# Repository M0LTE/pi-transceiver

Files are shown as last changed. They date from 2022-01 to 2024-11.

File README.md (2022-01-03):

# pi-transceiver
An attempt to build a complete ham radio transceiver around a Raspberry Pi



See [the wiki](https://github.com/M0LTE/pi-transceiver/wiki) for a more detailed project description / scratchlist of ideas / plans.

Also see [the open issues](https://github.com/M0LTE/pi-transceiver/issues) for stuff which needs working on. I've marked a few as Good First Issues.

[Discussions](https://github.com/M0LTE/pi-transceiver/discussions) is also a good place to ask questions / make comments / suggestions without raising an issue.

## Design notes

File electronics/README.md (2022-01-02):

# pi-transceiver / electronics
Here is a folder for electronics parts of the Pi transceiver, e.g. PCBs

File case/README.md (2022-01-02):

# pi-transceiver / case
Here is a folder for the case, which is intended to be 3D-printable.

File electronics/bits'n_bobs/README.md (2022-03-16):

# Bits'n_bobs
This is a collection of small prototype modules and breakout boards to test various devices and features for the Pi Transceiver and similar projects.

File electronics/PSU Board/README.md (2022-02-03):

# pi-transceiver / electronics / PCB Board
Here is a the PSU board. 13.8V input with over voltage an reverse polarity protection and multiple outputs.
Momentary switch connection for power on.
Multiple shutdown connections to enable Raspberry Pi to switch off the power and also allow any other monitoring systems to cut the power.
5V buck converter to supply power to the Raspberry Pi.
Low current permanent 5V supply (not over voltage protected) to power 3rd party modules which have the ability to directly power the system on and off.

Mouser Parts List
https://www.mouser.com/ProjectManager/ProjectDetail.aspx?AccessID=8b7ab50ecd

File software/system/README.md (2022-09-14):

# pi-transceiver / software / system
Here is a folder for scripts etc to build the system 
Notes added by G4CDF based on experience following these instructions

## Install notes 2022-02-09

Complete from-the-ground-up build of a working system.

It is highly recommended to copy-paste these commands into a remote connection rather than typing them in by hand on the Pi.
G4CDF> To paste into PuTTY just right click on the line rather than the usual CTRL V.

This will result in a system without a graphical desktop interface, which is the same as how the system will run once the radio software is installed.

### Prepare the micro SD card
1. Download latest Raspberry Pi Imager https://www.raspberrypi.com/software/
1. Choose OS -> Raspberry Pi OS (other) -> Raspberry Pi OS Lite (32-bit) - Bullseye 2022-01-28

G4CDF> I installed the full 32 bit version to a 32 GB SD card

1. Choose storage -> pick micro SD card, which you have inserted
1. Click the Cog icon
   1. Set hostname: e.g. pi-transceiver
   1. Enable SSH, use password auth
   1. Set username and password - pick whatever you want
   1. Configure wi-fi if desired
   1. Click save
1. Click Write, then click Yes, and wait

G4CDF>  These settings can be made on the Raspberry PI GUI  

### First boot

1. Plug in a network cable if you didn't configure Wi-Fi
1. Plug in a screen - either the official touchscreen or an HDMI monitor
1. Insert the micro SD card
1. Power up the Pi
1. Wait until you see a login prompt
1. Connect to the Pi using your favourite SSH client. PuTTY is fine on Windows. Log in using the username and password you set earlier. The default username is "pi"
1. Issue the command `sudo apt update; sudo apt full-upgrade -y` and wait until completion

G4CDF>  SSH will not work with host name only IP address

### Install GNU Radio and LimeSDR components

There is no GNU Radio PPA for Raspberry Pi OS either for Buster or Bullseye as it stands.

1. Install GNU Radio by issuing the command:

```
sudo apt install gnuradio -y
```

2. Install LimeSuite by issuing the commands:
```
sudo apt install -y git g++ cmake libsqlite3-dev libsoapysdr-dev libi2c-dev libusb-1.0-0-dev
cd ~
git clone https://github.com/myriadrf/LimeSuite.git
cd LimeSuite
git checkout stable
mkdir builddir && cd builddir
cmake ../
make -j4
sudo make install
sudo ldconfig
cd ~/LimeSuite/udev-rules
sudo ./install.sh
```

3. Install the LimeSDR plugin for GNU Radio by issuing the commands:

```
cd ~
git clone https://github.com/myriadrf/gr-limesdr.git
cd gr-limesdr
git checkout gr-3.8
mkdir build
cd build
cmake ..
make
sudo make install
sudo ldconfig
```

### Install .NET 6

1. Issue the command

```
wget -O - https://raw.githubusercontent.com/pjgpetecodes/dotnet6pi/master/install.sh | sudo bash
```
2. Reboot by issuing the command `sudo reboot`
3. Connect back up to the Pi using SSH once it has rebooted

### Enable I2C

I2C is not enabled by default. Enable it by running `sudo raspi-config` on the Pi, then selecting Interface Options, I2C, Enable. No need to reboot.

### Run the rig controller software

To fetch a working copy of the software:

```
cd ~
git clone https://github.com/M0LTE/pi-transceiver.git
```

To update the software:

```
cd ~/pi-transceiver
git pull
```

To run the software in the foreground (NB there will be no touchscreen UI since the screen will be used for console output - useful for debugging):

```
cd ~/pi-transceiver/software/rig-controller/rig-controller/
dotnet run
```

Then on a second computer on the same network, open http://pi-transceiver:5155 in a web browser. You'll get the radio UI.

G4CDF>  Windows 10 machine cannt see the Raspberry PI for some reason.

NOTE: as above - in the final product, this radio UI will be on the touchscreen.

Instructions on setting up the software to run in the background and display the UI on the touchscreen (or HDMI monitor) will follow.

## Hardware

- When connecting the official touchscreen, the only connections should be VCC, ground, and the ribbon cable. Nothing more. Else you are bridging two I2C buses which will have unpredictable effects.

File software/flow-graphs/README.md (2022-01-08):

# pi-transceiver / software / flow-graphs

SSB_TX.grc is the most basic audio capture -> SSB transmitter I can conceive of in GNU Radio. It can be loaded into GNU Radio Companion 3.8 with gr-limesdr installed. Just set the lime_serial variable (block) value to the serial number of your own LimeSDR, found by running `LimeUtil --find` at the terminal. Click Run, and you'll find a signal at 144.400MHz USB +/- calibration. 

Default gain is 60 (who knows what units), frequency is set in the LimeSDR block.

Tested on Ubuntu 20.04 + GNU Radio installed by following [these (Installing via PPA) instructions](https://github.com/myriadrf/gr-limesdr#linux)

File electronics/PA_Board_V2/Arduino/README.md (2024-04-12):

# Arduino Support for Pi Transciever PA Board
# Arduino Support for Pi Transciever PA Board

The Pi Transceiver PA board is programmed under the Arduino IDE environment with Arduino Libraries

## Test programs

    - Blink - Basic test to verify CPU operation with RGB LED and watchdog LED

    - I2C Scanner - Find I2c devices on Internal and External I2C buses

    - OLED Test - Test of optional I2C OLED display

    - Temperature - Show temperature of LM75B sensor

    - Power_Tests - Test Vdd, Idd, Vgg Monitor
    
    - fan_PWM - test speed control of fan

    - USB_Commander - a command interpreter interface to set and read all parameters of the PA and receiver boards

## Libraries Used

    - "FlashStorage_SAMD"  used to support non voltaile storage from application into Flash memory as there is no EEPROM on ATSAMD21E18

    - "Adafruit_INA219" used to support the INA219 voltage and current sensor for Vdd and Idd to the RF Block

    - "Adafruit_MCP4725" used to support the DAC used to set the Vgg voltage

    - "Commander" used to provide command interpreter function on USB or TTL Serial port

    - "Adafruit_Neopixel"  used to support the onboard DotStar RGB LED

    - "Temperature_LM75_Derived" used to support the onboard LM75B temperature sensor

    - "Adafruit_SSD1306" and "Adafruit GFX" are Used to support the optional 128 * 64 pixel monochrome I2C LCD display

    - "PCF8574" is used to support the receiver board I2C interface IC

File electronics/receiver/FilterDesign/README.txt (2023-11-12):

This folder contains the design of the filter within the Receiver PCB, including documents used to design and simulate the band pass flter.

The filter is a 4 pole band pass filter covering 144 to 147 MHz and is used on both transmit and receive

It is designed using the book by Zverev entitled Handbook of Filter Synthesis.  An Excel spreadsheet is used to calculate the values and it provides output to QUCS and Kicad.

Note for QUCS the output worksheet is save in .prn format and this is then renamed to .sch.  It is necessary for filter.dpl to be put in gitignore if using git.
When siluation is completed export the schematic and simualtion results.

Currently the values are input to Kicad manually.

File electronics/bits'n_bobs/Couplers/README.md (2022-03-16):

# Coupler

Directional coupler modules to test different options for the Pi Transceiver

The coupler is a short PCB directional coupler using Guerilla GRF1201 detctors

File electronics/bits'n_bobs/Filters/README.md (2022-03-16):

# Filters

A selection of Filter modules to test different options for the Pi Transceiver

The Filters are:

* RBP-140+ - A breakout for the Minicircuits RBP-140+ bandpass filter module
* Broadcast_filter - A copy of the broadcast notch filter used in the Line RFE board
* LowPass_7mm - Low pass transmit filter using hand would coils
* LowPass_10mm - Low pass filter using Toko coil formers

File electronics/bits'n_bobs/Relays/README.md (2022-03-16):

# Relays

A selection of Relay modules to test different options for the Tx/Rx relay for the Pi Transceiver

Relay Options are:

* G2RL Large through hole relay recommended by W6PQL
* HF3 Surface mount relay recommended by W6PQL
* EE2 Surface mount relay used in Lime RFE and IC-9700
* G6E Through hole relay used in Elecraft XV144

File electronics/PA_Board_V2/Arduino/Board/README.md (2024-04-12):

# Board Files for Pi Transciever PA Board

The Arduino environment uses board files and variants to configure for different processors and board pinouts.
We use the board files for the Adafruit SAMD boards and modify to add Pi transceiver board. (This is a bit messy and could be improved with proper custom board files when stable)

## Installation

- Install the latest arduino IDE: [Install IDE 2](https://docs.arduino.cc/software/ide-v2/tutorials/getting-started/ide-v2-downloading-and-installing)

- Install the Adafruit SAMD board support into Arduino board manager [Adafruit SAMD](https://learn.adafruit.com/adafruit-trinket-m0-circuitpython-arduino/arduino-ide-setup)

- Install the Adafruit SAMD boards inside Arduino Board Manager [Board Manager](https://learn.adafruit.com/adafruit-trinket-m0-circuitpython-arduino/using-with-arduino-ide) Follow this tutorial until the point where you have reboted the PC then stop.

- Find where the board files have been installed. There will be a directory like this "C:\Users\'your_user_name'\AppData\Local\Arduino15\packages\adafruit\hardware\samd\1.7.10" which contains a file "boards.txt" and "variants" directory.

- Replace the "boards.txt" file in the directory found above with the one in this Github directory.

- Add the "Pi_Tx_PA" and the "Pi_Tx_PA_V2" directories from the "Board/variants" of this Github repository. into the variants directory found above.

- Restart PC and open Arduino IDE

- Plug in Pi Transceiver PA board to PC using USB connection. PC should enumerate the board.

- Select Board type as RADARC Pi_Tx_PA under "tools/board/Adafruit SAMD"

- Select the Comport which shows the RADARC Pi_Tx_PA connected

- Add the additional Arduino Libraries listed in the READ_ME if not already installed.

-  Compile and Upload code or tests from this Github repository

## Issues

1.  If you subsequently update the Adafruit Boards in board manager then the "boards.txt" will most likely be changed by the update and the steps above to replace the boards.txt with our version will have to done again. Best to not update the Adafruit SAMD boards when offered.

2. The Pi_Tx_PA has the same USB VID and PID as the Adafruit Trinket M0 and the Adafruit PiRkey (SAMD) which means the serial port often needs to be reset to the correct COM Port. This may be fixed by Arduino/Adafruit or may been a custom bootlodare with unique VID PID

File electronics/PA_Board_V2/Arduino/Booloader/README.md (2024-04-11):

# Bootloader for Pi Transciever PA Board

The Bootloader for the Atmel ATSAMD21E18 processor is the same bootloader used on the Adafruit Trinket M0 which uses the same processor

The .bin file bootloader file is programmed into the ATSAMD21E18 using Atmel Studio and an Atmel ICE or similar SWD programmer. The connection to the debug pins on the PA Board is made using a 3d printed programming clip with pogo pins.

The Bootloader area should be locked after programming.
    After flashing, you'll need to set the BOOTPROT fuse back to a 8kB bootloader size.
    From Fuses, set BOOTPROT to 0x2 or 8KB and click Program

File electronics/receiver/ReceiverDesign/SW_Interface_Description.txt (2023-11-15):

Software Interface Description for Pi-transcever Reeciver Module

Control of the receiver module (Rx Module) is via the I2C bus.

The Rx Module is an I2C bus slave.  The device used is a PCF8574AT, Datasheet is in /datasheets as PCF8574_PCF8574A-3139141.

Address=  01110000 

Data=  Data_gain OR Data_Tx_state

Data_gain=  00000001 (Rx_gain = 13dB)
Data_gain=  00000010  (Rx_gain = -10 dB)

For LimeSDR Mini:

Data_Tx_state=  00011000 (Transmit state)
Data_Tx_state=  00100100 (Receive state)

For Caribou Lite:

Data_Tx_state=  00011000 (Transmit state)
Data_Tx_state=  00010100  (Receive state)

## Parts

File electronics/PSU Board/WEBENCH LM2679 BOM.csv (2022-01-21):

Part | Manufacturer | Part Number | Quantity | Price ($) | Footprint (mm²) | Description
Rilim | Vishay-Dale | CRCW04024K99FKED | 1 | 0.01 | 3 | Resistance: 4.99 kΩ Tolerance: 1.0% Power: 63 mW
Rfb1 | Vishay-Dale | CRCW04021K00FKED | 1 | 0.01 | 3 | Resistance: 1 kΩ Tolerance: 1.0% Power: 63 mW
Rfb2 | Vishay-Dale | CRCW04023K24FKED | 1 | 0.01 | 3 | Resistance: 3.24 kΩ Tolerance: 1.0% Power: 63 mW
Cout | Panasonic | 16SVP330M | 1 | 0.4 | 159.9 | Cap: 330 µF Total Derated Cap: 330 µF VDC: 16 V ESR: 16 mΩ Package: 10x12.6
D1 | SMC Diode Solutions | SBRD10200TR | 1 | 0.12 | 101.71 | Type: Schottky VRRM: 200 V Io: 10 A
Cb | TDK | CGA4C2C0G1H103J060AA | 1 | 0.06 | 6.75 | Cap: 10 nF Total Derated Cap: 10 nF VDC: 50 V ESR: 0 Ω Package: 0805
L1 | Bourns | SRP1270-100M | 1 | 0.72 | 246.49 | L: 10 µH DCR: 16.8 mΩ IDC: 10 A
Cinx | Kemet | C0805C104M5RACTU | 1 | 0.01 | 6.75 | Cap: 100 nF Total Derated Cap: 100 nF VDC: 50 V ESR: 64 mΩ Package: 0805
U1 | Texas Instruments | LM2679SX-ADJ/NOPB | 1 | 2.481 | 198.82
Cin | Panasonic | 25SVPF180M | 1 | 0.63 | 106.09 | Cap: 180 µF Total Derated Cap: 180 µF VDC: 25 V ESR: 16 mΩ Package: 8x11.9
Css | TDK | CGA4C2C0G1H103J060AA | 1 | 0.06 | 6.75 | Cap: 10 nF Total Derated Cap: 10 nF VDC: 50 V ESR: 0 Ω Package: 0805

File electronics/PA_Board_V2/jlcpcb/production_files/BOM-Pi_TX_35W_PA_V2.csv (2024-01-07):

Comment | Designator | Footprint | LCSC
LRB751S | D11,D12,D2,D3 | D_SOD-523 | C113407
USB_B_Micro | J9 | USB_Micro-B_Molex-105017-0001 | C136000
INA219AxD | U10 | SOIC-8_3.9x4.9mm_P1.27mm | C138706
1.5u | L10,L8 | L_0805_2012Metric | C139220
MCP4725 | U7 | SOT-23-6 | C144198
G6E | K1 | Relay_SPDT_Omron_G6E | C1525391
1u 50V | C26 | C_0603_1608Metric | C15849
22u | C13 | CP_EIA-7343-43_Kemet-X | C1956447
TPS22810DBV | U8 | SOT-23-6 | C205990
1k | R14,R42,R44 | R_0603_1608Metric | C21190
10n | C55,C56,C60 | C_0603_1608Metric | C2215227
1k2 | R12 | R_0603_1608Metric | C22765
150R | R22,R23,R38,R40 | R_0603_1608Metric | C22808
10R | R7,R8 | R_0603_1608Metric | C22859
1M | R43 | R_0603_1608Metric | C22935
330R | R30,R37 | R_0603_1608Metric | C23138
4k7 | R1,R16,R18,R24,R25,R28,R35,R45,R5,R6 | R_0603_1608Metric | C23162
470R | R13 | R_0603_1608Metric | C23179
49.9k | R41 | R_0603_1608Metric | C23184
49.9R | R39 | R_0603_1608Metric | C23185
18R | R2,R49 | R_0603_1608Metric | C245924
100k | R29,R31,R32,R34 | R_0603_1608Metric | C25803
10k | R10,R11,R15,R19,R26,R27,R33,R36,R46,R47 | R_0603_1608Metric | C25804
47k | R21 | R_0603_1608Metric | C25819
22.1k | R17 | R_0603_1608Metric | C25961
AP2204K-ADJ | U9 | SOT-23-5 | C264072
SP0503BAHT | D1,D5,D8 | SOT-143 | C2682275
TLV70233 | U11 | SOT-23-5 | C26833
1n | C35,C36,C43,C47,C50,C51 | C_0603_1608Metric | C2839443
150mA | F2,F3,F4 | Fuse_0805_2012Metric | C2840556
200nH | L4 | L_1812_4532Metric | C2858475
SK6812 | D14,D15 | SK6812SIDE-A-RVS | C2890037
300R | R3,R4,R48,R50 | R_0603_1608Metric | C2930092
LM2904 | U12 | SOIC-8_3.9x4.9mm_P1.27mm | C2941725
100p | C1,C11,C16,C59,C7 | C_0603_1608Metric | C296046
162k | R20 | R_0603_1608Metric | C3016073
MBR0540 | D4,D7,D9 | D_SOD-123 | C3018524
2.2u 50V | C23 | C_0805_2012Metric | C377773
330p | C3,C5,C64,C9 | C_0603_1608Metric | C458903
Conn_Coaxial | J1,J5,J7,J8 | SMA_Samtec_SMA-J-P-X-ST-EM1_EdgeMount | C496550
74LV1T34 | U15,U5 | SOT-353_SC-70-5 | C5199768
PSA4-5043+ | U1,U3 | MM1362 PSA4-5043+ | C5240848
AOD4185 | Q1 | TO-252-2 | C5261064
SW_Push | SW1 | Panasonic_EVQPUK_EVQPUB | C526225
LMR51420 | U6 | SOT-23-6 | C5383002
BC848W | Q2 | SOT-323_SC-70 | C549496
4n7 | C53 | C_0603_1608Metric | C576815
2.2u | C22 | C_0603_1608Metric | C57895
22u | C31,C6 | C_0805_2012Metric | C602037
ATSAMD21E18A-A | U13 | TQFP-32_7x7mm_P0.8mm | C618770
1SS400 | D10,D17,D6 | D_SOD-523 | C68951
MHS171CRCT | D16 | MHS171 | C693903
MHS171UBCT | D13 | MHS171 | C693906
1u | L1,L11,L12,L13,L2 | L_0805_2012Metric | C703134
LM75B | U2 | SOIC-8_3.9x4.9mm_P1.27mm | C725792
Conn_01x05 | J3 | JST_PH_S5B-PH-SM4-TB_1x05-1MP_P2.00mm_Horizontal | C7429692
Conn_01x06 | J6 | JST_PH_S6B-PH-SM4-TB_1x06-1MP_P2.00mm_Horizontal | C7429693
4.7uH | L5 | L_7.3x7.3_H3.5 | C76857
10m | R9 | R_2816_7142Metric | C843884
100n | C10,C14,C17,C18,C2,C21,C24,C25,C27,C28,C29,C30,C38,C39,C4,C42,C45,C46,C48,C54,C58,C8 | C_0603_1608Metric | C88136
1u | C37,C40,C44,C52,C57 | C_0603_1608Metric | C89376
1A | F1 | Fuse_1206_3216Metric | C910830
10u | C41,C49 | C_0603_1608Metric | C96446
L_Ferrite | L9 | L_0603_1608Metric | C98298

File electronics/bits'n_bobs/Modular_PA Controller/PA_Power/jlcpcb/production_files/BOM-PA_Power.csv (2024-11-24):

Comment | Designator | Footprint | LCSC
MountingHole_Pad | H5 | MountingHole_3.2mm_M3_DIN965_Pad
NF | R25 | R_0603_1608Metric
82R | R8 | R_0603_1608Metric
1uH | L9 | L_0805_2012Metric
1A | F4 | Fuse_1812_4532Metric
JST-XH-4 | J5 | JST_XH_S4B-XH-A_1x04_P2.50mm_Horizontal
FDN340P | Q5 | SOT-23
JST-XH-4 | J6 | JST_XH_S4B-XH-A_1x04_P2.50mm_Horizontal
100n | C25 | C_0603_1608Metric
0R | R32 | R_0603_1608Metric
100n | C22 | C_0603_1608Metric
10k | TH1 | R_0603_1608Metric
1k8 | R34 | R_0603_1608Metric
AP2204K-ADJ | U7 | SOT-23-5
1A | F1 | Fuse_Schurter_UMZ250
15uH | L1 | L_Wuerth_MAPI-4030
NF | R24 | R_0603_1608Metric
LMR38020 | U3 | lmr38012
PCF8574A | U8 | SOIC-16W_7.5x10.3mm_P1.27mm
4k7 | R27 | R_0603_1608Metric
10k | R37 | R_0603_1608Metric
1uH | L8 | L_0805_2012Metric
Green | D4 | LED_0603_1608Metric
64k9 | R3 | R_0603_1608Metric
1uH | L6 | L_0805_2012Metric
2.2u | C7 | C_1210_3225Metric
SQM120P10-19L | Q3 | TO263_Heatsink_301
82R | R9 | R_0603_1608Metric
10k | R7 | R_0603_1608Metric
100n | C16 | C_0603_1608Metric
100n | C20 | C_0603_1608Metric
JST-XH-2 | J7 | JST_XH_S2B-XH-A_1x02_P2.50mm_Horizontal
NF | R31 | R_0603_1608Metric
10k | R30 | R_0603_1608Metric
ADS1015IDGS | U5 | TSSOP-10_3x3mm_P0.5mm
110k | R15 | R_0603_1608Metric
1k | R5 | R_0603_1608Metric
60A 4 Pin | J4 | Fat_Power 4
10k | R36 | R_0603_1608Metric
1uH | L4 | L_0805_2012Metric
100nf | C8 | C_0603_1608Metric
2.2u | C6 | C_1210_3225Metric
10K | R4 | R_0603_1608Metric
1k | R28 | R_0603_1608Metric
100nf | C9 | C_0603_1608Metric
100n | C3 | C_0805_2012Metric
2.2u | C4 | C_0603_1608Metric
100n | C24 | C_0603_1608Metric
100n | C29 | C_0603_1608Metric
22.1k | R14 | R_0603_1608Metric
22u | C11 | C_1210_3225Metric
MountingHole_Pad | H2 | MountingHole_3.2mm_M3_DIN965_Pad
22.1k | R11 | R_0603_1608Metric
100k | R13 | R_0603_1608Metric
4k7 | R6 | R_0603_1608Metric
SMF4L5.0A | D13 | D_SOD-123F
60A 4 pin | J1 | Fat_Power 4
0R | R20 | R_0603_1608Metric
270k | R1 | R_0603_1608Metric
33uH | L3 | L_Coilcraft_MSS1210-XXX
100n | C21 | C_0603_1608Metric
NF | R19 | R_0603_1608Metric
10k | R16 | R_0603_1608Metric
1k | R17 | R_0603_1608Metric
1uH | L7 | L_0805_2012Metric
2.2u | C5 | C_0603_1608Metric
LMR50410 | U2 | SOT-23-6
1k | R21 | R_0603_1608Metric
ACS770xCB-050B-PFF | U4 | Allegro_CB_PFF
4k7 | R23 | R_0603_1608Metric
SMF4L5.0A | D8 | D_SOD-123F
MCP4725A0T | U6 | SOT-23-6
SMF4L12A | D9 | D_SOD-123F
LMR50410 | U1 | SOT-23-6
10k | R35 | R_0603_1608Metric
SMF4L5.0A | D7 | D_SOD-123F
SM6T75A | D1 | D_SMB
162k | R10 | R_0603_1608Metric
100n | C14 | C_0603_1608Metric
10k | R18 | R_0603_1608Metric
10k | R2 | R_0603_1608Metric
1A | F2 | Fuse_1812_4532Metric
MountingHole_Pad | H3 | MountingHole_3.2mm_M3_DIN965_Pad
100n | C26 | C_0603_1608Metric
100n | C30 | C_0603_1608Metric
JST-PH-4 | J3 | JST_PH_B4B-PH-SM4-TB_1x04-1MP_P2.00mm_Vertical
15uH | L2 | L_Wuerth_MAPI-4030
1k8 | R29 | R_0603_1608Metric
100n | C23 | C_0603_1608Metric
4k7 | R22 | R_0603_1608Metric
BSS123 | Q1 | SOT-23
1A | F5 | Fuse_1812_4532Metric
JST-PH-4 | J8 | JST_PH_B4B-PH-SM4-TB_1x04-1MP_P2.00mm_Vertical
100nf | C10 | C_0603_1608Metric
1k | R33 | R_0603_1608Metric
100n | C15 | C_0603_1608Metric
MountingHole_Pad | H4 | MountingHole_3.2mm_M3_DIN965_Pad
0R | R26 | R_0603_1608Metric
100k | R12 | R_0603_1608Metric
30A 2 Pin | J2 | Fat_Power 2
100n | C1 | C_0603_1608Metric
1A | F3 | Fuse_1812_4532Metric
1uH | L5 | L_0805_2012Metric
22u | C17 | C_1210_3225Metric
100n | C2 | C_0603_1608Metric
MountingHole_Pad | H1 | MountingHole_3.2mm_M3_DIN965_Pad
JST-PH-3 | J9 | JST_PH_S3B-PH-SM4-TB_1x03-1MP_P2.00mm_Horizontal
SQM120P10-19L | Q2 | TO263_Heatsink_301
BSS123 | Q4 | SOT-23
15v | D2 | Nexperia_CFP3_SOD-123W
SMF4L12A | D14 | D_SOD-123F
Yellow | D12 | LED_0603_1608Metric
SP0503BAHT | D11 | SOT-143
Blue | D10 | LED_0603_1608Metric
SMF4L12A | D6 | D_SOD-123F
SM6T75A | D5 | D_SMB
Red | D3 | LED_0603_1608Metric
100n | C28 | C_0603_1608Metric
22u | C27 | C_0805_2012Metric
22u | C18 | C_1210_3225Metric
100n | C19 | C_0603_1608Metric
22u | C12 | C_1210_3225Metric
100n | C13 | C_0603_1608Metric

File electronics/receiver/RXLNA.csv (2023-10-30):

Source: | C:\Users\micha\SynologyDrive\Documents\KICAD\Projects\RXLNA\RXLNA.kicad_sch
Date: | 21/10/2023 12:44
Tool: | Eeschema (6.0.9)
Generator: | C:\Program Files\KiCad\6.0\bin\scripting\plugins/bom_csv_grouped_by_value.py
Component Count: | 86
Individual Components:
Item | Qty | Reference(s) | Value | LibPart | Footprint | Datasheet
 |  | C401 | C | Device:C | Capacitor_SMD:C_0805_2012Metric | ~
 |  | C402 | C | Device:C | Capacitor_SMD:C_0805_2012Metric | ~
 |  | C403 | C | Device:C | Capacitor_SMD:C_0805_2012Metric | ~
 |  | C404 | C | Device:C | Capacitor_SMD:C_0805_2012Metric | ~
 |  | C405 | C | Device:C | Capacitor_SMD:C_0805_2012Metric_Pad1.18x1.45mm_HandSolder | ~
 |  | C406 | C | Device:C | Capacitor_SMD:C_0805_2012Metric_Pad1.18x1.45mm_HandSolder | ~
 |  | C407 | C | Device:C | Capacitor_SMD:C_0805_2012Metric_Pad1.18x1.45mm_HandSolder | ~
 |  | C408 | C | Device:C | Capacitor_SMD:C_0805_2012Metric_Pad1.18x1.45mm_HandSolder | ~
 |  | C409 | C | Device:C | Capacitor_SMD:C_0805_2012Metric_Pad1.18x1.45mm_HandSolder | ~
 |  | C410 | C | Device:C | Capacitor_SMD:C_0805_2012Metric | ~
 |  | C411 | C | Device:C | Capacitor_SMD:C_0805_2012Metric_Pad1.18x1.45mm_HandSolder | ~
 |  | C412 | C | Device:C | Capacitor_SMD:C_0805_2012Metric | ~
 |  | C413 | C | Device:C | Capacitor_SMD:C_0805_2012Metric_Pad1.18x1.45mm_HandSolder | ~
 |  | C414 | C | Device:C | Capacitor_SMD:C_0805_2012Metric_Pad1.18x1.45mm_HandSolder | ~
 |  | C415 | C | Device:C | Capacitor_SMD:C_0805_2012Metric | ~
 |  | C416 | C | Device:C | Capacitor_SMD:C_0805_2012Metric | ~
 |  | C417 | C | Device:C | Capacitor_SMD:C_0805_2012Metric | ~
 |  | C418 | C | Device:C | Capacitor_SMD:C_0805_2012Metric | ~
 |  | C419 | C | Device:C | Capacitor_SMD:C_0805_2012Metric | ~
 |  | C420 | C | Device:C | Capacitor_SMD:C_0805_2012Metric | ~
 |  | C421 | C | Device:C | Capacitor_SMD:C_0805_2012Metric | ~
 |  | C422 | C | Device:C | Capacitor_SMD:C_0805_2012Metric_Pad1.18x1.45mm_HandSolder | ~
 |  | C423 | C | Device:C | Capacitor_SMD:C_0805_2012Metric_Pad1.18x1.45mm_HandSolder | ~
 |  | C424 | C | Device:C | Capacitor_SMD:C_0805_2012Metric_Pad1.18x1.45mm_HandSolder | ~
 |  | C425 | C | Device:C | Capacitor_SMD:C_0603_1608Metric_Pad1.08x0.95mm_HandSolder | ~
 |  | C426 | C | Device:C | Capacitor_SMD:C_0603_1608Metric_Pad1.08x0.95mm_HandSolder | ~
 |  | C427 | C | Device:C | Capacitor_SMD:C_0603_1608Metric_Pad1.08x0.95mm_HandSolder | ~
 |  | C428 | C | Device:C | Capacitor_SMD:C_0603_1608Metric_Pad1.08x0.95mm_HandSolder | ~
 |  | C429 | C_Trim | Device:C_Trim | G4CDF:TrimCap | ~
 |  | C430 | C | Device:C | Capacitor_SMD:C_0603_1608Metric_Pad1.08x0.95mm_HandSolder | ~
 |  | C431 | C | Device:C | Capacitor_SMD:C_0603_1608Metric_Pad1.08x0.95mm_HandSolder | ~
 |  | C432 | C | Device:C | Capacitor_SMD:C_0603_1608Metric_Pad1.08x0.95mm_HandSolder | ~
 |  | C433 | C | Device:C | Capacitor_SMD:C_0603_1608Metric_Pad1.08x0.95mm_HandSolder | ~
 |  | C434 | C_Trim | Device:C_Trim | G4CDF:TrimCap | ~
 |  | C435 | C | Device:C | Capacitor_SMD:C_0603_1608Metric_Pad1.08x0.95mm_HandSolder | ~
 |  | C436 | C | Device:C | Capacitor_SMD:C_0603_1608Metric_Pad1.08x0.95mm_HandSolder | ~
 |  | C437 | C | Device:C | Capacitor_SMD:C_0603_1608Metric_Pad1.08x0.95mm_HandSolder | ~
 |  | C438 | C | Device:C | Capacitor_SMD:C_0603_1608Metric_Pad1.08x0.95mm_HandSolder | ~
 |  | C439 | C_Trim | Device:C_Trim | G4CDF:TrimCap | ~
 |  | C440 | C | Device:C | Capacitor_SMD:C_0603_1608Metric_Pad1.08x0.95mm_HandSolder | ~
 |  | C441 | C | Device:C | Capacitor_SMD:C_0603_1608Metric_Pad1.08x0.95mm_HandSolder | ~
 |  | C442 | C | Device:C | Capacitor_SMD:C_0603_1608Metric_Pad1.08x0.95mm_HandSolder | ~
 |  | C443 | C | Device:C | Capacitor_SMD:C_0603_1608Metric_Pad1.08x0.95mm_HandSolder | ~
 |  | C444 | C_Trim | Device:C_Trim | G4CDF:TrimCap | ~
 |  | C445 | C | Device:C | Capacitor_SMD:C_0603_1608Metric_Pad1.08x0.95mm_HandSolder | ~
 |  | C446 | C | Device:C | Capacitor_SMD:C_0603_1608Metric_Pad1.08x0.95mm_HandSolder | ~
 |  | D401 | SMP1330-005LF | Device:D_Dual_Series_AKC_Parallel | Package_TO_SOT_SMD:SOT-23 | ~
 |  | J401 | Conn_Coaxial | Connector:Conn_Coaxial | Connector_Coaxial:SMA_Samtec_SMA-J-P-X-ST-EM1_EdgeMount | ~
 |  | J402 | Conn_Coaxial | Connector:Conn_Coaxial | Connector_Coaxial:SMA_Samtec_SMA-J-P-X-ST-EM1_EdgeMount | ~
 |  | J403 | Conn_Coaxial | Connector:Conn_Coaxial | Connector_Coaxial:SMA_Samtec_SMA-J-P-X-ST-EM1_EdgeMount | ~
 |  | J404 | Conn_01x06_Male | Connector:Conn_01x06_Male | Connector_PinHeader_2.54mm:PinHeader_1x06_P2.54mm_Vertical | ~
 |  | J405 | Conn_01x01_Male | Connector:Conn_01x01_Male | G4CDF:Board outline 100_100 | ~
 |  | J406 | Conn_Coaxial | Connector:Conn_Coaxial | Connector_Coaxial:SMA_Samtec_SMA-J-P-X-ST-EM1_EdgeMount | ~
 |  | J407 | Conn_Coaxial | Connector:Conn_Coaxial | Connector_Coaxial:SMA_Samtec_SMA-J-P-X-ST-EM1_EdgeMount | ~
 |  | L401 | L_Trim | Device:L_Trim | Inductor_THT:L_Radial_L10.2mm_W10.2mm_Px7.62mm_Py7.62mm_Pulse_LP-30 | ~
 |  | L402 | L | Device:L | Inductor_SMD:L_0805_2012Metric_Pad1.05x1.20mm_HandSolder | ~
 |  | L403 | L | Device:L | G4CDF:Pipe22 | ~
 |  | L404 | L | Device:L | G4CDF:Pipe22 | ~
 |  | L405 | L | Device:L | G4CDF:Pipe22 | ~
 |  | L406 | L | Device:L | G4CDF:Pipe22 | ~
 |  | R401 | R | Device:R | Resistor_SMD:R_0805_2012Metric_Pad1.20x1.40mm_HandSolder | ~
 |  | R402 | R | Device:R | Resistor_SMD:R_0805_2012Metric_Pad1.20x1.40mm_HandSolder | ~
 |  | R403 | R | Device:R | Resistor_SMD:R_0805_2012Metric_Pad1.20x1.40mm_HandSolder | ~
 |  | R404 | R | Device:R | Resistor_SMD:R_0805_2012Metric_Pad1.20x1.40mm_HandSolder | ~
 |  | R405 | R | Device:R | Resistor_SMD:R_0805_2012Metric_Pad1.20x1.40mm_HandSolder | ~
 |  | R406 | R | Device:R | Resistor_SMD:R_0805_2012Metric_Pad1.20x1.40mm_HandSolder | ~
 |  | R407 | R | Device:R | Resistor_SMD:R_0805_2012Metric_Pad1.20x1.40mm_HandSolder | ~
 |  | R408 | R | Device:R | Resistor_SMD:R_0805_2012Metric_Pad1.20x1.40mm_HandSolder | ~
 |  | R409 | R | Device:R | Resistor_SMD:R_0805_2012Metric_Pad1.20x1.40mm_HandSolder | ~
 |  | R410 | R | Device:R | Resistor_SMD:R_0805_2012Metric_Pad1.20x1.40mm_HandSolder | ~
 |  | R411 | R | Device:R | Resistor_SMD:R_0805_2012Metric_Pad1.20x1.40mm_HandSolder | ~
 |  | R412 | R | Device:R | Resistor_SMD:R_0805_2012Metric_Pad1.20x1.40mm_HandSolder | ~
 |  | R413 | R | Device:R | Resistor_SMD:R_0805_2012Metric_Pad1.20x1.40mm_HandSolder | ~
 |  | R414 | R | Device:R | Resistor_SMD:R_0805_2012Metric_Pad1.20x1.40mm_HandSolder | ~
 |  | R415 | R | Device:R | Resistor_SMD:R_0805_2012Metric_Pad1.20x1.40mm_HandSolder | ~
 |  | R416 | R | Device:R | Resistor_SMD:R_0805_2012Metric_Pad1.20x1.40mm_HandSolder | ~
 |  | R417 | R | Device:R | Resistor_SMD:R_0805_2012Metric_Pad1.20x1.40mm_HandSolder | ~
 |  | U401 | AS179-92LF | RF_Switch:AS179-92LF | Package_TO_SOT_SMD:SOT-363_SC-70-6 | http://www.skyworksinc.com/uploads/documents/AS179_92LF_200176H.pdf
 |  | U402 | AS179-92LF | RF_Switch:AS179-92LF | Package_TO_SOT_SMD:SOT-363_SC-70-6 | http://www.skyworksinc.com/uploads/documents/AS179_92LF_200176H.pdf
 |  | U403 | AMS1117-5.0 | Regulator_Linear:AMS1117-5.0 | Package_TO_SOT_SMD:SOT-223-3_TabPin2 | http://www.advanced-monolithic.com/pdf/ds1117.pdf
 |  | U404 | AS179-92LF | RF_Switch:AS179-92LF | Package_TO_SOT_SMD:SOT-363_SC-70-6 | http://www.skyworksinc.com/uploads/documents/AS179_92LF_200176H.pdf
 |  | U405 | AMS1117-3.3 | Regulator_Linear:AMS1117-3.3 | Package_TO_SOT_SMD:SOT-223-3_TabPin2 | http://www.advanced-monolithic.com/pdf/ds1117.pdf
 |  | U406 | PCF8574A | Interface_Expansion:PCF8574A | Package_SO:SOIC-16W_7.5x10.3mm_P1.27mm | http://www.nxp.com/documents/data_sheet/PCF8574_PCF8574A.pdf
 |  | U407 | AS179-92LF | RF_Switch:AS179-92LF | Package_TO_SOT_SMD:SOT-363_SC-70-6 | http://www.skyworksinc.com/uploads/documents/AS179_92LF_200176H.pdf
 |  | U408 | PSA4-5043 | RF_Amplifier:SPF5189Z | Package_TO_SOT_SMD:SOT-89-3 | www.qorvo.com/products/d/da001910
 |  | U409 | AS179-92LF | RF_Switch:AS179-92LF | Package_TO_SOT_SMD:SOT-363_SC-70-6 | http://www.skyworksinc.com/uploads/documents/AS179_92LF_200176H.pdf
Collated Components:
Item | Qty | Reference(s) | Value | LibPart | Footprint | Datasheet
1 | 13 | C401, C402, C403, C404, C410, C412, C415, C416, C417, C418, C419, C420, C421 | C | Device:C | Capacitor_SMD:C_0805_2012Metric | ~
2 | 11 | C405, C406, C407, C408, C409, C411, C413, C414, C422, C423, C424 | C | Device:C | Capacitor_SMD:C_0805_2012Metric_Pad1.18x1.45mm_HandSolder | ~
3 | 18 | C425, C426, C427, C428, C430, C431, C432, C433, C435, C436, C437, C438, C440, C441, C442, C443, C445, C446 | C | Device:C | Capacitor_SMD:C_0603_1608Metric_Pad1.08x0.95mm_HandSolder | ~
4 | 4 | C429, C434, C439, C444 | C_Trim | Device:C_Trim | G4CDF:TrimCap | ~
5 | 1 | D401 | SMP1330-005LF | Device:D_Dual_Series_AKC_Parallel | Package_TO_SOT_SMD:SOT-23 | ~
6 | 5 | J401, J402, J403, J406, J407 | Conn_Coaxial | Connector:Conn_Coaxial | Connector_Coaxial:SMA_Samtec_SMA-J-P-X-ST-EM1_EdgeMount | ~
7 | 1 | J404 | Conn_01x06_Male | Connector:Conn_01x06_Male | Connector_PinHeader_2.54mm:PinHeader_1x06_P2.54mm_Vertical | ~
8 | 1 | J405 | Conn_01x01_Male | Connector:Conn_01x01_Male | G4CDF:Board outline 100_100 | ~
9 | 1 | L401 | L_Trim | Device:L_Trim | Inductor_THT:L_Radial_L10.2mm_W10.2mm_Px7.62mm_Py7.62mm_Pulse_LP-30 | ~
10 | 1 | L402 | L | Device:L | Inductor_SMD:L_0805_2012Metric_Pad1.05x1.20mm_HandSolder | ~
11 | 4 | L403, L404, L405, L406 | L | Device:L | G4CDF:Pipe22 | ~
12 | 17 | R401, R402, R403, R404, R405, R406, R407, R408, R409, R410, R411, R412, R413, R414, R415, R416, R417 | R | Device:R | Resistor_SMD:R_0805_2012Metric_Pad1.20x1.40mm_HandSolder | ~
13 | 5 | U401, U402, U404, U407, U409 | AS179-92LF | RF_Switch:AS179-92LF | Package_TO_SOT_SMD:SOT-363_SC-70-6 | http://www.skyworksinc.com/uploads/documents/AS179_92LF_200176H.pdf
14 | 1 | U403 | AMS1117-5.0 | Regulator_Linear:AMS1117-5.0 | Package_TO_SOT_SMD:SOT-223-3_TabPin2 | http://www.advanced-monolithic.com/pdf/ds1117.pdf
15 | 1 | U405 | AMS1117-3.3 | Regulator_Linear:AMS1117-3.3 | Package_TO_SOT_SMD:SOT-223-3_TabPin2 | http://www.advanced-monolithic.com/pdf/ds1117.pdf
16 | 1 | U406 | PCF8574A | Interface_Expansion:PCF8574A | Package_SO:SOIC-16W_7.5x10.3mm_P1.27mm | http://www.nxp.com/documents/data_sheet/PCF8574_PCF8574A.pdf
17 | 1 | U408 | PSA4-5043 | RF_Amplifier:SPF5189Z | Package_TO_SOT_SMD:SOT-89-3 | www.qorvo.com/products/d/da001910

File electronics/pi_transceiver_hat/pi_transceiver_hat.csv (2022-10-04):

Source: | E:\Projects\Gash2\pi-transceiver\electronics\pi_transceiver_hat\pi_transceiver_hat.kicad_sch
Date: | 16/09/2022 10:26:36
Tool: | Eeschema (6.0.1)
Generator: | C:\Program Files\KiCad\6.0\bin\scripting\plugins/bom_csv_grouped_by_value_with_fp.py
Component Count: | 40
Ref | Qnty | Value | Cmp name | Footprint | Description | Vendor
C1, | 1 | 10uF | C_Polarized | Capacitor_SMD:CP_Elec_4x5.4 | Polarized capacitor
C2, C3, C4, C5, | 4 | 100nF | C | Capacitor_SMD:C_0805_2012Metric_Pad1.18x1.45mm_HandSolder | Unpolarized capacitor
H1, H2, H3, H4, | 4 | MountingHole_Pad | MountingHole_Pad | MountingHole:MountingHole_2.7mm_M2.5 | Mounting Hole with connection
J1, | 1 | Raspberry_Pi_2_3 | Raspberry_Pi_2_3 | Connector_PinSocket_2.54mm:PinSocket_2x20_P2.54mm_Vertical | expansion header for Raspberry Pi 2 & 3
J2, | 1 | GND | Screw_Terminal_01x04 | TerminalBlock_TE-Connectivity:TerminalBlock_TE_282834-4_1x04_P2.54mm_Horizontal | Generic screw terminal, single row, 01x04, script generated (kicad-library-utils/schlib/autogen/connector/)
J3, | 1 | RX Board | Screw_Terminal_01x05 | TerminalBlock_TE-Connectivity:TerminalBlock_TE_282834-5_1x05_P2.54mm_Horizontal | Generic screw terminal, single row, 01x05, script generated (kicad-library-utils/schlib/autogen/connector/)
J4, | 1 | 1 wire | Conn_01x03_Male | TerminalBlock_TE-Connectivity:TerminalBlock_TE_282834-3_1x03_P2.54mm_Horizontal | Generic connector, single row, 01x03, script generated (kicad-library-utils/schlib/autogen/connector/)
J5, | 1 | PSU Board | Screw_Terminal_01x04 | TerminalBlock_TE-Connectivity:TerminalBlock_TE_282834-4_1x04_P2.54mm_Horizontal | Generic screw terminal, single row, 01x04, script generated (kicad-library-utils/schlib/autogen/connector/)
J6, | 1 | +5V | Screw_Terminal_01x04 | TerminalBlock_TE-Connectivity:TerminalBlock_TE_282834-4_1x04_P2.54mm_Horizontal | Generic screw terminal, single row, 01x04, script generated (kicad-library-utils/schlib/autogen/connector/)
J7, | 1 | UART | Conn_01x03_Male | Connector_JST:JST_XH_B3B-XH-A_1x03_P2.50mm_Vertical | Generic connector, single row, 01x03, script generated (kicad-library-utils/schlib/autogen/connector/)
J8, | 1 | +3.3V | Screw_Terminal_01x04 | TerminalBlock_TE-Connectivity:TerminalBlock_TE_282834-4_1x04_P2.54mm_Horizontal | Generic screw terminal, single row, 01x04, script generated (kicad-library-utils/schlib/autogen/connector/)
J9, | 1 | PA Board | Screw_Terminal_01x04 | TerminalBlock_TE-Connectivity:TerminalBlock_TE_282834-4_1x04_P2.54mm_Horizontal | Generic screw terminal, single row, 01x04, script generated (kicad-library-utils/schlib/autogen/connector/)
J10, | 1 | +5v Power | Conn_01x02 | TerminalBlock_TE-Connectivity:TerminalBlock_TE_282834-2_1x02_P2.54mm_Horizontal | Generic connector, single row, 01x02, script generated (kicad-library-utils/schlib/autogen/connector/)
J11, J12, J13, J14, | 4 | i2c | Conn_01x04_Male | Connector_JST:JST_XH_B4B-XH-A_1x04_P2.50mm_Vertical | Generic connector, single row, 01x04, script generated (kicad-library-utils/schlib/autogen/connector/)
J15, | 1 | Meter | Screw_Terminal_01x02 | TerminalBlock_TE-Connectivity:TerminalBlock_TE_282834-2_1x02_P2.54mm_Horizontal | Generic screw terminal, single row, 01x02, script generated (kicad-library-utils/schlib/autogen/connector/)
M1, | 1 | Fan 1 | Fan_4pin | Connector_Molex:Molex_KK-254_AE-6410-04A_1x04_P2.54mm_Vertical | Fan, tacho output, PWM input, 4-pin connector
M2, | 1 | Fan 2 | Fan_4pin | Connector_Molex:Molex_KK-254_AE-6410-04A_1x04_P2.54mm_Vertical | Fan, tacho output, PWM input, 4-pin connector
Q1, Q2, | 2 | 2N7000 | 2N7000 | Package_TO_SOT_SMD:SOT-23 | 0.2A Id, 200V Vds, N-Channel MOSFET, 2.6V Logic Level, TO-92
R1, R2, R4, R10, | 4 | 4.7K | R | Resistor_SMD:R_0805_2012Metric_Pad1.20x1.40mm_HandSolder | Resistor
R3, R5, R6, R7, | 4 | 10K | R | Resistor_SMD:R_0805_2012Metric_Pad1.20x1.40mm_HandSolder | Resistor
R8, R9, | 2 | 2K | R | Resistor_SMD:R_0805_2012Metric_Pad1.20x1.40mm_HandSolder | Resistor
R11, | 1 | 0R | R | Resistor_SMD:R_0805_2012Metric_Pad1.20x1.40mm_HandSolder | Resistor
U1, | 1 | MCP4725xxx-xCH | MCP4725xxx-xCH | Package_TO_SOT_SMD:SOT-23-6 | 12-bit Digital-to-Analog Converter, integrated EEPROM, I2C interface, SOT-23-6

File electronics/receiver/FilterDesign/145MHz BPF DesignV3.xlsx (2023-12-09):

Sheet: Cover
Design of VHF bandpass filters |  |  |  |  | Page
Design according to the Handbook of filter synthesis by Zverev
Input and Output impedance |  | 50 | ohm
Passband Ripple |  | 0 | dB
Filter Type |  | Butterworth
Freq at 1dB attenuation (Ω) |  | 0.85 |  |  | 82
Freq at 60 dB attenuation (Ω) |  | 5.6
BW | 1 dB | 3.4 | MHz
BW | 3 dB | 4
BW | 60dB | 22.4 | MHz
Centre freq |  | 145.5 | MHz | Example shown on p309
Norm | Ratio | 36.375 |  | https://archive.org/details/HandbookOfFilterSynthesis/page/n319/mode/2up
Number of resonators required |  | 4 |  | From Fig 5.1
Stopband rejection | 60dB |  | dB | Ch 3
L value (all L) | uH | 0.05458
Q Coil |  | 521.4863794
q0 achievable |  | 14.33639531
Series resistance | ohm | 0.09568079538
Cn | pF | 21.92246532
Qmin from Table |  | 0 |  | https://archive.org/details/HandbookOfFilterSynthesis/page/n319/mode/2up
Values from Tables
Insertion loss |  | 0.5357041967 | dB
Wire length |  | 83.35630279
Dia | mm | 8.7
Turns |  | 3
Ends |  | 0
Length | mm | 15
Calculation of Inductance and Qu | Note that this does not account for Helical resonator cover
https://hamwaves.com/inductance/en/index.html#input
QOIL™ — https://hamwaves.com/qoil/ — v20181217 |  |  |  |  |  | QOIL™ — https://hamwaves.com/qoil/ — v20181217 | QOIL™ — https://hamwaves.com/qoil/ — v20181217 | QOIL™ — https://hamwaves.com/qoil/ — v20181217
Coil design 2022-01-10 16:37 |  |  |  |  |  | Coil design 2022-01-17 13:25 | Coil design 2022-03-02 10:16 | Coil design 2022-03-10 13:45
 |  |  |  |  |  |  | INPUT | INPUT
INPUT |  |  |  |  |  | INPUT | mean diameter of the coil D = 8.7 mm | mean diameter of the coil D = 7.7 mm
mean diameter of the coil D = 7.25 mm |  |  |  |  |  | mean diameter of the coil D = 8.5 mm | number of turns N = 3 | number of turns N = 2
number of turns N = 3 |  |  |  |  |  | number of turns N = 3 | length of the coil ℓ = 15 mm | length of the coil ℓ = 15 mm
length of the coil ℓ = 7.25 mm |  |  |  |  |  | length of the coil ℓ = 14 mm | wire or tubing diameter d = 1.4 mm | wire or tubing diameter d = 1.4 mm
wire or tubing diameter d = 1 mm |  |  |  |  |  | wire or tubing diameter d = 1.5 mm | design frequency f = 145.5 MHz | design frequency f = 145.5 MHz
design frequency f = 145 MHz |  |  |  |  |  | design frequency f = 145.5 MHz | The (plating) material is annealed copper. | The (plating) material is annealed copper.
The (plating) material is annealed copper. |  |  |  |  |  | The (plating) material is annealed copper.
 |  |  |  |  |  |  | INTERMEDIATE RESULTS | INTERMEDIATE RESULTS
INTERMEDIATE RESULTS |  |  |  |  |  | INTERMEDIATE RESULTS | winding pitch p = 5.00 mm | winding pitch p = 7.50 mm
winding pitch p = 2.42 mm |  |  |  |  |  | winding pitch p = 4.67 mm | physical conductor length ℓ_w_phys = 83.4 mm | physical conductor length ℓ_w_phys = 50.7 mm
physical conductor length ℓ_w_phys = 68.7 mm |  |  |  |  |  | physical conductor length ℓ_w_phys = 81.3 mm | effective pitch angle ψ = 10.54° | effective pitch angle ψ = 17.39°
effective pitch angle ψ = 6.21° |  |  |  |  |  | effective pitch angle ψ = 10.14°
 |  |  |  |  |  |  | RESULTS | RESULTS
RESULTS |  |  |  |  |  | RESULTS | Effective equivalent circuit | Effective equivalent circuit
Effective equivalent circuit |  |  |  |  |  | Effective equivalent circuit | effective series inductance @ design frequency L_eff_s = 0.053 μH | effective series inductance @ design frequency L_eff_s = 0.033 μH
effective series inductance @ design frequency L_eff_s = 0.048 μH |  |  |  |  |  | effective series inductance @ design frequency L_eff_s = 0.050 μH | effective series reactance @ design frequency X_eff_s = 48.1 Ω | effective series reactance @ design frequency X_eff_s = 30.4 Ω
effective series reactance @ design frequency X_eff_s = 43.8 Ω |  |  |  |  |  | effective series reactance @ design frequency X_eff_s = 45.3 Ω | effective series AC resistance @ design frequency R_eff_s = 0.049 Ω | effective series AC resistance @ design frequency R_eff_s = 0.020 Ω
effective series AC resistance @ design frequency R_eff_s = 0.067 Ω |  |  |  |  |  | effective series AC resistance @ design frequency R_eff_s = 0.047 Ω | effective unloaded quality factor @ design frequency Q_eff = 981 | effective unloaded quality factor @ design frequency Q_eff = 1501
effective unloaded quality factor @ design frequency Q_eff = 655 |  |  |  |  |  | effective unloaded quality factor @ design frequency Q_eff = 962 | Lumped circuit equivalent | Lumped circuit equivalent
Lumped circuit equivalent |  |  |  |  |  | Lumped circuit equivalent | f-independent series inductance; geometrical formula L_s = 0.043 μH | f-independent series inductance; geometrical formula L_s = 0.022 μH
f-independent series inductance; geometrical formula L_s = 0.045 μH |  |  |  |  |  | f-independent series inductance; geometrical formula L_s = 0.041 μH | series AC resistance @ design frequency R_s = 0.033 Ω | series AC resistance @ design frequency R_s = 0.009 Ω
series AC resistance @ design frequency R_s = 0.058 Ω |  |  |  |  |  | series AC resistance @ design frequency R_s = 0.032 Ω | parallel stray capacitance @ design frequency C_p = 4.8 pF | parallel stray capacitance @ design frequency C_p = 18.1 pF
parallel stray capacitance @ design frequency C_p = 1.9 pF |  |  |  |  |  | parallel stray capacitance @ design frequency C_p = 5.0 pF | Self-resonant frequency f_res = 1224.217 MHz | Self-resonant frequency f_res = 2312.629 MHz
Self-resonant frequency f_res = 1502.098 MHz |  |  |  |  |  | Self-resonant frequency f_res = 1325.698 MHz
 |  |  |  |  |  |  | DONATE | DONATE
DONATE |  |  |  |  |  | DONATE | If this calculator proved any useful to you, | If this calculator proved any useful to you,
If this calculator proved any useful to you, |  |  |  |  |  | If this calculator proved any useful to you, | please, consider making a one-off donation | please, consider making a one-off donation
please, consider making a one-off donation |  |  |  |  |  | please, consider making a one-off donation | towards keeping me and the server up and running. | towards keeping me and the server up and running.
towards keeping me and the server up and running. |  |  |  |  |  | towards keeping me and the server up and running. | Thank you! | Thank you!
Thank you! |  |  |  |  |  | Thank you!

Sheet: Helical Resonator
Helical Resonator Design (from Zverev)
 |  |  | in
DF | mm | 10
D | mm | 22 | 0.8661417323 | L = 0.025n2 d 2 [\ - d\D2 \ ^H per axial inch
d | mm | 11.3 | 0.4448818898
n | turns/mm | 0.2621781763 | 6.659325678
n | turns | 2.25
b | mm | 8.58195
d0 | mm | 1.3
Spacing factor |  | 2.934
L | uH | 0.1615372263 | per axial inch
L | uH | 0.05457891336 | Total
Cs | pF | 0.8757873935
SRF | MHz | 727.9613882
F | MHz | 145
Cp | pF | 21.19812802
Q | approx | 521.4863794

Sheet: Coil Inductance
Calculation of coil inductance
Effect of Shield |  |  | https://coil32.net/shield-inductance.html
 |  |  |  | where:
 |  |  |  | Ls - inductance of the shielded coil;
 |  |  |  | L0 - inductance of the coil without shield;
 |  |  |  | Ds - diameter of shield;
 |  |  |  | H - height of shield;
 |  |  |  | D - diameter of winding;
 |  |  |  | L - length of winding;
D=9 | 9 | L0 | 66.3
D=(22 +15)/2= 18 | 18
l=6 | 6 | Ls | 56.93375517
Hs= 22 | 22
Q ratio |  |  | 0.8587293388
Optimising Q of coil |  |  | https://www.g3ynh.info/zdocs/magnetics/appendix/optQ_hb9dfz.html
 |  |  | https://coil32.net/theory/faq.html
Straight wires
Coil 64 |  |  | https://coil32.net/download.html
Wheeler formula for linductance |  |  |  | L = (d2n2) / (l + 0.45d) [μH]
 |  |  | https://www.qsl.net/in3otd/cg_readme.html
 |  |  | https://hamwaves.com/inductance/en/index.html#input
 |  |  | https://g3ynh.info/zdocs/magnetics/SolenoidZ.pdf
Q Factor estimation papers |  |  | https://g3ynh.info/zdocs/magnetics/appendix/hb9dfz/Mathcad_Coil_calc_w_Medhurst_et_G3YNH_131014.pdf
 |  |  | https://g3ynh.info/zdocs/magnetics/appendix/hb9dfz/Mathcad_Algo_for_opt_coil_131023.pdf
 |  |  | https://g3ynh.info/zdocs/magnetics/appendix/hb9dfz/Mathcad_hunt_for_Optimum_131011.pdf

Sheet: Zverev
Interpolated Values From Zverev Tables |  |  | Page
3dB k and q values |  |  |  |  |  |  |  |  | q0 actual
 |  |  |  |  |  |  |  |  | 14.33639531
 | q0 | IL dB | q1 | q4 | k12 | k23 | k34
 |  |  |  |  |  |  |  | Table Lookup |  | q0 table | IL dB | q1 | q4 | k12 | k23 | k34
INF. | 99.45421468 | 0 | 0.7654 | 0.7654 | 0.8409 | 0.5412 | 0.8409 |  |  | 26.131 | 1.002 | 0.5376 | 1.4782 | 1.0927 | 0.5668 | 0.667
26.131 | 26.131 | 1.002 | 0.5376 | 1.4782 | 1.0927 | 0.5668 | 0.667 |  |  | 13.066 | 2.162 | 0.5355 | 1.6875 | 1.0745 | 0.5546 | 0.6805
13.066 | 13.066 | 2.162 | 0.5355 | 1.6875 | 1.0745 | 0.5546 | 0.6805
8.71 | 8.71 | 3.489 | 0.5417 | 1.8605 | 1.0411 | 0.5373 | 0.6992
6.533 | 6.533 | 5.02 | 0.5521 | 2.017 | 1.0004 | 0.5161 | 0.7207
5.226 | 5.226 | 6.822 | 0.5656 | 2.1621 | 0.9547 | 0.4906 | 0.7444 | Interpolated values | 0.9027634665 |  | 2.049205621 | 0.5357041967 | 1.667148394 | 1.076269705 | 0.5557862857 | 0.6791873068
4.355 | 4.355 | 9.003 | 0.5819 | 2.2961 | 0.9051 | 0.4592 | 0.7706
3.733 | 3.733 | 11.772 | 0.6012 | 2.4159 | 0.8518 | 0.4192 | 0.7998
0
1.002
2.162
3.489
5.02
6.822
9.003
11.772
0.7654
0.5376
0.5355
0.5417
0.5521
0.5656
0.5819
0.6012
0.7654
1.4782
1.6875
1.8605
2.017
2.1621
2.2961
2.4159
0.8409
1.0927
1.0745
1.0411
1.0004
0.9547
0.9051
0.8518
0.5412
0.5668
0.5546
0.5373
0.5161
0.4906
0.4592
0.4192
0.8409
0.667
0.6805
0.6992
0.7207
0.7444
0.7706

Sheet: YDelta
To be used for stray C from 50 ohm tracks
Y-Delta Transformation |  |  |  | Circuit Diagram
Delta-Y Transformation
Delta | C1 | 0.6666666667 | 0.08 |  | 4.9
 | C2 | 0.4166666667 | 0.335 |  | 0.333
 | C3 | 0.6666666667 | 0.34 |  | 4.9
Wye | Ca | 2.4 | 0.5011940299 |  | 81.9021021
 | Cb | 1.5 | 0.4938235294 |  | 5.566
 | Cc | 1.5 | 2.09875 |  | 5.566

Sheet: Cap_Lookup
CapLookup | Data Table to do cap lookup
 |  |  |  |  |  |  | External cell series value |  | 4.992630079 | 0.6486456435 | 0.334960978 | 0.4093322387 | 2.663173035 | 1
 |  |  |  |  |  |  | C1 result | 20.0 | 11.0 | 4.7 | 1.0 | 2.2 | 10.0 | 3.0
 |  |  |  |  |  |  | C2 result | 5.0 | 9.1 | 0.75 | 0.5 | 0.5 | 3.6 | 1.5
 |  |  |  |  |  |  |  |  | 4.980099502 | 0.6467889908 | 0.3333333333 | 0.4074074074 | 2.647058824
 |  |  |  |  |  |  | Tolerance |  | -0.002509814757 | -0.002862352863 | -0.004859206858 | -0.004702369033 | -0.006050756477 | -1
 |  |  |  |  |  | Data input cell: | 4
List of Preferred Caps
 |  |  |  | List of possible Combinations
 | capslist | Index for C1 | Index for C2 | C1 | C2 | Series (c1,C2) |  | Nearest below | Nearest above |  | Nearest |  | C1 | C2 | Series (c1,C2)
0p5 | 0.5 | 0 | 0 | 0.5 | 0.5 | 0.25 |  | 738 | 738 |  |  |  | 20.0 | 5.0 | 4
0p75 | 0.75 | 1 | 0 | 0.75 | 0.5 | 0.3 |  |  |  |  |  |  | 20.0 | 5.0 | 4
1p0 | 1.0 | 2 | 0 | 1.0 | 0.5 | 0.3333333333
1p2 | 1.2 | 3 | 0 | 1.2 | 0.5 | 0.3529411765
1p5 | 1.5 | 4 | 0 | 1.5 | 0.5 | 0.375
1p8 | 1.8 | 5 | 0 | 1.8 | 0.5 | 0.3913043478
2p0 | 2.0 | 6 | 0 | 2.0 | 0.5 | 0.4
2p2 | 2.2 | 7 | 0 | 2.2 | 0.5 | 0.4074074074
2p4 | 2.4 | 8 | 0 | 2.4 | 0.5 | 0.4137931034
2p5 | 2.5 | 9 | 0 | 2.5 | 0.5 | 0.4166666667
2p7 | 2.7 | 10 | 0 | 2.7 | 0.5 | 0.421875
3p0 | 3.0 | 11 | 0 | 3.0 | 0.5 | 0.4285714286
3p3 | 3.3 | 12 | 0 | 3.3 | 0.5 | 0.4342105263
3p6 | 3.6 | 13 | 0 | 3.6 | 0.5 | 0.4390243902
3p9 | 3.9 | 14 | 0 | 3.9 | 0.5 | 0.4431818182
4p0 | 4.0 | 15 | 0 | 4.0 | 0.5 | 0.4444444444
4p3 | 4.3 | 16 | 0 | 4.3 | 0.5 | 0.4479166667
4p7 | 4.7 | 17 | 0 | 4.7 | 0.5 | 0.4519230769
5p0 | 5.0 | 18 | 0 | 5.0 | 0.5 | 0.4545454545
5p1 | 5.1 | 19 | 0 | 5.1 | 0.5 | 0.4553571429
5p6 | 5.6 | 20 | 0 | 5.6 | 0.5 | 0.4590163934
6p0 | 6.0 | 21 | 0 | 6.0 | 0.5 | 0.4615384615
6p2 | 6.2 | 22 | 0 | 6.2 | 0.5 | 0.4626865672
6p8 | 6.8 | 23 | 0 | 6.8 | 0.5 | 0.4657534247
7p0 | 7.0 | 24 | 0 | 7.0 | 0.5 | 0.4666666667
7p5 | 7.5 | 25 | 0 | 7.5 | 0.5 | 0.46875
8p2 | 8.2 | 26 | 0 | 8.2 | 0.5 | 0.4712643678
9p1 | 9.1 | 27 | 0 | 9.1 | 0.5 | 0.4739583333
10p0 | 10.0 | 28 | 0 | 10.0 | 0.5 | 0.4761904762
11p0 | 11.0 | 29 | 0 | 11.0 | 0.5 | 0.4782608696
12p0 | 12.0 | 30 | 0 | 12.0 | 0.5 | 0.48
13p0 | 13.0 | 31 | 0 | 13.0 | 0.5 | 0.4814814815
15p0 | 15.0 | 32 | 0 | 15.0 | 0.5 | 0.4838709677
16p0 | 16.0 | 33 | 0 | 16.0 | 0.5 | 0.4848484848
18p0 | 18.0 | 34 | 0 | 18.0 | 0.5 | 0.4864864865
20p0 | 20.0 | 35 | 0 | 20.0 | 0.5 | 0.487804878
22p0 | 22.0 | 36 | 0 | 22.0 | 0.5 | 0.4888888889
24p0 | 24.0 | 37 | 0 | 24.0 | 0.5 | 0.4897959184
27p0 | 27.0 | 38 | 0 | 27.0 | 0.5 | 0.4909090909
 |  | 39 | 1 | 0.5 | 0.75 | 0.3
Total Count | 39 | 40 | 1 | 0.75 | 0.75 | 0.375
Total Combinations | 1521 | 41 | 1 | 1.0 | 0.75 | 0.4285714286
 |  | 42 | 1 | 1.2 | 0.75 | 0.4615384615
 |  | 43 | 1 | 1.5 | 0.75 | 0.5
 |  | 44 | 1 | 1.8 | 0.75 | 0.5294117647
 |  | 45 | 1 | 2.0 | 0.75 | 0.5454545455
 |  | 46 | 1 | 2.2 | 0.75 | 0.5593220339
 |  | 47 | 1 | 2.4 | 0.75 | 0.5714285714
 |  | 48 | 1 | 2.5 | 0.75 | 0.5769230769
 |  | 49 | 1 | 2.7 | 0.75 | 0.5869565217
 |  | 50 | 1 | 3.0 | 0.75 | 0.6
 |  | 51 | 1 | 3.3 | 0.75 | 0.6111111111
 |  | 52 | 1 | 3.6 | 0.75 | 0.6206896552
 |  | 53 | 1 | 3.9 | 0.75 | 0.6290322581
 |  | 54 | 1 | 4.0 | 0.75 | 0.6315789474
 |  | 55 | 1 | 4.3 | 0.75 | 0.6386138614
 |  | 56 | 1 | 4.7 | 0.75 | 0.6467889908
 |  | 57 | 1 | 5.0 | 0.75 | 0.652173913
 |  | 58 | 1 | 5.1 | 0.75 | 0.6538461538
 |  | 59 | 1 | 5.6 | 0.75 | 0.6614173228
 |  | 60 | 1 | 6.0 | 0.75 | 0.6666666667
 |  | 61 | 1 | 6.2 | 0.75 | 0.6690647482
 |  | 62 | 1 | 6.8 | 0.75 | 0.6754966887
 |  | 63 | 1 | 7.0 | 0.75 | 0.6774193548
 |  | 64 | 1 | 7.5 | 0.75 | 0.6818181818
 |  | 65 | 1 | 8.2 | 0.75 | 0.687150838
 |  | 66 | 1 | 9.1 | 0.75 | 0.692893401
 |  | 67 | 1 | 10.0 | 0.75 | 0.6976744186
 |  | 68 | 1 | 11.0 | 0.75 | 0.7021276596
 |  | 69 | 1 | 12.0 | 0.75 | 0.7058823529
 |  | 70 | 1 | 13.0 | 0.75 | 0.7090909091
 |  | 71 | 1 | 15.0 | 0.75 | 0.7142857143
 |  | 72 | 1 | 16.0 | 0.75 | 0.7164179104
 |  | 73 | 1 | 18.0 | 0.75 | 0.72
 |  | 74 | 1 | 20.0 | 0.75 | 0.7228915663
 |  | 75 | 1 | 22.0 | 0.75 | 0.7252747253
 |  | 76 | 1 | 24.0 | 0.75 | 0.7272727273
 |  | 77 | 1 | 27.0 | 0.75 | 0.7297297297
 |  | 78 | 2 | 0.5 | 1.0 | 0.3333333333
 |  | 79 | 2 | 0.75 | 1.0 | 0.4285714286
 |  | 80 | 2 | 1.0 | 1.0 | 0.5
 |  | 81 | 2 | 1.2 | 1.0 | 0.5454545455
 |  | 82 | 2 | 1.5 | 1.0 | 0.6
 |  | 83 | 2 | 1.8 | 1.0 | 0.6428571429
 |  | 84 | 2 | 2.0 | 1.0 | 0.6666666667
 |  | 85 | 2 | 2.2 | 1.0 | 0.6875
 |  | 86 | 2 | 2.4 | 1.0 | 0.7058823529
 |  | 87 | 2 | 2.5 | 1.0 | 0.7142857143
 |  | 88 | 2 | 2.7 | 1.0 | 0.7297297297
 |  | 89 | 2 | 3.0 | 1.0 | 0.75
 |  | 90 | 2 | 3.3 | 1.0 | 0.7674418605
 |  | 91 | 2 | 3.6 | 1.0 | 0.7826086957
 |  | 92 | 2 | 3.9 | 1.0 | 0.7959183673
 |  | 93 | 2 | 4.0 | 1.0 | 0.8
 |  | 94 | 2 | 4.3 | 1.0 | 0.8113207547
 |  | 95 | 2 | 4.7 | 1.0 | 0.8245614035
 |  | 96 | 2 | 5.0 | 1.0 | 0.8333333333
 |  | 97 | 2 | 5.1 | 1.0 | 0.8360655738
 |  | 98 | 2 | 5.6 | 1.0 | 0.8484848485
 |  | 99 | 2 | 6.0 | 1.0 | 0.8571428571
 |  | 100 | 2 | 6.2 | 1.0 | 0.8611111111
 |  | 101 | 2 | 6.8 | 1.0 | 0.8717948718
 |  | 102 | 2 | 7.0 | 1.0 | 0.875
 |  | 103 | 2 | 7.5 | 1.0 | 0.8823529412
 |  | 104 | 2 | 8.2 | 1.0 | 0.8913043478
 |  | 105 | 2 | 9.1 | 1.0 | 0.900990099
 |  | 106 | 2 | 10.0 | 1.0 | 0.9090909091
 |  | 107 | 2 | 11.0 | 1.0 | 0.9166666667
 |  | 108 | 2 | 12.0 | 1.0 | 0.9230769231
 |  | 109 | 2 | 13.0 | 1.0 | 0.9285714286
 |  | 110 | 2 | 15.0 | 1.0 | 0.9375
 |  | 111 | 2 | 16.0 | 1.0 | 0.9411764706
 |  | 112 | 2 | 18.0 | 1.0 | 0.9473684211
 |  | 113 | 2 | 20.0 | 1.0 | 0.9523809524
 |  | 114 | 2 | 22.0 | 1.0 | 0.9565217391
 |  | 115 | 2 | 24.0 | 1.0 | 0.96
 |  | 116 | 2 | 27.0 | 1.0 | 0.9642857143
 |  | 117 | 3 | 0.5 | 1.2 | 0.3529411765
 |  | 118 | 3 | 0.75 | 1.2 | 0.4615384615
 |  | 119 | 3 | 1.0 | 1.2 | 0.5454545455
 |  | 120 | 3 | 1.2 | 1.2 | 0.6
 |  | 121 | 3 | 1.5 | 1.2 | 0.6666666667
 |  | 122 | 3 | 1.8 | 1.2 | 0.72
 |  | 123 | 3 | 2.0 | 1.2 | 0.75
 |  | 124 | 3 | 2.2 | 1.2 | 0.7764705882
 |  | 125 | 3 | 2.4 | 1.2 | 0.8
 |  | 126 | 3 | 2.5 | 1.2 | 0.8108108108
 |  | 127 | 3 | 2.7 | 1.2 | 0.8307692308
 |  | 128 | 3 | 3.0 | 1.2 | 0.8571428571
 |  | 129 | 3 | 3.3 | 1.2 | 0.88
 |  | 130 | 3 | 3.6 | 1.2 | 0.9
 |  | 131 | 3 | 3.9 | 1.2 | 0.9176470588
 |  | 132 | 3 | 4.0 | 1.2 | 0.9230769231
 |  | 133 | 3 | 4.3 | 1.2 | 0.9381818182
 |  | 134 | 3 | 4.7 | 1.2 | 0.9559322034
 |  | 135 | 3 | 5.0 | 1.2 | 0.9677419355
 |  | 136 | 3 | 5.1 | 1.2 | 0.9714285714
 |  | 137 | 3 | 5.6 | 1.2 | 0.9882352941
 |  | 138 | 3 | 6.0 | 1.2 | 1
 |  | 139 | 3 | 6.2 | 1.2 | 1.005405405
 |  | 140 | 3 | 6.8 | 1.2 | 1.02
 |  | 141 | 3 | 7.0 | 1.2 | 1.024390244
 |  | 142 | 3 | 7.5 | 1.2 | 1.034482759
 |  | 143 | 3 | 8.2 | 1.2 | 1.046808511
 |  | 144 | 3 | 9.1 | 1.2 | 1.060194175
 |  | 145 | 3 | 10.0 | 1.2 | 1.071428571
 |  | 146 | 3 | 11.0 | 1.2 | 1.081967213
 |  | 147 | 3 | 12.0 | 1.2 | 1.090909091
 |  | 148 | 3 | 13.0 | 1.2 | 1.098591549
 |  | 149 | 3 | 15.0 | 1.2 | 1.111111111
 |  | 150 | 3 | 16.0 | 1.2 | 1.11627907
 |  | 151 | 3 | 18.0 | 1.2 | 1.125
 |  | 152 | 3 | 20.0 | 1.2 | 1.132075472
 |  | 153 | 3 | 22.0 | 1.2 | 1.137931034
 |  | 154 | 3 | 24.0 | 1.2 | 1.142857143
 |  | 155 | 3 | 27.0 | 1.2 | 1.14893617
 |  | 156 | 4 | 0.5 | 1.5 | 0.375
 |  | 157 | 4 | 0.75 | 1.5 | 0.5
 |  | 158 | 4 | 1.0 | 1.5 | 0.6
 |  | 159 | 4 | 1.2 | 1.5 | 0.6666666667
 |  | 160 | 4 | 1.5 | 1.5 | 0.75
 |  | 161 | 4 | 1.8 | 1.5 | 0.8181818182
 |  | 162 | 4 | 2.0 | 1.5 | 0.8571428571
 |  | 163 | 4 | 2.2 | 1.5 | 0.8918918919
 |  | 164 | 4 | 2.4 | 1.5 | 0.9230769231
 |  | 165 | 4 | 2.5 | 1.5 | 0.9375
 |  | 166 | 4 | 2.7 | 1.5 | 0.9642857143
 |  | 167 | 4 | 3.0 | 1.5 | 1
 |  | 168 | 4 | 3.3 | 1.5 | 1.03125
 |  | 169 | 4 | 3.6 | 1.5 | 1.058823529
 |  | 170 | 4 | 3.9 | 1.5 | 1.083333333
 |  | 171 | 4 | 4.0 | 1.5 | 1.090909091
 |  | 172 | 4 | 4.3 | 1.5 | 1.112068966
 |  | 173 | 4 | 4.7 | 1.5 | 1.137096774
 |  | 174 | 4 | 5.0 | 1.5 | 1.153846154
 |  | 175 | 4 | 5.1 | 1.5 | 1.159090909
 |  | 176 | 4 | 5.6 | 1.5 | 1.183098592
 |  | 177 | 4 | 6.0 | 1.5 | 1.2
 |  | 178 | 4 | 6.2 | 1.5 | 1.207792208
 |  | 179 | 4 | 6.8 | 1.5 | 1.228915663
 |  | 180 | 4 | 7.0 | 1.5 | 1.235294118
 |  | 181 | 4 | 7.5 | 1.5 | 1.25
 |  | 182 | 4 | 8.2 | 1.5 | 1.268041237
 |  | 183 | 4 | 9.1 | 1.5 | 1.287735849
 |  | 184 | 4 | 10.0 | 1.5 | 1.304347826
 |  | 185 | 4 | 11.0 | 1.5 | 1.32
 |  | 186 | 4 | 12.0 | 1.5 | 1.333333333
 |  | 187 | 4 | 13.0 | 1.5 | 1.344827586
 |  | 188 | 4 | 15.0 | 1.5 | 1.363636364
 |  | 189 | 4 | 16.0 | 1.5 | 1.371428571
 |  | 190 | 4 | 18.0 | 1.5 | 1.384615385
 |  | 191 | 4 | 20.0 | 1.5 | 1.395348837
 |  | 192 | 4 | 22.0 | 1.5 | 1.404255319
 |  | 193 | 4 | 24.0 | 1.5 | 1.411764706
 |  | 194 | 4 | 27.0 | 1.5 | 1.421052632
 |  | 195 | 5 | 0.5 | 1.8 | 0.3913043478
 |  | 196 | 5 | 0.75 | 1.8 | 0.5294117647
 |  | 197 | 5 | 1.0 | 1.8 | 0.6428571429
 |  | 198 | 5 | 1.2 | 1.8 | 0.72
 |  | 199 | 5 | 1.5 | 1.8 | 0.8181818182
 |  | 200 | 5 | 1.8 | 1.8 | 0.9
 |  | 201 | 5 | 2.0 | 1.8 | 0.9473684211
 |  | 202 | 5 | 2.2 | 1.8 | 0.99
 |  | 203 | 5 | 2.4 | 1.8 | 1.028571429
 |  | 204 | 5 | 2.5 | 1.8 | 1.046511628
 |  | 205 | 5 | 2.7 | 1.8 | 1.08
 |  | 206 | 5 | 3.0 | 1.8 | 1.125
 |  | 207 | 5 | 3.3 | 1.8 | 1.164705882
 |  | 208 | 5 | 3.6 | 1.8 | 1.2
 |  | 209 | 5 | 3.9 | 1.8 | 1.231578947
 |  | 210 | 5 | 4.0 | 1.8 | 1.24137931
 |  | 211 | 5 | 4.3 | 1.8 | 1.268852459
 |  | 212 | 5 | 4.7 | 1.8 | 1.301538462
 |  | 213 | 5 | 5.0 | 1.8 | 1.323529412
 |  | 214 | 5 | 5.1 | 1.8 | 1.330434783
 |  | 215 | 5 | 5.6 | 1.8 | 1.362162162
 |  | 216 | 5 | 6.0 | 1.8 | 1.384615385
 |  | 217 | 5 | 6.2 | 1.8 | 1.395
 |  | 218 | 5 | 6.8 | 1.8 | 1.423255814
 |  | 219 | 5 | 7.0 | 1.8 | 1.431818182
 |  | 220 | 5 | 7.5 | 1.8 | 1.451612903
 |  | 221 | 5 | 8.2 | 1.8 | 1.476
 |  | 222 | 5 | 9.1 | 1.8 | 1.502752294
 |  | 223 | 5 | 10.0 | 1.8 | 1.525423729
 |  | 224 | 5 | 11.0 | 1.8 | 1.546875
 |  | 225 | 5 | 12.0 | 1.8 | 1.565217391
 |  | 226 | 5 | 13.0 | 1.8 | 1.581081081
 |  | 227 | 5 | 15.0 | 1.8 | 1.607142857
 |  | 228 | 5 | 16.0 | 1.8 | 1.617977528
 |  | 229 | 5 | 18.0 | 1.8 | 1.636363636
 |  | 230 | 5 | 20.0 | 1.8 | 1.651376147
 |  | 231 | 5 | 22.0 | 1.8 | 1.663865546
 |  | 232 | 5 | 24.0 | 1.8 | 1.674418605
 |  | 233 | 5 | 27.0 | 1.8 | 1.6875
 |  | 234 | 6 | 0.5 | 2.0 | 0.4
 |  | 235 | 6 | 0.75 | 2.0 | 0.5454545455
 |  | 236 | 6 | 1.0 | 2.0 | 0.6666666667
 |  | 237 | 6 | 1.2 | 2.0 | 0.75
 |  | 238 | 6 | 1.5 | 2.0 | 0.8571428571
 |  | 239 | 6 | 1.8 | 2.0 | 0.9473684211
 |  | 240 | 6 | 2.0 | 2.0 | 1
 |  | 241 | 6 | 2.2 | 2.0 | 1.047619048
 |  | 242 | 6 | 2.4 | 2.0 | 1.090909091
 |  | 243 | 6 | 2.5 | 2.0 | 1.111111111
 |  | 244 | 6 | 2.7 | 2.0 | 1.14893617
 |  | 245 | 6 | 3.0 | 2.0 | 1.2
 |  | 246 | 6 | 3.3 | 2.0 | 1.245283019
 |  | 247 | 6 | 3.6 | 2.0 | 1.285714286
 |  | 248 | 6 | 3.9 | 2.0 | 1.322033898
 |  | 249 | 6 | 4.0 | 2.0 | 1.333333333
 |  | 250 | 6 | 4.3 | 2.0 | 1.365079365
 |  | 251 | 6 | 4.7 | 2.0 | 1.402985075
 |  | 252 | 6 | 5.0 | 2.0 | 1.428571429
 |  | 253 | 6 | 5.1 | 2.0 | 1.436619718
 |  | 254 | 6 | 5.6 | 2.0 | 1.473684211
 |  | 255 | 6 | 6.0 | 2.0 | 1.5
 |  | 256 | 6 | 6.2 | 2.0 | 1.512195122
 |  | 257 | 6 | 6.8 | 2.0 | 1.545454545
 |  | 258 | 6 | 7.0 | 2.0 | 1.555555556
 |  | 259 | 6 | 7.5 | 2.0 | 1.578947368
 |  | 260 | 6 | 8.2 | 2.0 | 1.607843137
 |  | 261 | 6 | 9.1 | 2.0 | 1.63963964
 |  | 262 | 6 | 10.0 | 2.0 | 1.666666667
 |  | 263 | 6 | 11.0 | 2.0 | 1.692307692
 |  | 264 | 6 | 12.0 | 2.0 | 1.714285714
 |  | 265 | 6 | 13.0 | 2.0 | 1.733333333
 |  | 266 | 6 | 15.0 | 2.0 | 1.764705882
 |  | 267 | 6 | 16.0 | 2.0 | 1.777777778
 |  | 268 | 6 | 18.0 | 2.0 | 1.8
 |  | 269 | 6 | 20.0 | 2.0 | 1.818181818
 |  | 270 | 6 | 22.0 | 2.0 | 1.833333333
 |  | 271 | 6 | 24.0 | 2.0 | 1.846153846
 |  | 272 | 6 | 27.0 | 2.0 | 1.862068966
 |  | 273 | 7 | 0.5 | 2.2 | 0.4074074074
 |  | 274 | 7 | 0.75 | 2.2 | 0.5593220339
 |  | 275 | 7 | 1.0 | 2.2 | 0.6875
 |  | 276 | 7 | 1.2 | 2.2 | 0.7764705882
 |  | 277 | 7 | 1.5 | 2.2 | 0.8918918919
 |  | 278 | 7 | 1.8 | 2.2 | 0.99
 |  | 279 | 7 | 2.0 | 2.2 | 1.047619048
 |  | 280 | 7 | 2.2 | 2.2 | 1.1
 |  | 281 | 7 | 2.4 | 2.2 | 1.147826087
 |  | 282 | 7 | 2.5 | 2.2 | 1.170212766
 |  | 283 | 7 | 2.7 | 2.2 | 1.212244898
 |  | 284 | 7 | 3.0 | 2.2 | 1.269230769
 |  | 285 | 7 | 3.3 | 2.2 | 1.32
 |  | 286 | 7 | 3.6 | 2.2 | 1.365517241
 |  | 287 | 7 | 3.9 | 2.2 | 1.406557377
 |  | 288 | 7 | 4.0 | 2.2 | 1.419354839
 |  | 289 | 7 | 4.3 | 2.2 | 1.455384615
 |  | 290 | 7 | 4.7 | 2.2 | 1.498550725
 |  | 291 | 7 | 5.0 | 2.2 | 1.527777778
 |  | 292 | 7 | 5.1 | 2.2 | 1.536986301
 |  | 293 | 7 | 5.6 | 2.2 | 1.579487179
 |  | 294 | 7 | 6.0 | 2.2 | 1.609756098
 |  | 295 | 7 | 6.2 | 2.2 | 1.623809524
 |  | 296 | 7 | 6.8 | 2.2 | 1.662222222
 |  | 297 | 7 | 7.0 | 2.2 | 1.673913043
 |  | 298 | 7 | 7.5 | 2.2 | 1.701030928
 |  | 299 | 7 | 8.2 | 2.2 | 1.734615385
 |  | 300 | 7 | 9.1 | 2.2 | 1.771681416
 |  | 301 | 7 | 10.0 | 2.2 | 1.803278689
 |  | 302 | 7 | 11.0 | 2.2 | 1.833333333
 |  | 303 | 7 | 12.0 | 2.2 | 1.85915493
 |  | 304 | 7 | 13.0 | 2.2 | 1.881578947
 |  | 305 | 7 | 15.0 | 2.2 | 1.918604651
 |  | 306 | 7 | 16.0 | 2.2 | 1.934065934
 |  | 307 | 7 | 18.0 | 2.2 | 1.96039604
 |  | 308 | 7 | 20.0 | 2.2 | 1.981981982
 |  | 309 | 7 | 22.0 | 2.2 | 2
 |  | 310 | 7 | 24.0 | 2.2 | 2.015267176
 |  | 311 | 7 | 27.0 | 2.2 | 2.034246575
 |  | 312 | 8 | 0.5 | 2.4 | 0.4137931034
 |  | 313 | 8 | 0.75 | 2.4 | 0.5714285714
 |  | 314 | 8 | 1.0 | 2.4 | 0.7058823529
 |  | 315 | 8 | 1.2 | 2.4 | 0.8
 |  | 316 | 8 | 1.5 | 2.4 | 0.9230769231
 |  | 317 | 8 | 1.8 | 2.4 | 1.028571429
 |  | 318 | 8 | 2.0 | 2.4 | 1.090909091
 |  | 319 | 8 | 2.2 | 2.4 | 1.147826087
 |  | 320 | 8 | 2.4 | 2.4 | 1.2
 |  | 321 | 8 | 2.5 | 2.4 | 1.224489796
 |  | 322 | 8 | 2.7 | 2.4 | 1.270588235
 |  | 323 | 8 | 3.0 | 2.4 | 1.333333333
 |  | 324 | 8 | 3.3 | 2.4 | 1.389473684
 |  | 325 | 8 | 3.6 | 2.4 | 1.44
 |  | 326 | 8 | 3.9 | 2.4 | 1.485714286
 |  | 327 | 8 | 4.0 | 2.4 | 1.5
 |  | 328 | 8 | 4.3 | 2.4 | 1.540298507
 |  | 329 | 8 | 4.7 | 2.4 | 1.588732394
 |  | 330 | 8 | 5.0 | 2.4 | 1.621621622
 |  | 331 | 8 | 5.1 | 2.4 | 1.632
 |  | 332 | 8 | 5.6 | 2.4 | 1.68
 |  | 333 | 8 | 6.0 | 2.4 | 1.714285714
 |  | 334 | 8 | 6.2 | 2.4 | 1.730232558
 |  | 335 | 8 | 6.8 | 2.4 | 1.773913043
 |  | 336 | 8 | 7.0 | 2.4 | 1.787234043
 |  | 337 | 8 | 7.5 | 2.4 | 1.818181818
 |  | 338 | 8 | 8.2 | 2.4 | 1.856603774
 |  | 339 | 8 | 9.1 | 2.4 | 1.899130435
 |  | 340 | 8 | 10.0 | 2.4 | 1.935483871
 |  | 341 | 8 | 11.0 | 2.4 | 1.970149254
 |  | 342 | 8 | 12.0 | 2.4 | 2
 |  | 343 | 8 | 13.0 | 2.4 | 2.025974026
 |  | 344 | 8 | 15.0 | 2.4 | 2.068965517
 |  | 345 | 8 | 16.0 | 2.4 | 2.086956522
 |  | 346 | 8 | 18.0 | 2.4 | 2.117647059
 |  | 347 | 8 | 20.0 | 2.4 | 2.142857143
 |  | 348 | 8 | 22.0 | 2.4 | 2.163934426
 |  | 349 | 8 | 24.0 | 2.4 | 2.181818182
 |  | 350 | 8 | 27.0 | 2.4 | 2.204081633
 |  | 351 | 9 | 0.5 | 2.5 | 0.4166666667
 |  | 352 | 9 | 0.75 | 2.5 | 0.5769230769
 |  | 353 | 9 | 1.0 | 2.5 | 0.7142857143
 |  | 354 | 9 | 1.2 | 2.5 | 0.8108108108
 |  | 355 | 9 | 1.5 | 2.5 | 0.9375
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

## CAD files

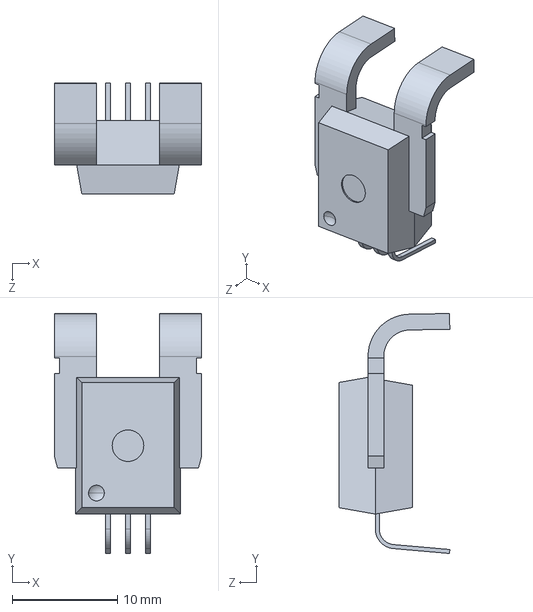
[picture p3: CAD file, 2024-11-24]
electronics/bits'n_bobs/Modular_PA Controller/PA_Power/ACS758LCB-100B-PFF-T.stp
14.0 x 22.8 x 10.5 mm

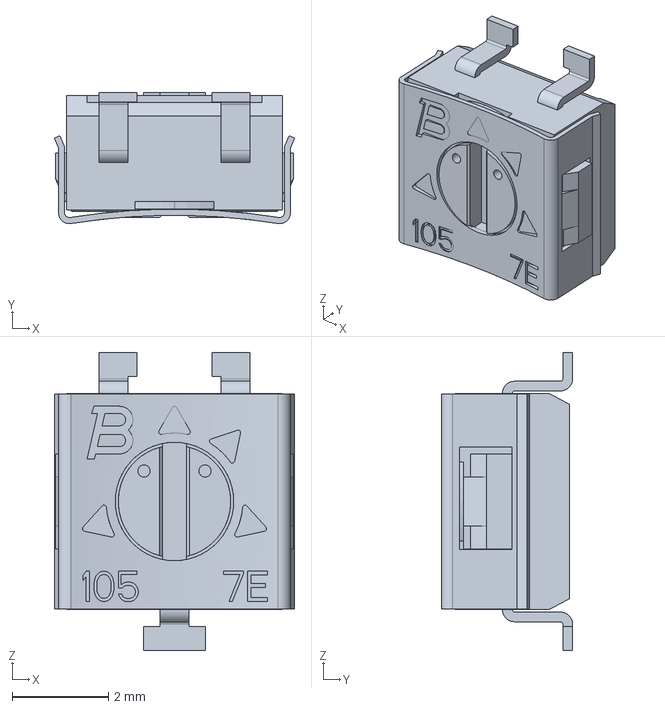
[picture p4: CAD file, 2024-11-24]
electronics/bits'n_bobs/Modular_PA Controller/PA_Power_V1/RLab Keyboard/3D_Models/3314G1.stp
5.00 x 2.73 x 6.20 mm

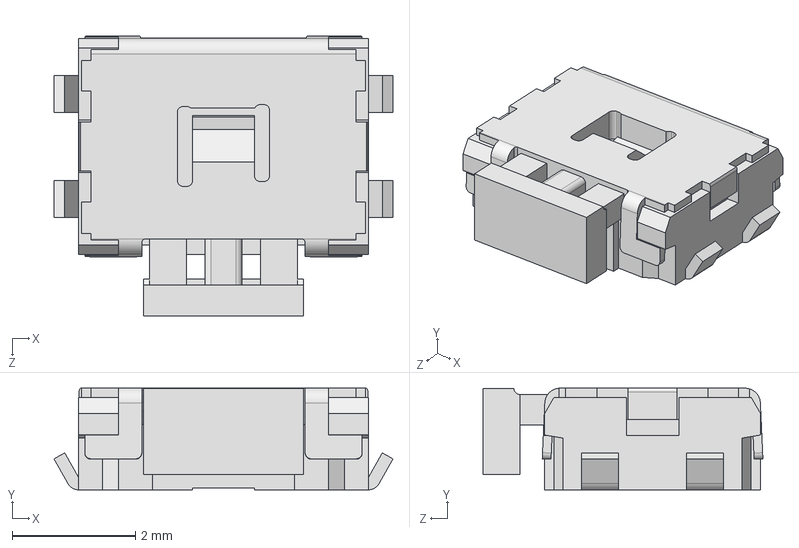
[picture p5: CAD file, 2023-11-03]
electronics/PA_Board_V2/3D/EVQPU-KB-02K.STEP
5.50 x 1.65 x 4.54 mm

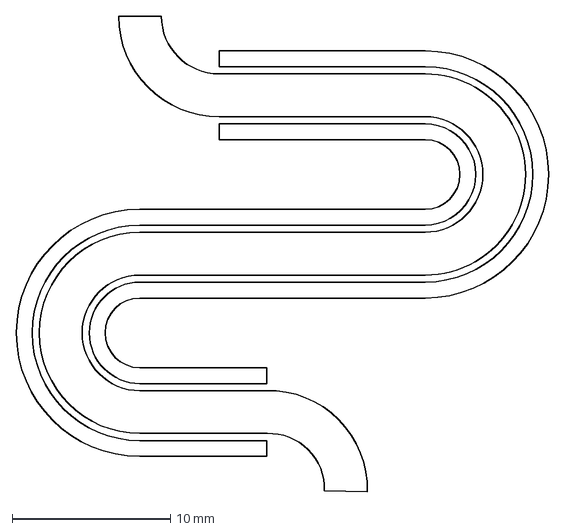
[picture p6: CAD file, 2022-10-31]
electronics/PA_Board_V2/Directional Coupler.dxf
33.6 x 30.0 mm

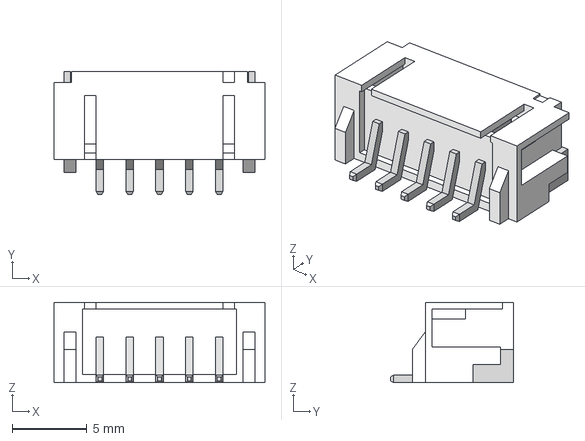
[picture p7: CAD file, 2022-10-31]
electronics/PA_Board_V2/JST/JST_PH/JST - PH - SMD - Right - 1.25mm/JST - PH - SMD (R) - 5Pin - 2.00mm.stp
14.1 x 8.26 x 5.38 mm

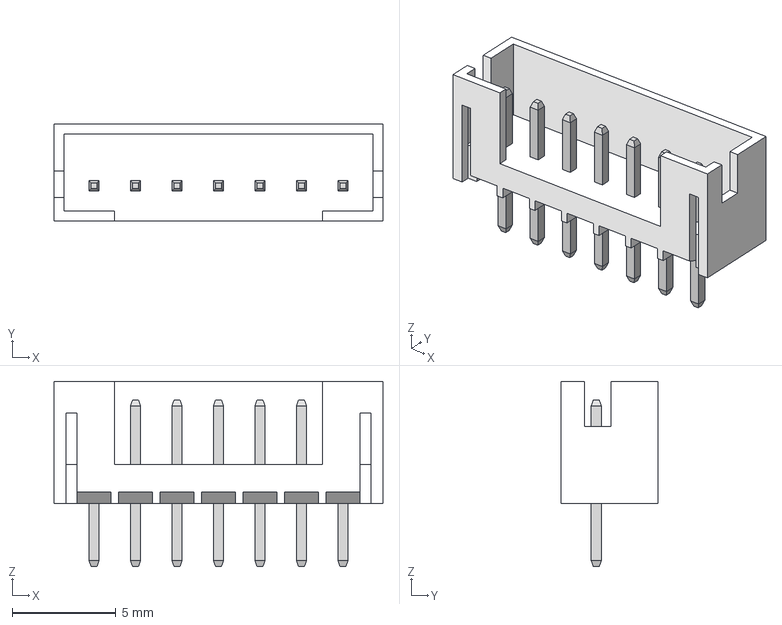
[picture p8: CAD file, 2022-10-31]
electronics/PA_Board_V2/JST/JST_PH/JST - PH - Thru - Vertical - 2.00mm/JST - PH - Thru (V) - 7Pin - 2.00mm.stp
15.9 x 4.67 x 8.94 mm

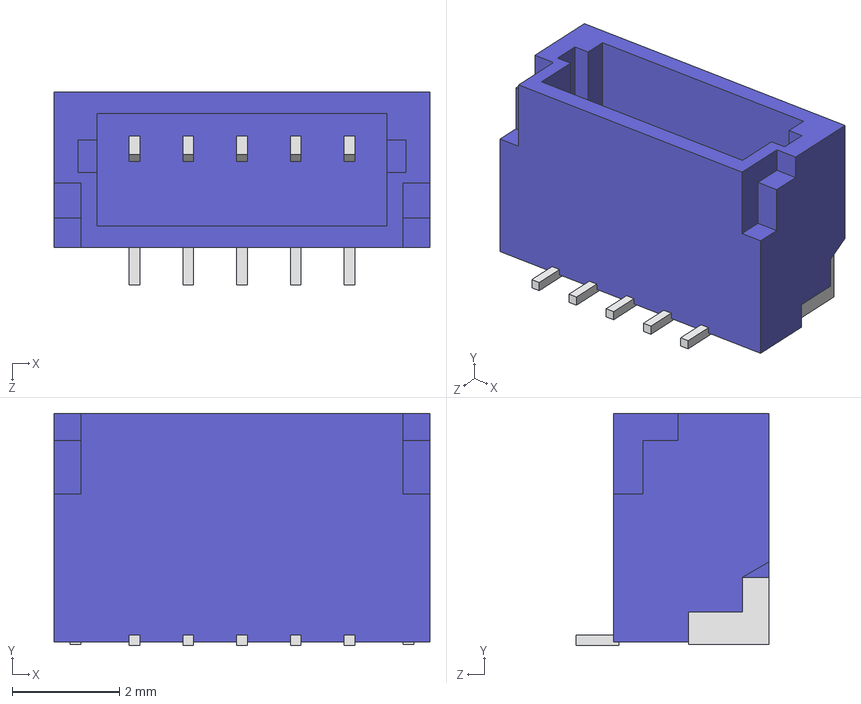
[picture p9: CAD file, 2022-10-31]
electronics/PA_Board_V2/JST/JST_SH/BMxxB-SRSR-TB/BM05B-SRSS-TB.STEP
7.00 x 4.32 x 3.60 mm

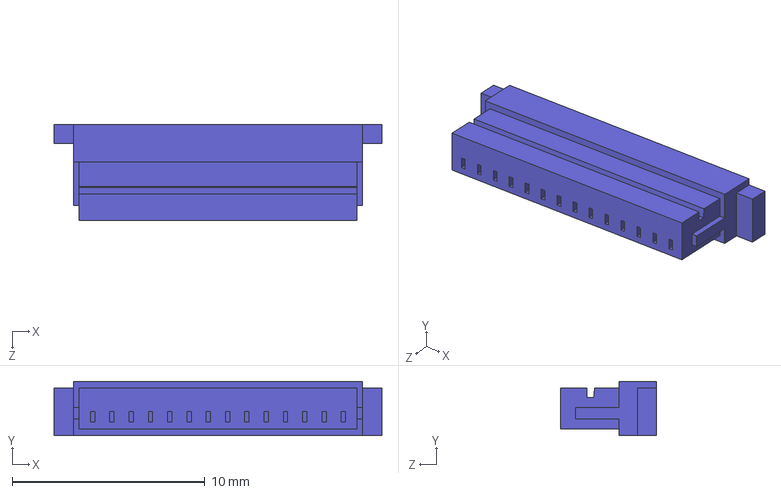
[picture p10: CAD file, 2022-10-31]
electronics/PA_Board_V2/JST/JST_SH/SHR-xxV-S-B/SHR-14V-S-B.STEP
17.0 x 2.80 x 5.00 mm

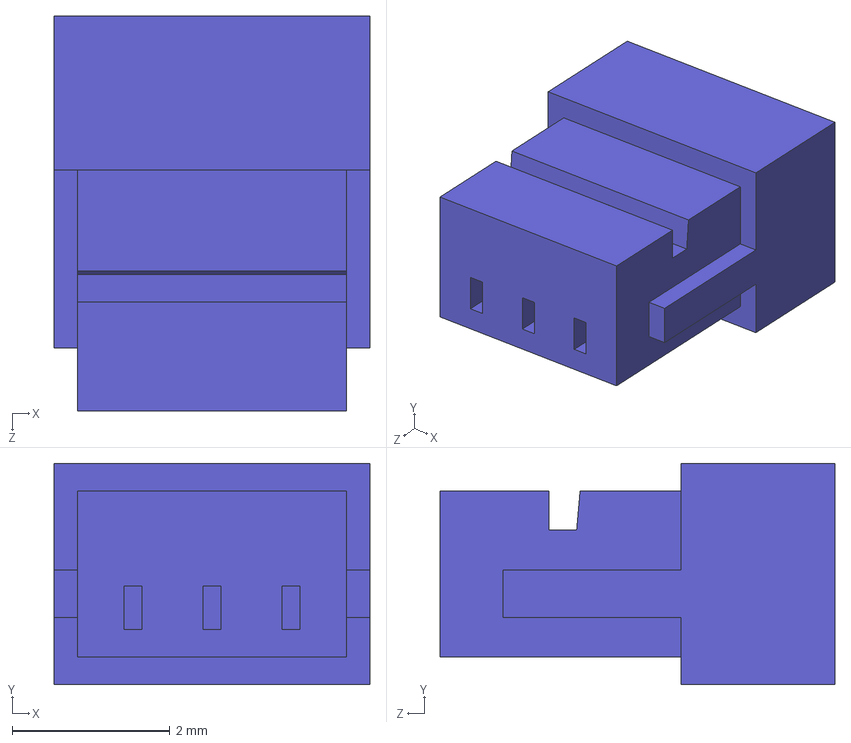
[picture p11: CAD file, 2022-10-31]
electronics/PA_Board_V2/JST/JST_SH/SHR-xxV-S/SHR-03V-S.STEP
4.00 x 2.80 x 5.00 mm

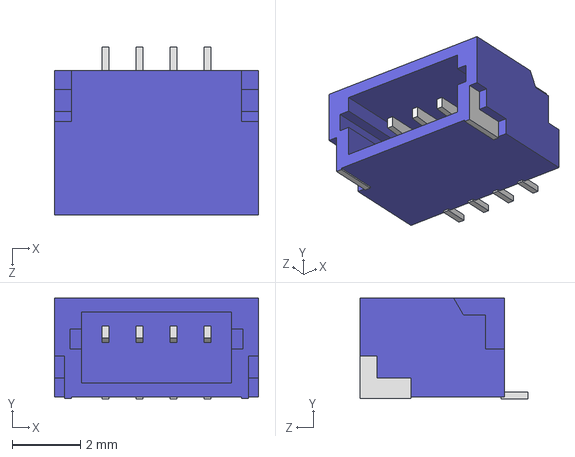
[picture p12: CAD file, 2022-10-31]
electronics/PA_Board_V2/JST/JST_SH/SMxxB-SRSS-TB/SM04B-SRSS-TB.STEP
6.00 x 2.96 x 4.95 mm

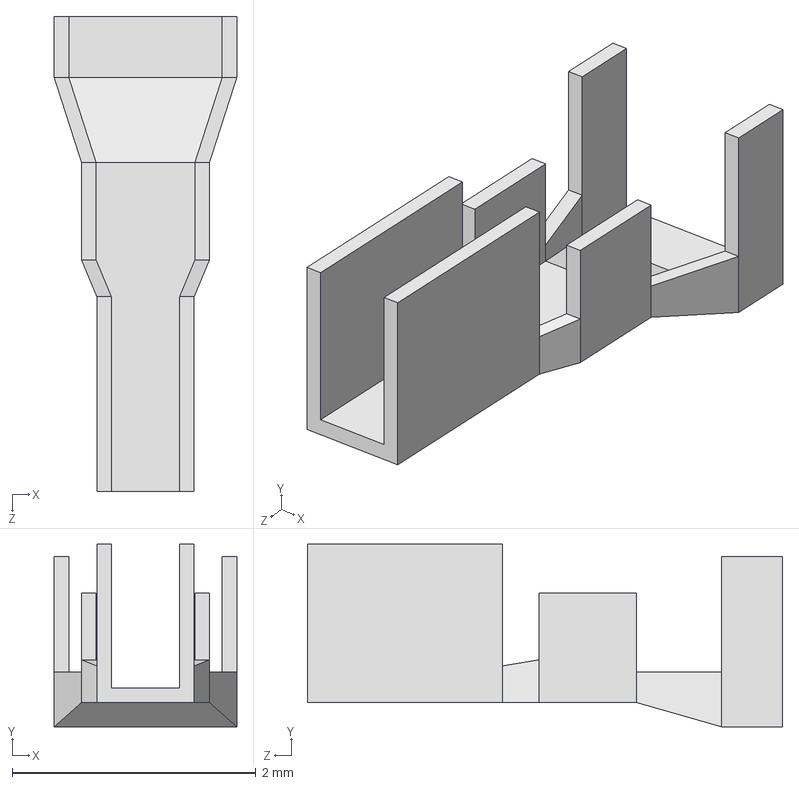
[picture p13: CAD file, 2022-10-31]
electronics/PA_Board_V2/JST/JST_SH/SSH-003T-P0.2-H/SSH-003T-P0.2-H.STEP
1.50 x 1.50 x 3.90 mm

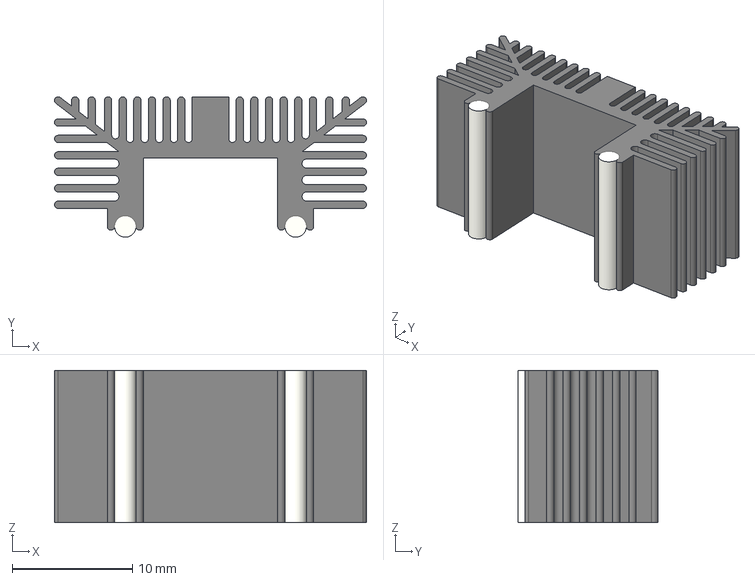
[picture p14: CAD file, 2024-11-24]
electronics/bits'n_bobs/Modular_PA Controller/PA_Power/ohmite_DA-T263-401E-TR.stp
26.0 x 11.7 x 12.7 mm

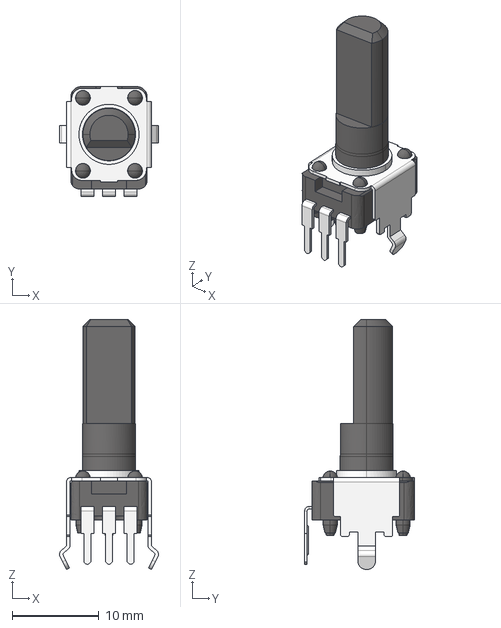
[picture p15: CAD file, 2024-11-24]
electronics/bits'n_bobs/Modular_PA Controller/PA_Power_V1/RLab Keyboard/3D_Models/RK09K1130AH1.STEP
11.4 x 12.7 x 28.8 mm

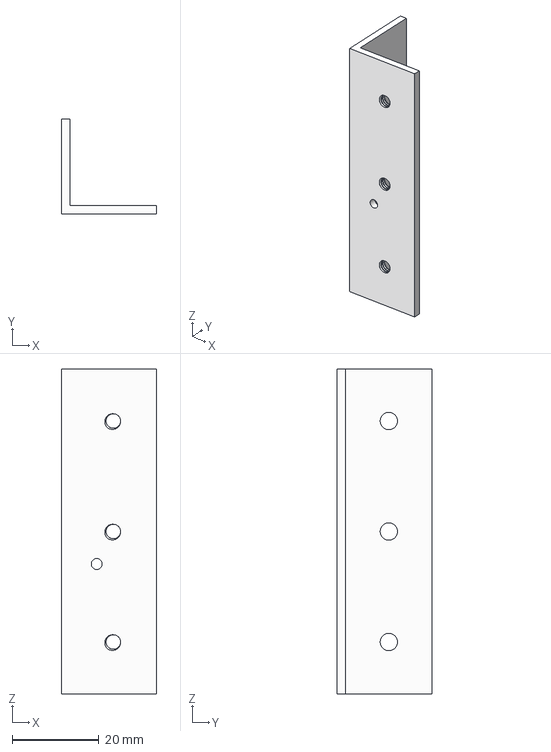
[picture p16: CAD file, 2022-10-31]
electronics/PA_Board_V2/3D/Heatsink v1.step
22.0 x 22.0 x 75.0 mm

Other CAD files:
electronics/PA_Board_V2/JST/JST_PH/JST - PH - SMD - Right - 1.25mm/JST - PH - SMD (R) - 13Pin - 2.00mm.stp
electronics/PA_Board_V2/JST/JST_PH/JST - PH - Thru - Vertical - 2.00mm/JST - PH - Thru (V) - 10Pin - 2.00mm.stp
electronics/PA_Board_V2/3D/1050170001.stp
electronics/PA_Board_V2/3D/PA_module_copper .step
electronics/PA_Board_V2/3D/Power Pole v1.step
electronics/PA_Board_V2/3D/RF_PA_module.step
electronics/PA_Board_V2/3D/SAMTEC_RF174-01SPX-06BJX-XXX-S-1.STEP
electronics/PA_Board_V2/3D/SAMTEC_SMA-J-P-H-ST-EM1.STEP
electronics/PA_Board_V2/JST/JST_PH/JST - PH - SMD - Right - 1.25mm/JST - PH - SMD (R) - 10Pin - 2.00mm.stp
electronics/PA_Board_V2/JST/JST_PH/JST - PH - SMD - Right - 1.25mm/JST - PH - SMD (R) - 11Pin - 2.00mm.stp
electronics/PA_Board_V2/JST/JST_PH/JST - PH - SMD - Right - 1.25mm/JST - PH - SMD (R) - 12Pin - 2.00mm.stp
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

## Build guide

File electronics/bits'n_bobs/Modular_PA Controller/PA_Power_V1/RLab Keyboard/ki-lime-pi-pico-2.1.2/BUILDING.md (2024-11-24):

**Instructions for building from source**
===========================================

> *Note that this project was largely leveraged for becoming more familiar with various aspects of KiCad, FreeCAD, and the Raspberry Pi Pico, and certain files may use exploratory workflows as a result.*

&nbsp;

# Development Environment

  Parametric models exported using [FreeCAD 0.21.2](https://github.com/FreeCAD/FreeCAD/releases/tag/0.21.2) with the [KiCad StepUp 12.2.6](https://github.com/easyw/kicadStepUpMod/tree/a7da10da12e405d106e1e9eb551444a289859ee8) workbench addon

  If you plan on committing changes to the .FCStd document and want (somewhat) trackable commits, then from the repository root call:

  ```bash
  mkdir -p .git/hooks
  cp .githooks/pre-commit.sh .git/hooks/pre-commit
  git config --local core.hooksPath .git/hooks
  ```

  *(If you are already using a `pre-commit` git hook, then manually add the content of `pre-commit.sh` to the existing hook instead)*

  > *Copying the file at a known state curbs the security concerns of remote changes to a hook.  Always audit scripts before using them.*

  Exported VRML models modified in [VSCodium 1.74.3](https://github.com/VSCodium/vscodium/releases/tag/1.74.3.23010)

  KiCad symbols and footprints exported using [KiCad 8.0.3](https://github.com/KiCad/kicad-source-mirror/releases/tag/8.0.3)

&nbsp;

# Symbols and Footprints

  KiCad symbols and footprints are already in the appropriate directories, so nothing needs to be done to prepare them for export.

&nbsp;

# Models

<details><summary>Regarding parametric colours</summary>
  
  > *Model faces are parametrically coloured via boolean operations between parts of varying diffuse colours.  To alter source colours for the board, see `Parametric_Source > Boards_Source > Parametric Board Colour Sources` in the `Tree view` panel and modify each Body's `Appearance`.  To alter source colours for components, be sure to modify the `Appearance` of the source Bodies **directly**, which are contained within the compounds/part containers in `Parametric_Source > Pico_Components_Source`.  Modifying the `Appearance` of the compounds/part containers or setting parts' face colours with `Set Colors...` will **not** parametrically populate.*
  >
  > *Note that as of FreeCAD 0.20.2 changing the sources of the colours does not automatically populate down all the dependent objects.  To get around this if you make any colour changes, when you are ready to export be sure to recompute the entire document as detailed below.  This should successfully populate the parametric colours across all dependent objects.*
  
</details>

  ### General

  - Open the models source file at `.../ki-lime-pi-pico/models/RaspberryPi_Pico_Variations.FCStd` in FreeCAD

    > Note: ~~If reproducible builds are important, be sure to stash any local changes to the file and reopen it before building so that you are recomputing from a known commit.~~  
    > ~~This is particularly important if you are using the `pre-commit` git hook described above.~~  
    > There is inconsistent noise generated with each recompute/export.  As a result, reproducible builds are not possible as built models will slightly differ each time.
  
  - If not already marked to recompute, in FreeCAD's `Tree view` panel `right-click` on the root document name `RaspberryPi_Pico_Variations` and select `Mark to recompute`

  - Click `Edit > Refresh` (or press `F5`) to recompute the entire document

  ### VRML

  - Enter the KiCad StepUp addon workbench from the drop-down menu at the top of the window

  - In FreeCAD's `Tree view` panel, locate the contents of the folder `Export > KiCad Model Outputs > VRML - Manually Coloured Clones`

  - If you are building from an official release commit, select the `Clone` you wish to export to a VRML file for KiCad (for example: `RaspberryPi_Pico`)  
    If you are building from a custom modification, you will likely need to recreate the `Draft Clones` from the parametrically coloured `Compounds` in `Export > KiCad Model Outputs > STEP - Parametrically Coloured Compounds`

    <details><summary>Additional information regarding clones and colours</summary>
      
      > *KiCad StepUp provides a selection of fully-featured materials that can be exported to VRML files.  Although the selection is limited, it provides convenient labelling of materials that can be edited later.  I have created `Clones` of each variation (which as of FreeCAD 0.20.2 do **not** parametrically preserve colour) and pre-set each face colour to align with colours defined within KiCad StepUp.*
      >
      > *Note that if you change geometry in any way which alters the number or topological location of faces anywhere within the model, these pre-set `Clones` will no longer be coloured appropriately*
      >
      > *You can always export from the parametrically coloured `Compounds` in `Export > KiCad Model Outputs > STEP - Parametrically Coloured Compounds`, just needing to set the export colours in KiCad StepUp each time as they will be reset upon recomputes.*
      
    </details>

  - Click on KiCad StepUp's `Export 3D Model` button (a graphic of a black 6-pin IC with a green arrow pointing down and to the right)

  - When prompted, I have used the values of `0.03 Mesh Deviation` and `0.5 creaseAngle` (old default values) and I find the results to be acceptable

  - If you are building from an official release commit, simply accept all the KiCad StepUp colour association prompts  
    If you are building from newly created `Clones`, you will need to manually set KiCad StepUp's colour associations.
    
    <details> <summary> Additional information regarding KiCad StepUp colour association </summary>
    
      > This part can be frustrating, as many parts appear off-white but are different materials.
      > When I built it, there are some colours which are automatically associated to a named material in KiCad StepUp; you shouldn't have to alter those.  
      > The remaining non-automatic colours broadly presented themselves in the following order:
      >
      > - `metal silver` (soldered pads)
      > - `pcb green`
      > - `light brown label` (FR4 core)
      > - `yellow body` (gold pins)
      > - `brown body` (caps)
      > - `resistor black body` (res/diode)
      > - `led white` (led lens)
      > - `light brown body` (led board)
      > - `green body` (led phosphor)
      > - `metal grey` (oscillator/wifi package)
      >
      > If this list doesn't appear to be accurate for you, then you can always set each colour to a high-contrasting material, and then select the appropriate material association in a second round of exporting.

    </details>

  - Repeat this for all `Clones`

  - Prepare a powerful text editor for bulk file editing

    <details> <summary> Specific instructions for preparing VSCodium/VSCode</summary>

      - Open a new VSCode-based instance

      - Select `File > Open Folder...`

      - Navigate to the directory `.../ki-lime-pi-pico/`

      - Select the folder `models/` and click `Select Folder`

      - Open each `.wrl` file by `double-clicking` each file in the `Explorer` pane

      - Select the magnifying glass on the left to open the `Search` pane

      - Expand the search box with the arrow to its left to reveal its find-and-replace functionality

      - Click the `...` in the bottom-right of the find-and-replace fields to expand additional options

      - Select the graphic of an open book in the `files to include` field to only process files which are currently open

    </details>

  - Find and replace the following material names in the newly created `.wrl` files:

    > *Be sure **not** to replace these material names in `MaterialsList.txt`!*

    | Original material   | Replace with
    |:-------------------:|:------------:
    | `PLASTIC-YELLOW-01` | `FINISH-GOLD`
    | `MET-SILVER`        | `FINISH-SILVER`
    | `RES-SMD-01`        | `IC-BODY-EPOXY-02`
    | `CAP-CERAMIC-06`    | `CAP-CERAMIC-01`
    | `MET-01`            | `FINISH-TIN`
    | `IC-LABEL-01`       | `BOARD-FR4-NATURAL`
    | `BOARD-GREEN-02`    | `MASK-PINE-GREEN`
    | `RES-THT-01`        | `MASK-LIGHT-TAN`
    | `LED-WHITE`         | `LED-LENS-CLEAR`
    | `PLASTIC-GREEN-01`  | `EMISSIVE-GREEN-PHOSPHOR`
  ##  
  - Finally, replace the default KiCad StepUp material definitions at the start of each `.wrl` file with the expanded list of materials found in `MaterialsList.txt`

    > *In VSCode-based editors, selecting `Match Case` in the search allows for the large blocks of material definition text to successfully be found and replaced*

    ---

  &nbsp;

  > *KiCad StepUp will automatically generate STEP files with limited hierarchy, part naming, and colour information as a result of the process above, so next we will export STEP models with more detailed information.*

  > *As of the time of writing, KiCad does not appropriately handle exporting part face colours when the component's STEP file uses assemblies.  To get around this, we will export our STEP models as `Compounds` for KiCad.  This will still result in limited hierarchy and part naming information, but will at least preserve face colours (excluding transparency) and discrete sub-components.*

  ### STEP (for KiCad)

  - In FreeCAD's `Tree view` panel, shift focus to the contents of the folder `Export > KiCad Model Outputs > STEP - Parametrically Coloured Compounds`

  - Manually select the root body you wish to export (for example: `RaspberryPi_Pico_Compound`)

  - Press `Ctrl + E`, or select `File > Export`

  - For ease, ensure the directory matches where KiCad StepUp exported its files to:
    `.../ki-lime-pi-pico/models/`

  - Ensure file type `"STEP with colors (*.step *.stp)"` is selected

  - Select the name of the already-generated model you intend to replace (for example: `RaspberryPi_Pico.step`)

  - Select `Save`, and select `Yes` when asked to replace the existing file

  - Repeat this for all models

  - Once all 3D models have been exported as `.wrl` and `.step` files, navigate to:

  ```
  .../ki-lime-pi-pico/models/
  ```

  - And **copy** (don't remove!) all `.wrl` and `.step` files to:

  ```
  .../ki-lime-pi-pico/kicad/project-libraries/RaspberryPi_Pico/Module_RaspberryPi_Pico.3dshapes/
  ```

  ---
  > *In addition to these KiCad models, we can also export a second set of STEP files to a supplemental directory, in the event any users have a need for the fully-featured assemblies.  Feel free to skip this section if all you need is a standalone KiCad library.*

  ### STEP (fully featured supplement)

  - In FreeCAD's `Tree view` panel, navigate into the folder `Export > STEP Assembly`

  - Manually select the root body you wish to export (for example: `RaspberryPi_Pico_STEP`)

  - Press `Ctrl + E`, or select `File > Export`

  - For ease, ensure again the directory matches where KiCad StepUp exported its files to:
    `.../ki-lime-pi-pico/models/`

  - Ensure file type `"STEP with colors (*.step *.stp)"` is selected

  - Select the name of the already-generated model you intend to replace again (for example: `RaspberryPi_Pico.step`)

  - Select `Save`, and select `Yes` when asked to replace the existing file

    > *As a result of using empty `Group` folders as a source of parametric part/feature naming, exporting these parts will result in an expected warning in the `Report view`.*

  - Repeat this for all models

  - Once these 3D models have been exported as `.step` files, navigate to:
  ```
  .../ki-lime-pi-pico/models/
  ```

  - And copy all `.step` files to:

  ```
  .../ki-lime-pi-pico/models/RaspberryPi_Pico_STEP/
  ```

  ### File cleanup

  - Navigate to `.../ki-lime-pi-pico/models/`

  - Delete the previously copied `.wrl` and `.step` files, as they are no longer needed in this directory

&nbsp;

# Final recommendations

As desired, navigate to our source's root directory:

```
.../ki-lime-pi-pico/
```

Append, replace, or otherwise modify files such as `LICENSE.txt`, `ATTRIBUTION.md`, and `README.md` to appropriately reflect your needs.

Copy the desired files *(for example, I include all three of `LICENSE.txt`, `ATTRIBUTION.md`, and `README.md` with the final build)* to:

```
.../ki-lime-pi-pico/kicad/project-libraries/RaspberryPi_Pico/
```

*I prefer to remove the references to images in the built library's `README.md` once it's copied here to keep it clean and compact.*

If you are also exporting the fully-featured supplemental STEP models, copy the desired files *(for example, I include `LICENSE.txt` and `ATTRIBUTION.md`)* to:

```
.../ki-lime-pi-pico/models/RaspberryPi_Pico_STEP/
```

&nbsp;

# **All done!** 🎉

Your completed library to reference, copy, and distribute as you wish can be found at:

```
.../ki-lime-pi-pico/kicad/project-libraries/RaspberryPi_Pico/
```

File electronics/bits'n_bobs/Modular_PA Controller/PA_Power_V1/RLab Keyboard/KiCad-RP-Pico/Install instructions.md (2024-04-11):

# Install instructions

## 1. Copy the files locally

Copy the `RP-Pico Libraries` folder wherever you like on your computer.

## 2. Install the Raspberry Pi Pico board schema symbol

Use the `KiCad | Preferences | Manage Symbol Libraries...` command to manage the symbol library:



then select the global tab and click on the folder button:



navigate to the `RP-Pico Libraries` folder, select the `MCU_RaspberryPi_and_Boards.kicad_sym` file and open it:



et voilà, the first step is completed:



You can now close the symbol libraries manager window.

## 3. Install the Raspberry Pi Pico board footprint

You can use a similar approach to add the footprint to the footprint libraries manager, but I've found some issues that I've solved using the footprint editor, so here are the steps I suggest you to follow:

Open the footprint editor



wait for the footprints to load... then use the `File | Add Library` command:



confirm the `Global` choice:



and select the `MCU_RaspberriPi_and_Boards.pretty` folder (yes, the folder represent a footprint library on KiCad):



Now the library is installed on KiCad with the Raspberry Pi Pico footprint (double click on it to see it on the editor pane):



Don't close the windows as the next step start from here.

## 4. Install the Raspberry Pi Pico board footprint 3D visual

If not already open, open the the footprint editor

symbol library manager

double click on the `RPi_Pico_SMD_TH` footprint from the `MCU_RaspberriPi_and_Boards` library and then click on the `Footprint properties` icon:



In the footprint properties window, first select the `3D Settings` tab. Please note that the preview shows only the PCB board with the footprint added on step 3, without any 3D representation of the Raspberry Pi Pico board. Now click on the folder icon to add the 3D model:



Navigate to the `RP-Pico Libraries` folder, select the `Pico.wrl` file and wait until the model is shown in the right panel, then confirm with OK:



The model is already scaled and translated to match the footprint:



now close the `Footprint Properties` window, and the `Footprint Editor`, obviously saving the changes.

## Conclusion

Now that you've installed the schema and footprint and added the 3D model to the footprint, you can use the Raspberry Pi Pico board on your KiCad projects.

I've also added a test KiCad Project on the `Test` folder, that you can use to see an example of it.

Have fun!

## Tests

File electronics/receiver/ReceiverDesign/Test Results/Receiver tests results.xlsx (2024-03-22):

Test Results for V1 PCB |  |  | Test freq MHz
 |  |  | 145
Port In | Port Out | Confifuration | Level dB
J402 | J406 | ATD | 0
 |  | PTD | 0
 |  | PRD | -70
 |  | PRS | -36
 |  | PTS | 0
J401 | J406 | ATD | -70
 |  | PTD | -38
 |  | PRD | -70
 |  | PRS | -70
 |  | PTS
J407 | J401 | ARD | -9
 |  | PRD | -9 | Varies with frequency no LNA
 |  | ATD | -70
 |  | ARS | -70
 |  | ATS | -70
J403 | J401 | ATS | -16
 |  | ARS | -16
 |  | ARD | -60
 |  | ATD | -16
J402 | J401 | ATD | -70
 |  | ATS | -70
 |  | ARD | -50
 |  | ARS | -70

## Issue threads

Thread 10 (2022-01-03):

Design 3D-printable case

M0LTE, 2022-01-03:
Ideas here: https://github.com/M0LTE/pi-transceiver/wiki#case

JP-rg, 2022-01-04:
What material is going to best for the 3d print? I would suggest PTEG any other suggestions?

M0LTE, 2022-01-04:
Probably prototype in PLA then choose a final material when design is
settled. Unclear as yet if there is a need for shielding etc, potentially
copper tape on the inside.

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

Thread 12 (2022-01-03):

Clone the FlexControl knob

M0LTE, 2022-01-03:
A side project.

It would be nice to have a little microcontroller connected to a rotary encoder which outputs the same simple ASCII protocol as the FlexControl knob via serial or USB serial.

This would connect internally to the Pi and could be exposed on the front panel as a rotary knob.

M5ET, 2022-01-03:
Parts have been ordered to do this for minimal cost. Experimentation will be done once they arrive in a week or so.

At the moment it's sub-£10 for the encoder/switch and an arduino with a short USB cable (not necessary for the final design). I'm not planning to replicate the extra 3 switches on the FlexControl unless people specifically think that would be useful (I'm not sure it would for this application)

M0LTE, 2022-01-07:
@borzwatson have a chat with @M5ET who is also interested in this

borzwatson, 2022-01-07:
Hi @M5ET I am also interested in the encoder, but want to use a larger free-running one. I have one on order and also an Ardunino pro. I am planning to use the code/wiring used by the Langstone project suggested by @G4CDF at https://wiki.microwavers.org.uk/Langstone_Project#External_rotary_encoder_for_tuning. Will update when I receive the bits.

M5ET, 2022-01-09:
@borzwatson theoretically the encoder size itself should be irrelevant - you should be able to put whatever sized knob on it you like. Whilst my initial testing will be done with a clicky encoder (as that's what turned up from eBay), my intention would also be for it to be free-spin friendly in future versions, so I'll be looking at options once I've got the code nailed down.

The code itself should be trivial - just a quick read of how fast the encoder is spinning and therefore which ascii command to send out of the arduino's serial port over USB. @M0LTE has already planned to add the code on the rig side for FlexControl compatibility (which is what I'll emulate with the "cheap" encoder), so it should all slot together fairly nicely and easily!

M0LTE, 2022-01-11:
>  @M0LTE has already planned to add the code on the rig side

This is done and working with a genuine Flex knob. The rig will do a scan of all serial ports at startup, looking for a serial port that, when opened at 9600 baud, responds with the magic ASCII string "F0304;" one or more times. It then grabs that port, drops the others, and it's wired up to the VFO display.

M0LTE, 2022-01-17:
Knobs to twiddle https://sdrgadgets.co.uk/2-home

gblades, 2022-01-17:
I would suggest implementing the extra four buttons even if it’s just header pins on a pcb and support in software. People can then use it to make their own flex knob.
We will need a calibration option as a cheap encoder is 20 steps per revolution but the type that Simon purchased can be up to 600 so it will need to be scaled down. Accepting commands over serial to set the division factor and save them to flash would be easiest and a universal solution.
I also have a cheap rotary encoder but also mouse scroll wheel encoders on order to try.

gblades, 2022-01-17:
For the code to read the encoder I would suggest https://playground.arduino.cc/Main/RotaryEncoders/#Example3 as it is interrupt driven so should work well with high resolution encoders.

borzwatson, 2022-01-18:
Hi,

Using the Langstone controller as a basis, I have a working code for this - seems to be very responsive on a 400 per rev control.

I have added it to the GitHub under control-knob folder. Note it is unfinished - plans I have

- Add compiler switches so it will compile on Arduino's without USB mouse emulation - in this mode only FlexKnob protocol would be available.

- Add support for Flex buttons

- Add physical switch to select between mouse emulation and FlexKnob on Arduinos which support mouse.

- Experiment with adding a I2C DAC to drive a physical S meter, driven by incoming serial commands  << Note that is a side-line plan, I can understand many may see this functionality as utterly pointless! Also not sure how feasible it is with the amount of serial data to get a responsive S meter, but would like to experiment.

73

Simon M0ZSU

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

borzwatson, 2022-01-31:
Basic functionality now working, including the switch and 3 buttons - the DAC idea has now moved to the main project being driven directly by the Pi.

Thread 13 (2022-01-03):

Build a static UI layout for the Pi touchscreen

M0LTE, 2022-01-03:
Absolute minimum features:
- finger-size frequency display digits with up/down controls, hidden or visible
- TX/RX indicator
- signal strength bargraph with S0 - S9 then +1 to +60dB
- TX test button

Look and feel: kind of like the IC7300

See:
https://github.com/M0LTE/pi-transceiver/blob/main/software/rig-controller/rig-controller/Pages/Index.cshtml
https://github.com/M0LTE/pi-transceiver/blob/main/software/rig-controller/rig-controller/wwwroot/js/rigui.js

M0LTE, 2022-01-11:
Pushing on with something functional but it won't be pretty. Anyone can come along and improve this - it's just HTML...

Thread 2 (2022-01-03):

Get LimeSDR source/sink blocks working on GNU Radio 3.8 on Windows

M0LTE, 2022-01-03:
Currently they work on GNU Radio 3.7 on Windows, GNU Radio 3.8 on Linux, but I can't find a LimeSDR plugin release for GNU Radio 3.8 on Windows

https://github.com/myriadrf/gr-limesdr/tree/gr-3.8

https://github.com/myriadrf/gr-limesdr/tree/master

https://github.com/myriadrf/gr-limesdr/issues/79

G4CDF, 2022-01-08:
Would this work?
 https://wiki.myriadrf.org/Gr-limesdr_Plugin_for_GNURadio
It mentions GRC 3.8.

M0LTE, 2022-01-08:
The Windows installation instructions section links to 3.7

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

M0LTE, 2022-01-11:
Currently I recommend working on the Pi directly, with the full desktop OS installed, gnuradio installed from repositories and gr-limesdr built from source

Alternatively work on an Ubuntu LTS laptop with gnuradio from repositories and gr-limesdr installed from the PPA repository.

Flowgraphs are interchangeable between those two environments.

Windows is currently a no-go. @borzwatson has established that the LimeSDR is happy being passed through to a Linux vmware VM on a Windows PC.

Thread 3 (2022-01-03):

Temporary on-screen TX button

M0LTE, 2022-01-03:
What should happen when enabled:

- Two GPIOs should go high, in sequence
- The RX indicator should change to TX
- A (hardcoded) GNU Radio flowgraph should start running

When disabled, the opposite should happen in reverse order.

The flowgraph could just be a CW tone or CW ID for now. Maybe two TX buttons, one for "from an audio device", another just CW.

This is probably a temporary button.

Closed 2022-01-10.

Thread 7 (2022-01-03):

Hardware PTT

M0LTE, 2022-01-03:
When a GPIO input is triggered, the PTT sequence should be initiated.

gblades, 2022-01-17:
I would suggest having an option to use one of the buttons on the flex knob for ptt.
Using a setup like https://www.eevblog.com/forum/rf-microwave/remoting-your-rig/ it would then leave it open for someone to create a pi to handle audio and flex knob and send everything over Ethernet or WiFi or even control remotely from a pc.

M0LTE, 2022-01-18:
Absolutely agree.

The whole rig will expose an API anyhow. Pressing PTT on screen will be
equivalent to pressing a hardware PTT and also equivalent to PTT via this
button.

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

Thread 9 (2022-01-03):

Receive SSB

M0LTE, 2022-01-03:
A GNU Radio flowgraph needs developing which demodulates SSB from the set frequency and outputs it to an audio device.

How this interacts with the transmit flowgraph is an unanswered question. Hopefully the two flowgraphs can just be fully independent, with the RX flowgraph being muted during TX, and the TX flowgraph being muted during RX.

G4CDF, 2022-01-07:
In order to avoid the transmitted signal interfering with receiver, the transmitter signal must be suppressed during receive.  It is not sufficient to rely on hardware

M0LTE, 2022-01-07:
@G4CDF Is it likely to be sufficient to mute the TX output in software during RX, or do we need to physically break the connection between the LimeSDR output port and the first gain stage?

(As a reminder, the LimeSDR will likely be permanently in TX, just with zero modulation)

G4CDF, 2022-01-07:
I think that as long as the Tx digital signal is zero or low amplitude then the rx chain will not be interfered with.  The issue is internal to the LimeSDR hardware not the external amplifiers.

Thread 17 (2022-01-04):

GNU Radio can't record audio from a USB sound card, but only on the Pi

M0LTE, 2022-01-04:
With a flow graph which just samples from the default sound card, on the Pi GRC just does this:

```
pi@pi-transceiver:~/pi-transceiver/software/flow-graphs $ ./audiotest.py
gr::log :INFO: audio source - Audio source arch: alsa
gr::log :ERROR: audio_alsa_source0 - [default]: No such file or directory
Traceback (most recent call last):
  File "/home/pi/pi-transceiver/software/flow-graphs/./audiotest.py", line 69, in <module>
    main()
  File "/home/pi/pi-transceiver/software/flow-graphs/./audiotest.py", line 54, in main
    tb = top_block_cls()
  File "/home/pi/pi-transceiver/software/flow-graphs/./audiotest.py", line 36, in __init__
    self.audio_source_0 = audio.source(samp_rate, '', True)
  File "/usr/lib/python3/dist-packages/gnuradio/audio/audio_swig.py", line 119, in make
    return _audio_swig.source_make(*args, **kwargs)
RuntimeError: audio_alsa_source
```

on an Ubuntu laptop, that works fine.

```
pi@pi-transceiver:~/pi-transceiver/software/flow-graphs $ arecord -L
null
    Discard all samples (playback) or generate zero samples (capture)
hw:CARD=Device,DEV=0
    USB Audio Device, USB Audio
    Direct hardware device without any conversions
plughw:CARD=Device,DEV=0
    USB Audio Device, USB Audio
    Hardware device with all software conversions
default:CARD=Device
    USB Audio Device, USB Audio
    Default Audio Device
sysdefault:CARD=Device
    USB Audio Device, USB Audio
    Default Audio Device
front:CARD=Device,DEV=0
    USB Audio Device, USB Audio
    Front output / input
dsnoop:CARD=Device,DEV=0
    USB Audio Device, USB Audio
    Direct sample snooping device
```

M0LTE, 2022-01-10:
This worked fine using Raspberry Pi OS (with desktop), GRC from repos, and self-built gr-limesdr plugin for GRC 3.8

i.e. the only difference is with/without desktop

I will try again from scratch on the without-desktop OS, to see if I missed something during setup. Otherwise it is likely to be some package or configuration that exists in the desktop version but not in the lite version, which would hardly be unexpected.

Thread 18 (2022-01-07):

RF Phase Noise and Spurious Testing

G4CDF, 2022-01-07:
To be able to meet and acceptable level of noise and spurious, prototypes will need to be tested in an efficient way.  One way used previously is to monitor the UUT transmitter with a downconverter feeding a good HF transceiver.  However this is tedious as the spectrum has to be tuned manually and there is not accurate measurement.
To provide a better apprach it is proposed to use a G4DDK Anglian transverter is receive mode followed by a homebrew ~28.3MHz bandstop filter (about 10kHz wide) into a Rigol spectrum analyser.

G4CDF, 2022-01-10:
Someone who could design and make a 28 MHz crystal bandstop filter with  say 20kHz bandwidth and rejection of 50dB at 30kHz away would be welcome...

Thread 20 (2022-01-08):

Lime SDR Mini Power Levels

G4CDF, 2022-01-08:
My LimeSDR mini is not giving the full power level (16dBm as measured by M0LTE).  The most I can currently get is about 3dBm.  I am running on USB2 output from a Dell laptop.  There is no provision for external power so I will try using a hub.

M0LTE, 2022-01-10:
I confirmed the power levels were as expected using my LimeSDR Mini on the Pi I've shipped to you @G4CDF

Of course there is always the possibility that my QRP power meter is a long way out... though the power output on the QRO wattmeter at the end of the gain chain is consistent with my QRP measurements being correct.

G4CDF, 2022-01-10:
Tom how did you calibrate your LimeSDR?

M0LTE, 2022-01-10:
I didn’t do anything special

This might be a plugin version / driver version issue

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

G4CDF, 2022-01-10:
Or it could be that the power from the laptop USB2 was not sufficient for the LimeSDR.
I will test it with the Pi4 and the Rigol analyser.

G4CDF, 2022-01-14:
Now gives 15dBm at full power (Gain =73) when fed from RPi4

G4CDF, 2022-01-14:
Need to determine maximum linear power output (PEP) and settings to achieve it.

M0LTE, 2022-01-14:
Interesting related find here- I installed an old gr-limesdr plugin the
other day and max gain the driver would accept was 60… upgraded and got a
range up to 70+ and more power out. May or May not be what you experienced.

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

G4CDF, 2022-01-25:
Results of linear power level tests:
These were measured at 144.250 MHz with 2 equal tones 2kHz apart
Power setting  Power per tone (dBm)  IP3 level (dBc)
72                    8.74                                -32
71                                                           -40
70                     6.74                               -40
69                      4.4                                -45

So for good IM performance (<-40dB) a power level of 4.4 dBm per tone can be expected, this equating to 10.4dBm PEP.
Allow losses of 4dB for the BPG and PIN switches, so expect 6dBm for full output power.  This assumes good matches and so no need for resistive attenuators.

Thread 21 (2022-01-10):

Forward and reflected power meters + SWR display

M0LTE, 2022-01-10:
For measurement of forward and reflected power we need at least two channels of ADC. The Pi has none, but it does have I2C.

Purchased an ADS1115 I2C 4 channel 16 bit ADC to trial. This should be easy to bring into the UI.

@G4CDF What voltage range do we need to measure? Potential divider with a pot sufficient to calibrate?

G4CDF, 2022-01-10:
The output from the detectors will be amplified. So say 0v to 3V at full power?  I would do all the cal in software.

M0LTE, 2022-01-10:
Maybe just a 10k pot in series to be able to fit the whole of the sample
into the range of the ADC board. The board will have a hard maximum, can’t
do that in software. 3V gives me a ballpark to aim for.

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

G4CDF, 2022-01-10:
I would expect to be able to design the power detector such that the saturated power of the PA would not exceed the 3V limit (assuming that the ADC runs on 3 V). With 16 bits in the ADC there should be no need to have a trimmer on the PCB.

M0LTE, 2022-01-10:
Great, there’s your requirement then :-)

I’ll let you know how I get on with that ADC board

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

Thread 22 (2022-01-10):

RF Bandpass Filter

G4CDF, 2022-01-10:
The issue here is what specification and design for the 144MHz bandpass filter.  The aim is to use the same filter for tx and rx with PIN diode switching.
Specification has been taken from https://www.sotabeams.co.uk/bandpass-filter-for-2m/
(and modified as required)
Filter bandwidth 144 - 146 MHz (-1dB) ie centre frequency 145 MHz
Attenuation:
In-band typically < 3dB
433 MHz > 70dB
155 MHz approx. 25dB
FM broadcast band (88 to 108 MHz) >70dB
Air band (108 to 137 MHz) > 50 dB

On the basis of above assuming a symmetric filter, the
-25 dB bandwidth is <20MHz,
-50dB bandwidth is < 15MHz
  and 70dB bandwidth < 94MHz
It may be that a bandstop section would be best to reject the air band

From Zverev p99, a 4 pole symmetric filter (Chebychev 0.5dB ripple) will provide >55dB attenuation at 15MHz bandwidth, so should be suitable.
It is intended to design one and simulate using QUCS (Quite Universal Circuit Simulator) before prototyping

G4CDF, 2022-01-15:
Decided to extend 1dB bandwidth to 144 to 147MHz to allow use in the NOV band.
Need to check that 1dB slope is ok for the reduced bandwidth TV signals etc.

G4CDF, 2022-01-15:
Various design files are being committed to G4CDF branch please ignore at present as they are not complete.

G4CDF, 2022-01-18:
Currently the BPF will occupy 35 mm x 35 mm of PCB area and will be about 20 mm high.  Whether a screening can will be required remains to be seen but in any case it wil be 5 sided and soldered to the PCB.  Alignment requires adjustment of 4 capacitors only I hope.  This can be done with spectrum analyser and tracking generator or VNA.
I intend to build the first few on a PCB about 50 mm x 35 mm.

G4CDF, 2022-04-08:
After much work I have decided to use a 4 pole butterworth filter.  The -3dB bandwith will be 4MHz.  The inductors will be mouted in 22mm pipe caps and have a predicted Qu of 520.  This has been checked by measurement.

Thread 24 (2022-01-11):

Transmitter Performance

G4CDF, 2022-01-11:
This issue addresses the Lime SDR performance and how it affects the complete transmitter performance.
Details of the LimeSDR Mini are provided at https://limemicro.com/app/uploads/2017/07/LMS7002M-Data-Sheet-v3.1r00.pdf
 and https://limemicro.com/app/uploads/2015/08/LMS7002M_Measurements-v1_05.pdf

The transmitter performance is affected by:
Intermodulation
Composite Noise (phase noise and amplitude noise)
Power Level vs frequency
Spurious signals

This issue will address each of these.

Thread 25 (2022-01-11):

Receiver Performance

G4CDF, 2022-01-11:
This issue addresses the Lime SDR performance and how it affects the complete receiver performance.
Details of the LimeSDR Mini are provided at https://limemicro.com/app/uploads/2017/07/LMS7002M-Data-Sheet-v3.1r00.pdf
and https://limemicro.com/app/uploads/2015/08/LMS7002M_Measurements-v1_05.pdf

The receiver performance is affected by:
Intermodulation
Phase Noise
Noise figure vs frequency
Spurious signals

This issue will address each of these.

G4CDF, 2022-01-11:
Intermodulation:
The most important intermodulation parameter is third order: IP3.  The requirement for IP3 is derived from the maximum levels of two (different) signals in the band of interest e.g. 144.1 to 144.3 MHz.  The noise figure of the receiver and minimum expected antenna noise are also required.
According to G8DOH in [https://www.youtube.com/watch?v=wHPpP2FJqrU]
the maximum expected signal would be -36dBm in 3kHz (measured).
The expected noise level would be -173 + 2= -171dBm/Hz ie -137 dBm  in 3kHz.

(IP3+36) *3= IP3 +137
IP3= (-108 +137 )/2 = 14.5 dBm.

This is a requirements that is very difficult to achieve.  As an example that G4DDK Anglian transverter has and IP3 of +1dBm and that is highly regarded.  G8DOH shows the next largest signal at about -20dB on the -36dBm signal.  This would result in a calculated IP3 of -5.5dBm.

Looking at the LimeSDR IP3 measurements on Page 45 shows an optimum IP3 of -7dB (optimised against noise figure).  This is quite close to meeting the requirement.  I small switchable attenuator may be useful (in addition to switching out any low noise preamplifer)

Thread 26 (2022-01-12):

Power button

M0LTE, 2022-01-12:
Power button will need to initiate a graceful shutdown of the OS when pressed.

Power-off button could be touchscreen or physical.

There are off-the-shelf solutions for this already nicely engineered.

Or we can do it ourselves. I can see us needing a separate always-on microcontroller which lives in deep-sleep mode, waiting for a button press, and applying power to the Pi to boot up. Another button press could flag via GPIO that a service on the Pi should shut it down.

I seem to remember something to do with ‘run’ on the pinout of the Pi 4.

Or, we go the read-only filesystem route and just yank the power.

G4CDF, 2022-01-12:
I suggest using a MOSET to interrupt the 12V input to avoid battery drain.  This could be done as part of power protection.

gblades, 2022-01-17:
I would suggest going with the read only file system anyway in a similar way to how pi-star does it as people will always sometimes just switch off the supply and this will help to avoid a corrupted file system.
My inline PowerPole circuit (BOB) together with a relay where the output of the protection board powers the relay coil would enable a soft power on button to be used. The pi could pull down the SHDN pin on the protection ic when it has finished to switch off the power.

G4CDF, 2022-01-18:
In my experience, the only way to deal with the 12V supply being swiched of eg mains failure or operator turning the power off is by having a power reservoir eg big capacitor on the RPi supply and the software taking suitable precautions when updating critcal variables.
Could we do the functions of a relay with a power FET?  One relay (antenna changeover)  is enough

M0LTE, 2022-01-18:
We could avoid engineering this one ourselves by using something like this

https://thepihut.com/products/raspberry-pi-ups-hat

gblades, 2022-01-18:
The UPS hat would be the way to go. You can get some USB power banks where the output is always enabled but ensuring people use one with a suitable current rating and output voltage (the Pi likes a little over 5V) would be problematic.
We could use a P channel MOSFET. The gate would just be tied to the input supply via a resistor and then a transistor connected to the output to pull the gate down to 0V to turn it on. You will only get isolation in one direction but if we use the protection circuit anyway this won't be an issue. The protection circuit uses back to back N channel MOSFETs but has a charge pump circuit to bring the gate voltage above the supply to turn them on which is overkill for what we need.

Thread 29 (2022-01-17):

RF Attenuator before Lime SDR RX Input

ribbotson, 2022-01-17:
Mike proposed a digital controlled attenuator befor the RX input of the Line SDR. This will allow the input level to be adjusted to keep the least significant bits at noise level an maximise the available dynamic range of the 12 bit ADC in the Lime SDR.
Chip attenuators like PE4302/PE4312 or F1956 are possible candidates. The interface is usually either parallel or simple bit serial with clock, data,and latch

M0LTE, 2022-01-17:
@G4CDF has suggested 2 bits parallel, might be simplest for now. Can always iterate. Though if anyone builds hardware we can easily drop in support for it!

G4CDF, 2022-01-17:
There is a possible advantage of the software monitoring the signal entering the LimeSDR and using an attenuator to keep it within the ADC max limit.  This would  have to be done in real time.  Not sure if this would work though in practice.  Could use PIN attenuators as per IC7300/9700 although these are manually controlled.

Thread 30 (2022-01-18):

Selection of approach for 144MHz power amplifier

G4CDF, 2022-01-18:
Initial thoughts were to use a Mitsubishi module (eg RA35H1516M).  These are obsolete but easily obtainable.  See

http://www.g4izh.co.uk/mitsubishi-ra35h1516m-pa-module-conversion-to-4m.html

for more information.

Data sheet is at

https://www.mitsubishielectric.com/semiconductors/content/product/highfrequency/siliconrf/module/ra35h1516m.pdf

G4CDF, 2022-01-18:
I then discovered some low cost dual LDMOS devices that are designed for 12.5V operation in Mobile radio service.
A suitable final would be AFT05MP075GNR1 from NXP.  Price from mouser is £16.47 +VAT.  Data sheet is https://www.mouser.co.uk/datasheet/2/302/AFT05MP075N-1126063.pdf
This can provide 75W for 144 and 432 MHz (different design of PCB).  In fact it is used to provide 100W on the IC9700!
The design looks straightforward if NXP will provide data for 144MHz and possible if they do not.  This assumes use in parallel rather than push pull.

G4CDF, 2022-01-18:
400W is a dream that will not happen for the following reasons:
W6PQL has an excellent 1kW linear design
I don't fancy 80A at 12V
There are no LDMOS fets that will give 400W at 12.5 V and combining would be a nightmare.
Unless someone knows otherwise 100W is a reasonable upper limit.  Clearly Icom thought the same.

M0LTE, 2022-01-18:
50W would be great. Even 25W would be a big success. 100W and especially
400W is what I’d consider exotic for 2m. An external linear might be a nice
follow-on project.

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

G4CDF, 2022-01-18:
Go for W6PQL 1kW design...  At 600W it is nicely underrun even allowing for coax losses.  At this power 28V or 50V will do for supply.

G4CDF, 2022-01-24:
Very sensibly we will go for the Mitsubishi module first: thanks Richard M0SKP

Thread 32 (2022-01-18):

Speaker

G4CDF, 2022-01-18:
Are we going to make this rig different by not including a speaker?
If not anyone want to find a good one?

M0LTE, 2022-01-18:
I'd like a speaker.

A nice independent sub-module of this radio might be a USB audio board which includes speaker, audio amplifier, volume control, switching 3.5mm stereo socket, and mic input.

I actually thought I'd already created an issue for that...

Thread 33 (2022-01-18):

Power supply

gblades, 2022-01-18:
With regard to the power supply and input protection I intend to use the LTC4368 that I have previously used on my inline protection board.
I intend to have a P channel MOSFET on the input instead of a latching relay. It will be wired to only switch on if there is already an output on the protection board so it will latch in the same way as a relay. There will be a header for connection to a momentary switch for soft power on.
The SHDN of the LTC4368 will be connected to a few inputs via diodes so that there are a few channels where between 2.5V and +VE can be connected to in order to switch off the supply. One would be the raspberry pi and others could be any other fault detection circuitry.

What are we planning to use for the 5V supply?

I'm also thinking of adding an AMS-1117-5V onto the PCB direct from the input to provide a permanent 5V supply which could be used if anyone wishes to add a little microcontroller of some sort in order to be able to remotely power on for example. The space required will be minimal and it doesn't have to be populated if not used.

What connectors do we want to use?
For the input I assume screw terminals as there will be a lead to a chassis mount powerpole or similar.
What power connector would people like for the 13.8V output to the PA and how many?
For logic IO such as the shutdown signals I intend to use JST 2.5mm type connectors.
What about the 5V output? If this direct from the 5V supply or is it going to connect back into the PSU board and fan out to where it is required?

G4CDF, 2022-01-18:
I use these types of connectors: https://www.12voltplanet.co.uk/insulated-ring-crimp-terminal-red.html.  These can be stacked for multiple band PAs.
Bigger ones are in use on my mast winch and are rated to 200A
Powerpole are too expensive for internal use

G4CDF, 2022-01-18:
I thought of chocolate blocks but these can be unreliable and will take more space up with multiple bands

M0LTE, 2022-01-18:
I’ve started using a lot of wago-style spring connectors. If they’re good
enough for UK mains electrics, they’re good enough for us. Far prefer them
to screw terminals. Does something like this exist in PCB-mount?

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

M0LTE, 2022-01-18:
Like this

https://uk.farnell.com/wago/2604-1102/terminal-block-wtb-2pos-24-12awg/dp/3577796

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

gblades, 2022-01-18:
They look good. https://www.rapidonline.com/phoenix-contact-1729018-mkdsn-1-5-2-2-way-screw-pcb-terminal-block-13-5a-5mm-52-3886 is the common type but a lower 13A rating. They are both a 5mm pitch so I can design for the Wago's with their two pins per contact and the others will still fit.

How many 5V and 13.8V outputs will we need and how much current would each need to handle and in total?

M0LTE, 2022-01-18:
For the 5V, I’d probably allow for three positive terminals. The Pi wants
3A, and runs fine with the touchscreen on the same official 3A supply. If
we can have 4A that probably makes sense. The Lime and all peripherals hang
off the Pi’s USB.

I’ll let Mike speak for 13.8V.

What is going to be the ground reference for the radio? Possibly makes
sense for it to be the PSU? In which case, doubling up on terminal count
makes sense…

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

gblades, 2022-01-18:
What 5V power supply module is being used?
Is it going to use one of the 13.8V outputs and then come back to the PCB and for the PCB just to act as a 5V distribution board?
Or can it be piggy backed directly onto the psu pcb?

M0LTE, 2022-01-18:
I am hoping that you’ll pick one and include it on this PSU board :)

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

gblades, 2022-01-18:
Ok no problem.

G4CDF, 2022-01-18:
For the PA we will need 1 connector per band, so it is anyone's guess.  Allow say 4 bands.  The borad can always be subpopulated.  I think that any sophisticated current limiting, VSWR protection etc should be done on the RF boards if required.
Grounding issues are always going to be a problem so we need a good strategy.  RF earth will have to be connected to DC earth so where does the current flow?  One way is to use isolated power supplies but very expensive.  The other way is to define a pseudo- common grounding point such as all the antenna connections.

gblades, 2022-01-19:
I have decided to go with the LM2759 as the buck converter to generate the 5V supply. It will actually output 5.1V as that is what the Pi likes and it can supply up to 5A.
Ti provide a very good web tool called WEBENCH where you can put in your power supply requirement and it generates possibly circuits which you can then filter by a particular controller chip.
Have a look at https://github.com/M0LTE/pi-transceiver/tree/M7GRB/electronics/PSU%20Board as I have saved the generated schematic, efficiency graphs and the bill of materials down to specific part numbers.

M0LTE, 2022-01-19:
Amazing work! Thanks! What’s next?

On Wed, 19 Jan 2022 at 21:31, Gareth Blades M7GRB ***@***.***>
wrote:

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

gblades, 2022-01-19:
There is still a lot of things to do. I need to put the new 5v supply into kicad, add the connectors for the wago blocks etc..., build a parts list and add the major bits onto the next order someone is making and then start on the pcb design.

gblades, 2022-01-24:
I have added some of the parts to a Mouser parts list and there is a link to this in the readme.md in my branch. I haven't finished yet but the major components are there and the total cost for parts is going to be in the region £25-30+VAT

M0LTE, 2022-01-24:
Great stuff, thanks Gareth 👍

On Mon, 24 Jan 2022 at 19:07, Gareth Blades M7GRB ***@***.***>
wrote:

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

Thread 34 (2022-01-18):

LimeSDR external clock

M0LTE, 2022-01-18:
The LimeSDR Mini can take an external clock from 10-52MHz through a tiny coax connector on the underside of the board.

See https://destevez.net/2019/11/using-an-external-reference-with-the-limesdr-mini/

Not necessary for v1 but do we want to take the opportunity to do so at some point?

The rig would be noticeably less drifty...

gblades, 2022-01-18:
I think its worth supporting it in software as it just requires an API call and a configuration option in the GUI.
Later when the radio is up and working we can try it with a 10Mhz reference and see how it performs as the processor will be running at a lower speed as the built in one is 40Mhz. If that works maybe see if John or Loz would care to add the details of the GPS disciplined references they have built.

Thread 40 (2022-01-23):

Transmitter/Receiver Switching Timing

G4CDF, 2022-01-23:
Previous specification form discord

Sequence:
Rx to Tx:  Ant relay to Tx, delay 20ms (Trelay=15 ms max), PA bias on, unmute flowgraph
Tx to Rx:  Mute flowgraph. PA bias off, delay 20ms + time it takes to mute flowgraph max. Ant relay to Rx
Need to decide what to do if Tx/RX occurs in mid sequence

G4CDF, 2022-01-23:
Replace by:
:
Rx to Tx:  Ant relay to Tx, delay 20ms (Trelay=15 ms max), PA bias on, unmute flowgraph
Tx to Rx:  Mute flowgraph and PA bias off, delay 20ms . Ant relay to Rx,  Wait 20ms before rx signals appear
Need to decide what to do if Tx/RX occurs in mid sequence: Do not act upon a request until a sequence currently in progress has completed

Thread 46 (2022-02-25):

Pi interface board

M0LTE, 2022-02-25:
Suggested 40 pin header pinout: [link](https://docs.google.com/spreadsheets/d/1Nf7KcFOCoI9gorfEW-V2X97y0xYmrL0twZed37Yi8l4/edit?usp=sharing)

Terminals on this board:

```
power
  - gnd                          pins 6, 9, 14, 20, 25, 30, 34, 39 (use multiple)
  - +5v input                    pins 2, 4 (use both)

receiver board
  - gnd
  - tx gpio (gpio 18)            pin 12
  - att1 gpio (gpio 17)          pin 11
  - att2 gpio (gpio 27)          pin 13
  - rx overload (gpio 22)        pin 15

pa board
  - gnd
  - i2c sda                      pin 3
  - i2c scl                      pin 5
  - interrupt (gpio 23)          pin 16

psu
  - gnd
  - io 1                         pin 36
  - io 2                         pin 38
  - io 3                         pin 40

misc / spare
  - multiple i2c ports, consisting of:
    - gnd
    - sda                        pin 3
    - scl                        pin 5
  - uart
    - gnd
    - txd                        pin 8
    - rxd                        pin 10
  - 1wire bus (temp sensing, DS18B20)
    - gnd
    - data                       pin 37
    - 3.3V
    - 4.7k pull-up resistor between data and +3.3V
  - multiple 3.3v connections    pins 1, 17
  - multiple 5v connections
  - multiple gnd connections
```

ADC
We have four channels with one module. Probably enough.
makes sense to have four pairs of pins of:
 - gnd
 - analogue V in

We could solder a pre-made ADS1115 module on to a header on this hat, or we could
go chip-level and put a few components around it.
The ADS1115 needs to connect to the I2C pins on the 40 pin header.
My assumption is with such short wires we can have a star topology I2C bus and don't need to loop
the SDA and SCL pins out and back, or worse, rats nest between all the boards.

DAC
This is for an analogue meter etc.
@Simon - this interface is down to you. Did you want to put this at the other end of an I2C interface?
Alternatively, we could do hardware PWM driving a moving meter coil presumably via a transistor. You decide.
If we did hardware PWM as per the fans below, you could just crimp a standard fan connector on to wires
from the moving coil meter, and we choose in software whether we want two independent fans, or one fan + PWM meter.

Fans:
I suggest we use PWM-control fans with rpm feedback to a GPIO, like this:
https://blog.driftking.tw/en/2019/11/Using-Raspberry-Pi-to-Control-a-PWM-Fan-and-Monitor-its-Speed/
we have two hardware PWM ports on the pi - PWM0 (pin 12 and 32), PWM1 (pin 33 and 35)
I suggest two fan ports using the standard 4 pin PWM fan connector
connections:
  - +5V
  - gnd
  - PWM output, to PWM0 (pin 12) or PWM1 (pin 13)
  - RPM sense, to gpio 5 (pin 29) or gpio 6 (pin 31)
or one PWM port for a fan, and one PWM port for the moving coil meter. (Should we buffer the PWM pins just in case?)

Connectors:
Would like to see 2.54mm pitch connectors for anything low current, and 5mm pitch holes for anything higher current, e.g. power in. Various connectors will fit - [I like these](https://uk.farnell.com/wago/2604-1102/tb-wire-to-board-2pos-24-12awg/dp/2821984)

gblades, 2022-02-25:
Psu board connections would be :-
Io1 - output, high to switch off the 12v input.
Io2 - input, goes active high if the supply to the 5v dc-dc converter drops below 9V. Used to initiate a shutdown.
Io3 - output, high to indicate the 12v battery backup is to shut off its output.

The normal shutdown sequence would be to set io1 high and wait a second. If there is no battery backup this would cut the power immediately. Otherwise after a second set io3 high to switch off the battery output to avoid it being drained by the pi sitting in a shutdown state.

G4CDF, 2022-02-26:
Some PCBs will need Power input but at low current eg 100mA.   Should power always use a power connector or is it acceptable to use the signal connectors?  What happens if there is a short circuit ie what current limits are provided?  To complicate matters even more what if the PSU module uses a high current connector and the (say) Receiver module uses a low currect connector what size of connecting wire can be used.  Can multiple wires be easily used in a power socket pin?

M0LTE, 2022-02-26:
I don't think we can or should protect every module from every other module. I don't think that's how commercial radios are designed is it?

> Can multiple wires be easily used in a power socket pin?
I don't see any need to do this - we'll just put enough terminals on the edge of the board for our needs :-)

G4CDF, 2022-02-26:
Sounds good.  The Receiver module will need +12V, +5V and gnd power inputs.

borzwatson, 2022-03-01:
Thanks for all this, I've started doing a board,added to GitHub. Do feel free to dive in, I''ll make sure I pull all the files in before I edit any more when I get time.
I would prefer to use the I2C DA which I will add to the board. It can just be left off by those not interested in these functionality.
Ok on the fan functionality.
Hopefully will get some time to do a bit more soon.

borzwatson, 2022-03-02:
@M0LTE What is the ADC for please? Since the PA board is i2c I would have thought SWR/Output sensing etc.  and the ADC would be on that board.
The reason I ask is I think the analog input wiring between the ADC and whatever it is measuring needs to be kept short I am not sure what the ADC is going to be connected to. 73 S

G4CDF, 2022-03-02:
Originally the ADC was for the Power amplifier directional coupler signals to measure forward and reverse power.  However I think that Richard is planning to put the ADC on the PA module.  Richard please confirm.  Other uses would be to monitor voltage rails etc

M0LTE, 2022-03-02:
Mike is right. One less thing to worry about :)

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

ribbotson, 2023-11-24:
Closing this issue as first pass the Pi interface board is designed and built.

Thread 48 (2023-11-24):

Receiver Board: Power Supplies

ribbotson, 2023-11-24:
The 5V and 3.3V power supplies in the receiver board might be improved:
1) The AMS1117 regulator currently used are not stable with low ESR ceramic capacitors. Recommend change to more stable type
2) Add more capacitors at input and out put of regulator. Follow manufacturer but I would suggest 10uF on each input and output plus a 100nf on output.
3) Suggest to add an LC pi filter to all of the power rails. If not needed easy to leave off capacitors or add 0R resistors to bypass ferrite.

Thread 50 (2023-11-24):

Receiver Board: Second power/I2C connector

ribbotson, 2023-11-24:
We are still looking at power and signal distribution on the assembly, but is would useful to have a second connector in parallel with the existing for the I2C and Power connections.
It may even be useful to bring out the 3.3V and 5V supplies so they could be used as inputs or outputs.

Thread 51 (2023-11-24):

Receiver Board: Footprint for Low Noise Amplifier

ribbotson, 2023-11-24:
The footprint used on the PCB for the Low Noise Amplifier U408 is a SOT89, however the device used PSA4-5043 has a SOT343-4 footprint.
Device will fit on pads of rotated or PGA-103+ can be used.

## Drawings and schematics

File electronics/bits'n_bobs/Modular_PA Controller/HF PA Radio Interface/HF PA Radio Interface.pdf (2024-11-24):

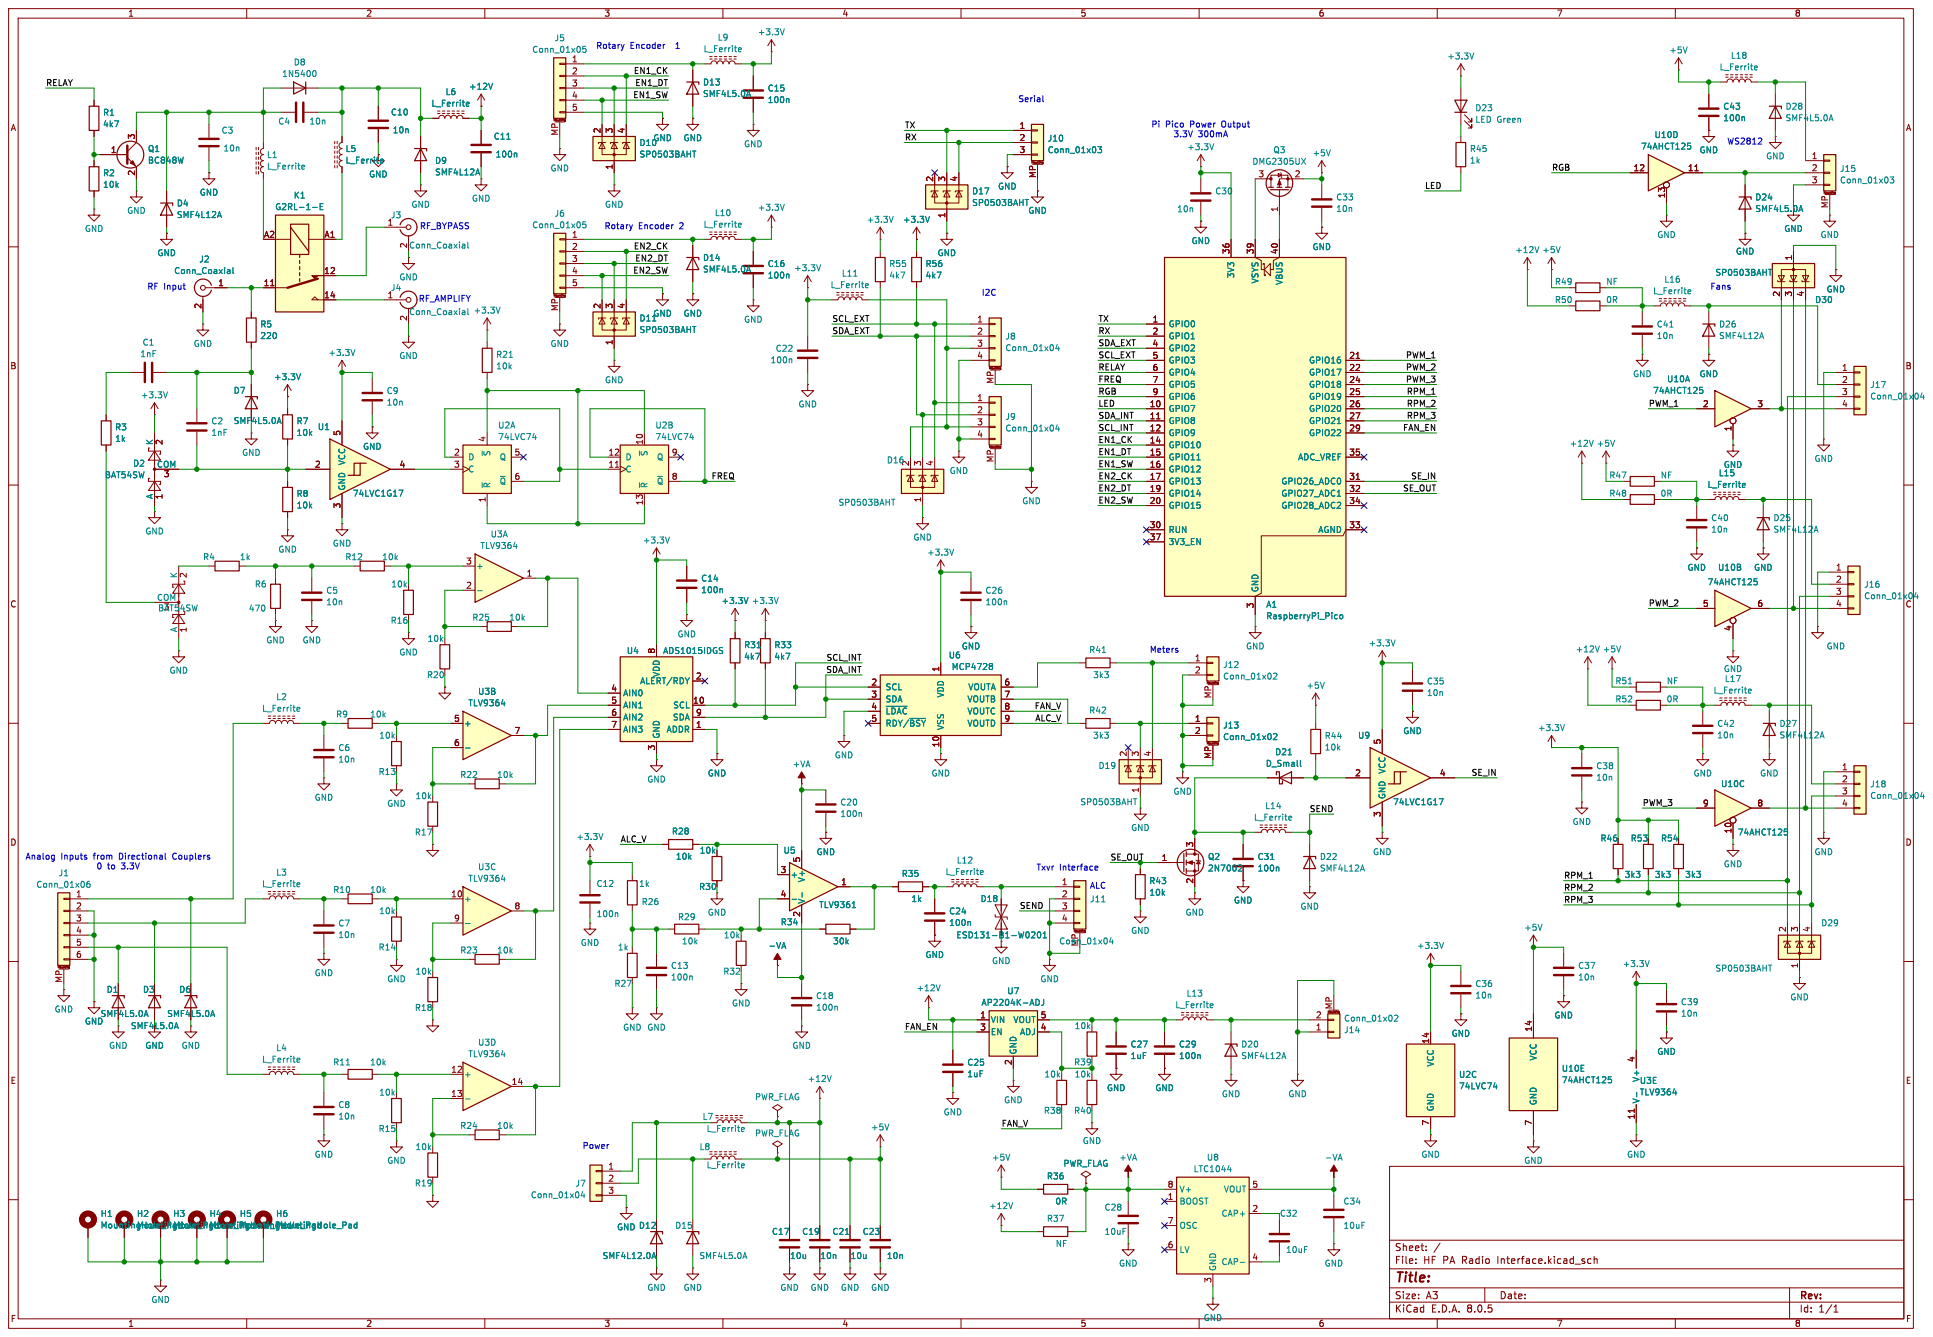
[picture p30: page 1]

1 VSS 10 SCL 2 SDA 3 ~{LDAC} 4 RDY/~{BSY} 5 VOUTA 6 VOUTB 7 VOUTC 8 VOUTD 9 U6MCP4728 H4 MountingHole_Pad GND

1 VSS 10 SCL 2 SDA 3 ~{LDAC} 4 RDY/~{BSY} 5 VOUTA 6 VOUTB 7 VOUTC 8 VOUTD 9 U4 ADS1015IDGS

3 AIN0 4 AIN1 5 AIN2 6 AIN3 7 VDD
ADDR 1 SCL 10 ALERT/RDY 2 GND

2 EN 3 ADJ 4 VOUT 5 U7 AP2204K-ADJ GND GND

74AHCT125 GND GND VCC 14 GND
74LVC74 VCC 14 GND

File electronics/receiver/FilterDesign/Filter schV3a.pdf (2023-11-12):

### S parameter simulation

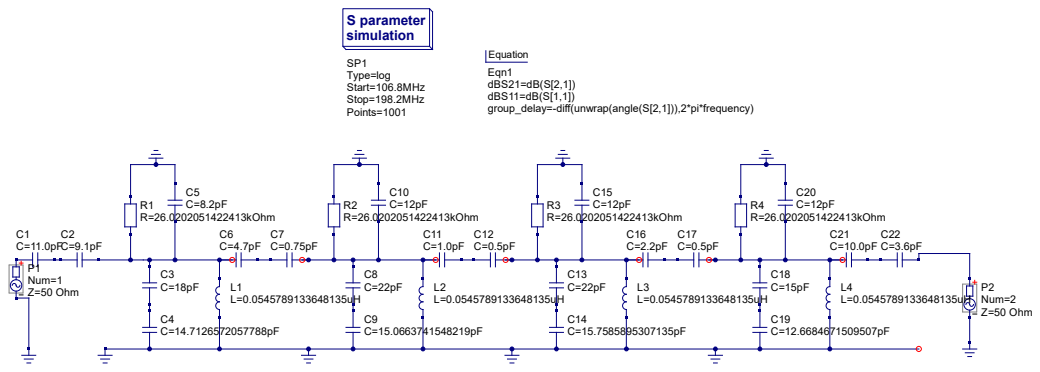
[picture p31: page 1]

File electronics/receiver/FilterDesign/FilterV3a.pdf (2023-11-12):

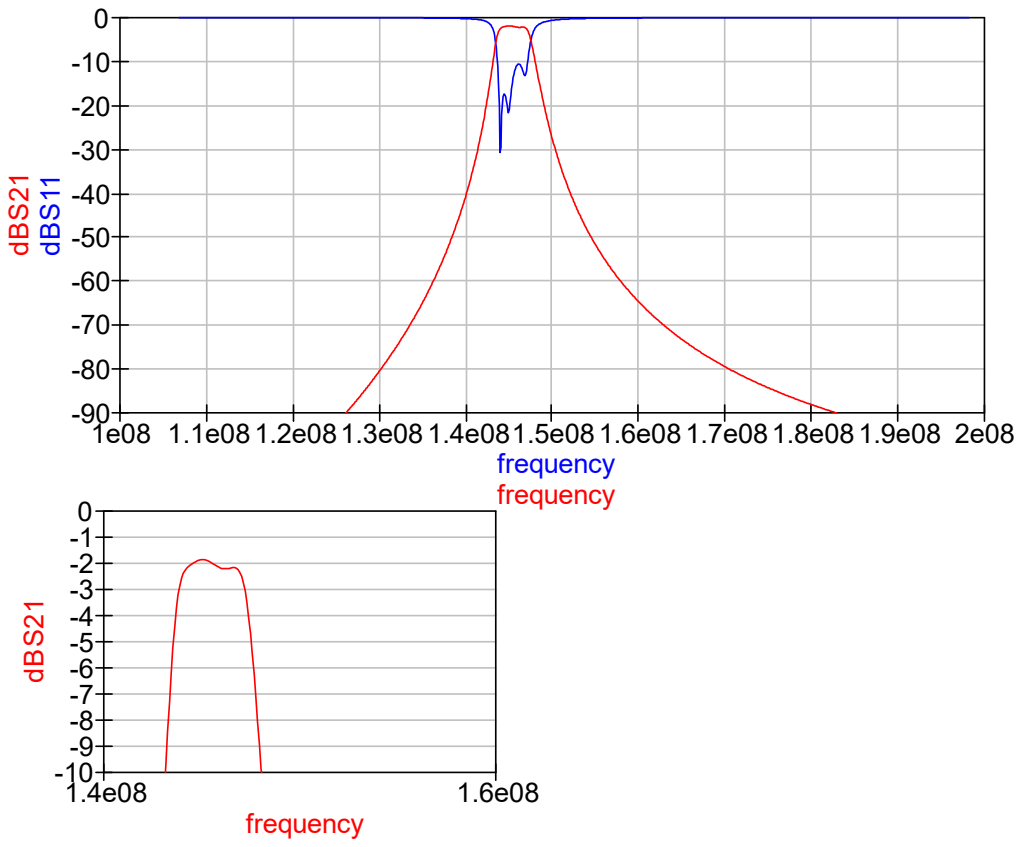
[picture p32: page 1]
frequency; frequency dBS²¹ dBS¹¹; frequency dBS²¹

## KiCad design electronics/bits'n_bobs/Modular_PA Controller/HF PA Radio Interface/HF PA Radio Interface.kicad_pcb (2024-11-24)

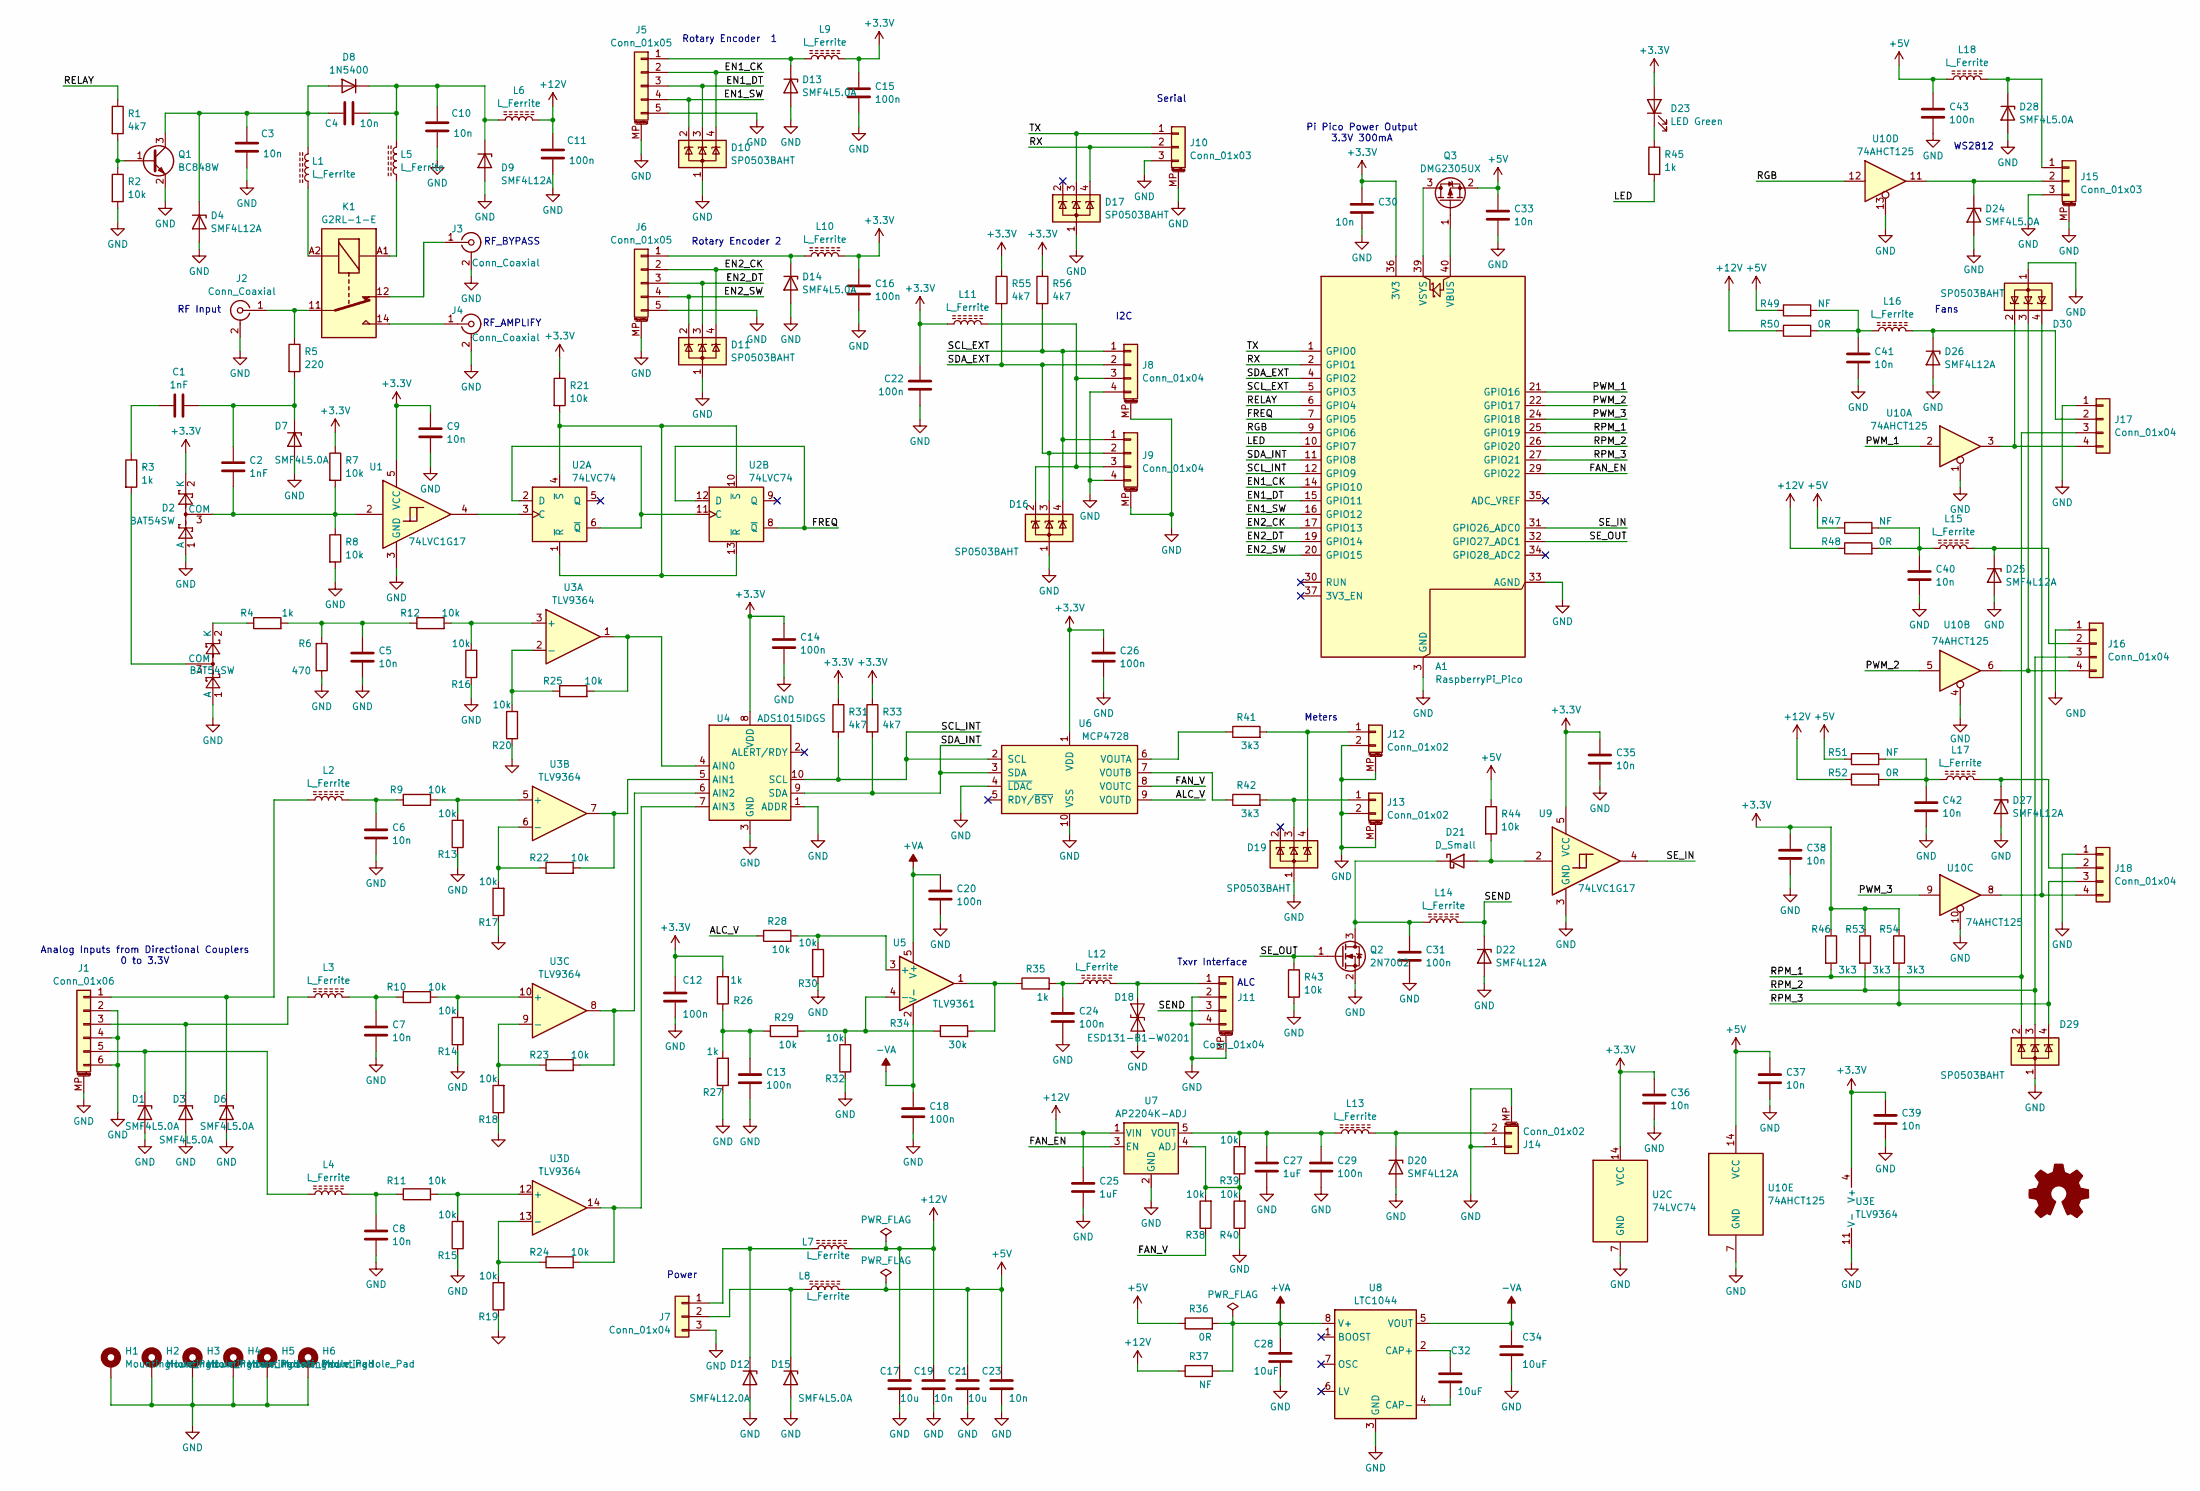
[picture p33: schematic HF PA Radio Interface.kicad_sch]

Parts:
A1: RaspberryPi_Pico; RPi_Pico_SMD_TH
C1, C2: 1nF; C_0603_1608Metric
C3, C4, C5, C6, C7, C8, C9, C10, C19, C23, C30, C33, C35, C36, C37, C38, C39, C40, C41, C42: 10n; C_0603_1608Metric
C11, C12, C13, C14, C15, C16, C18, C20, C22, C24, C26, C29, C31, C43: 100n; C_0603_1608Metric
C17, C21: 10u; C_0805_2012Metric
C25, C27: 1uF; C_0603_1608Metric
C28, C32, C34: 10uF; C_0603_1608Metric
D1, D3, D6, D7, D13, D14, D15, D24, D28: SMF4L5.0A; D_SOD-523
D2, D5: BAT54SW; SOT-323_SC-70
D4, D9, D20, D22, D25, D26, D27: SMF4L12A; D_SOD-523
D8: 1N5400; D_SOD-123
D10, D11, D16, D17, D19, D29, D30: SP0503BAHT; SOT-143
D12: SMF4L12.0A; D_SOD-523
D18: ESD131-B1-W0201; D_SOD-523
D21: D_Small; D_SOD-323
D23: LED Green; LED_0603_1608Metric
H1, H2, H3, H4, H5, H6: MountingHole_Pad; MountingHole_3.2mm_M3_DIN965_Pad
J1: Conn_01x06; JST_PH_S6B-PH-SM4-TB_1x06-1MP_P2.00mm_Horizontal
J2, J3, J4: Conn_Coaxial; SMA_Samtec_SMA-J-P-X-ST-EM1_EdgeMount
J5, J6: Conn_01x05; JST_PH_B5B-PH-SM4-TB_1x05-1MP_P2.00mm_Vertical
J7: Conn_01x04; JST_XH_S3B-XH-A_1x03_P2.50mm_Horizontal
J8, J9, J11: Conn_01x04; JST_PH_B4B-PH-SM4-TB_1x04-1MP_P2.00mm_Vertical
J10: Conn_01x03; JST_PH_B3B-PH-SM4-TB_1x03-1MP_P2.00mm_Vertical
J12, J13: Conn_01x02; JST_PH_B2B-PH-SM4-TB_1x02-1MP_P2.00mm_Vertical
J14: Conn_01x02; JST_PH_S2B-PH-SM4-TB_1x02-1MP_P2.00mm_Horizontal
J15: Conn_01x03; JST_PH_S3B-PH-SM4-TB_1x03-1MP_P2.00mm_Horizontal
J16, J17, J18: Conn_01x04; KF2510-4AW_3+1P
K1: G2RL-1-E; Relay_SPDT_Omron_G2RL-1-E
L1, L2, L3, L4, L5, L6, L7, L8, L9, L10, L11, L12, L13, L14, L15, L16, L17, L18: L_Ferrite; L_0603_1608Metric
Q1: BC848W; SOT-323_SC-70
Q2: 2N7002; SOT-23
Q3: DMG2305UX; SOT-23
R1, R31, R33, R55, R56: 4k7; R_0603_1608Metric
R2, R7, R8, R9, R10, R11, R12, R13, R14, R15, R16, R17, R18, R19, R20, R21, R22, R23, R24, R25, R28, R29, R30, R32, R38, R39, R40, R43, R44: 10k; R_0603_1608Metric
R3, R4, R26, R27, R35, R45: 1k; R_0603_1608Metric
R5: 220; R_0603_1608Metric
R6: 470; R_0603_1608Metric
R34: 30k; R_0603_1608Metric
R36, R48, R50, R52: 0R; R_0603_1608Metric
R37, R47, R49, R51: NF; R_0603_1608Metric
R41, R42, R46, R53, R54: 3k3; R_0603_1608Metric
SYM1: Logo_Open_Hardware_Small; OSHW-Logo2_7.3x6mm_SilkScreen
U1, U9: 74LVC1G17; SOT-353_SC-70-5
U2: 74LVC74; SOIC-14_3.9x8.7mm_P1.27mm
U3: TLV9364; SOIC-14_3.9x8.7mm_P1.27mm
U4: ADS1015IDGS; TSSOP-10_3x3mm_P0.5mm
U5: TLV9361; SOT-23-5
U6: MCP4728; MSOP-10_3x3mm_P0.5mm
U7: AP2204K-ADJ; SOT-23-5
U8: LTC1044; SOIC-8_5.23x5.23mm_P1.27mm
U10: 74AHCT125; TSSOP-14_4.4x5mm_P0.65mm

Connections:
+3.3V: A1.36 (3V3), C9.1, C12.1, C14.1, C15.1, C16.1, C22.1, C26.1, C30.1, C35.1, C36.1, C38.1, C39.1, D2.2 (K), D23.2 (A), L9.2, L10.2, L11.2, R7.1, R21.1, R26.2, R31.1, R33.1, R46.1, R53.1, R54.1, R55.1, R56.1, U1.5 (VCC), U2.14 (VCC), U3.4 (V+), U4.8 (VDD), U6.1 (VDD), U9.5 (VCC)
+5V: C21.1, C23.1, C33.1, C37.1, C43.1, L8.2, L18.1, Q3.2 (S), R36.1, R44.1, R47.1, R49.1, R51.1, U10.14 (VCC)
+12V: C11.1, C17.1, C19.1, C25.1, L6.2, L7.2, R37.1, R48.1, R50.1, R52.1, U7.1 (VIN)
+VA: C20.1, C28.1, R36.2, R37.2, U5.5 (V+), U8.8 (V+)
-VA: C18.1, C34.1, U5.2 (V-), U8.5 (VOUT)
/ALC_V: R28.1, U6.9 (VOUTD)
/EN1_CK: A1.14 (GPIO10), D10.4 (K), J5.2
/EN1_DT: A1.15 (GPIO11), D10.3 (K), J5.3
/EN1_SW: A1.16 (GPIO12), D10.2 (K), J5.4
/EN2_CK: A1.17 (GPIO13), D11.4 (K), J6.2
/EN2_DT: A1.19 (GPIO14), D11.3 (K), J6.3
/EN2_SW: A1.20 (GPIO15), D11.2 (K), J6.4
/FAN_EN: A1.29 (GPIO22), U7.3 (EN)
/FAN_V: R38.1, U6.8 (VOUTC)
/FREQ: A1.7 (GPIO5), U2.8 (~Q), U2.12 (D)
/LED: A1.10 (GPIO7), R45.2
/PWM_1: A1.21 (GPIO16), U10.2
/PWM_2: A1.22 (GPIO17), U10.5
/PWM_3: A1.24 (GPIO18), U10.9
/RELAY: A1.6 (GPIO4), R1.1
/RGB: A1.9 (GPIO6), U10.12
/RPM_1: A1.25 (GPIO19), D29.2 (K), J17.3, R46.2
/RPM_2: A1.26 (GPIO20), D29.3 (K), J16.3, R53.2
/RPM_3: A1.27 (GPIO21), D29.4 (K), J18.3, R54.2
/RX: A1.2 (GPIO1), D17.4 (K), J10.2
/SCL_EXT: A1.5 (GPIO3), D16.4 (K), J8.1, J9.1, R56.2
/SCL_INT: A1.12 (GPIO9), R31.2, U4.10 (SCL), U6.2 (SCL)
/SDA_EXT: A1.4 (GPIO2), D16.3 (K), J8.2, J9.2, R55.2
/SDA_INT: A1.11 (GPIO8), R33.2, U4.9 (SDA), U6.3 (SDA)
/SEND: D22.1 (K), J11.3, L14.2
/SE_IN: A1.31 (GPIO26_ADC0), U9.4
/SE_OUT: A1.32 (GPIO27_ADC1), Q2.1 (G), R43.1
/TX: A1.1 (GPIO0), D17.3 (K), J10.1
GND: A1.3 (GND), A1.8 (GND), A1.13 (GND), A1.18 (GND), A1.23 (GND), A1.28 (GND), A1.33 (AGND), A1.38 (GND), C3.2, C5.2, C6.2, C7.2, C8.2, C9.2, C10.2, C11.2, C12.2, C13.2, C14.2, C15.2, C16.2, C17.2, C18.2, C19.2, C20.2, C21.2, C22.2, C23.2, C24.2, C25.2, C26.2, C27.2, C28.2, C29.2, C30.2, C31.2, C33.2, C34.2, C35.2, C36.2, C37.2, C38.2, C39.2, C40.2, C41.2, C42.2, C43.2, D1.2 (A), D2.1 (A), D3.2 (A), D4.2 (A), D5.1 (A), D6.2 (A), D7.2 (A), D9.2 (A), D10.1 (A), D11.1 (A), D12.2 (A), D13.2 (A), D14.2 (A), D15.2 (A), D16.1 (A), D17.1 (A), D18.1 (A1), D19.1 (A), D20.2 (A), D22.2 (A), D24.2 (A), D25.2 (A), D26.2 (A), D27.2 (A), D28.2 (A), D29.1 (A), D30.1 (A), H1.1, H2.1, H3.1, H4.1, H5.1, H6.1, J1.2, J1.4, J1.6, J1.MP (MountPin), J2.2 (Ext), J3.2 (Ext), J4.2 (Ext), J5.5, J5.MP (MountPin), J6.5, J6.MP (MountPin), J7.3, J8.4, J8.MP (MountPin), J9.4, J9.MP (MountPin), J10.3, J10.MP (MountPin), J11.2, J11.4, J11.MP (MountPin), J12.2, J12.MP (MountPin), J13.2, J13.MP (MountPin), J14.1, J14.MP (MountPin), J15.3, J15.MP (MountPin), J16.1, J17.1, J18.1, Q1.2 (E), Q2.2 (S), R2.2, R6.2, R8.2, R13.1, R14.1, R15.1, R16.1, R17.1, R18.1, R19.1, R20.1, R27.1, R30.1, R32.1, R40.1, R43.2, U1.3 (GND), U2.7 (GND), U3.11 (V-), U4.1 (ADDR), U4.3 (GND), U6.4 (~LDAC), U6.10 (VSS), U7.2 (GND), U8.3 (GND), U9.3 (GND), U10.1, U10.4, U10.7 (GND), U10.10, U10.13
unnamed: A1.40 (VBUS), Q3.1 (G)
unnamed: A1.39 (VSYS), Q3.3 (D)
unnamed: C1.2, R3.1
unnamed: C5.1, R4.2, R6.1, R12.1
unnamed: C6.1, L2.2, R9.1
unnamed: C7.1, L3.2, R10.1
unnamed: C8.1, L4.2, R11.1
unnamed: C13.1, R26.1, R27.2, R29.1
unnamed: C24.1, L12.1, R35.2
unnamed: C40.1, L15.1, R47.2, R48.2
unnamed: C41.1, L16.1, R49.2, R50.2
unnamed: C42.1, L17.1, R51.2, R52.2
unnamed: D1.1 (K), J1.5, L4.1
unnamed: C2.2, D2.3 (COM), R7.2, R8.1, U1.2
unnamed: D3.1 (K), J1.3, L3.1
unnamed: C3.1, C4.1, D4.1 (K), D8.2 (A), L1.2, Q1.3 (C)
unnamed: D5.3 (COM), R3.2
unnamed: D5.2 (K), R4.1
unnamed: D6.1 (K), J1.1, L2.1
unnamed: C1.1, C2.1, D7.1 (K), R5.2
unnamed: C4.2, C10.1, D8.1 (K), D9.1 (K), L5.2, L6.1
unnamed: D12.1 (K), J7.1, L7.1
unnamed: D13.1 (K), J5.1, L9.1
unnamed: D14.1 (K), J6.1, L10.1
unnamed: D15.1 (K), J7.2, L8.1
unnamed: D18.2 (A2), J11.1, L12.2
unnamed: D20.1 (K), J14.2, L13.2
unnamed: D21.2 (A), R44.2, U9.2
unnamed: C31.1, D21.1 (K), L14.1, Q2.3 (D)
unnamed: D23.1 (K), R45.1
unnamed: D24.1 (K), J15.2, U10.11
unnamed: D25.1 (K), J16.2, L15.2
unnamed: D26.1 (K), J17.2, L16.2
unnamed: D27.1 (K), J18.2, L17.2
unnamed: D28.1 (K), J15.1, L18.2
unnamed: J2.1 (In), K1.11, R5.1
unnamed: J3.1 (In), K1.12
unnamed: J4.1 (In), K1.14
unnamed: D16.2 (K), J8.3, J9.3, L11.1
unnamed: D19.4 (K), J12.1, R41.2
unnamed: D19.3 (K), J13.1, R42.2
unnamed: D30.3 (K), J16.4, U10.6
unnamed: D30.2 (K), J17.4, U10.3
unnamed: D30.4 (K), J18.4, U10.8
unnamed: K1.A1, L5.1
unnamed: K1.A2, L1.1
unnamed: Q1.1 (B), R1.2, R2.1
unnamed: R34.2, R35.1, U5.1
unnamed: U1.4, U2.3 (C)
unnamed: U2.2 (D), U2.6 (~Q), U2.11 (C)
unnamed: R21.2, U2.1 (~R), U2.4 (~S), U2.10 (~S), U2.13 (~R)
unnamed: R12.2, R16.2, U3.3 (+)
unnamed: R20.2, R25.1, U3.2 (-)
unnamed: R9.2, R13.2, U3.5 (+)
unnamed: R17.2, R22.1, U3.6 (-)
unnamed: R10.2, R14.2, U3.10 (+)
unnamed: R18.2, R23.1, U3.9 (-)
unnamed: R11.2, R15.2, U3.12 (+)
unnamed: R19.2, R24.1, U3.13 (-)
unnamed: R25.2, U3.1, U4.4 (AIN0)
unnamed: R22.2, U3.7, U4.5 (AIN1)
unnamed: R23.2, U3.8, U4.6 (AIN2)
unnamed: R24.2, U3.14, U4.7 (AIN3)
unnamed: R28.2, R30.2, U5.3 (+)
unnamed: R29.2, R32.2, R34.1, U5.4 (-)
unnamed: R41.1, U6.6 (VOUTA)
unnamed: R42.1, U6.7 (VOUTB)
unnamed: R38.2, R39.1, R40.2, U7.4 (ADJ)
unnamed: C27.1, C29.1, L13.1, R39.2, U7.5 (VOUT)
unnamed: C32.1, U8.2 (CAP+)
unnamed: C32.2, U8.4 (CAP-)

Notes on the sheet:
Rotary Encoder 2
RF Input
Fans
Txvr Interface
ALC
RF_BYPASS
Serial
RF_AMPLIFY
Rotary Encoder 1
Analog Inputs from Directional Couplers 0 to 3.3V
Power
Meters
WS2812
Pi Pico Power Output 3.3V 300mA
I2C

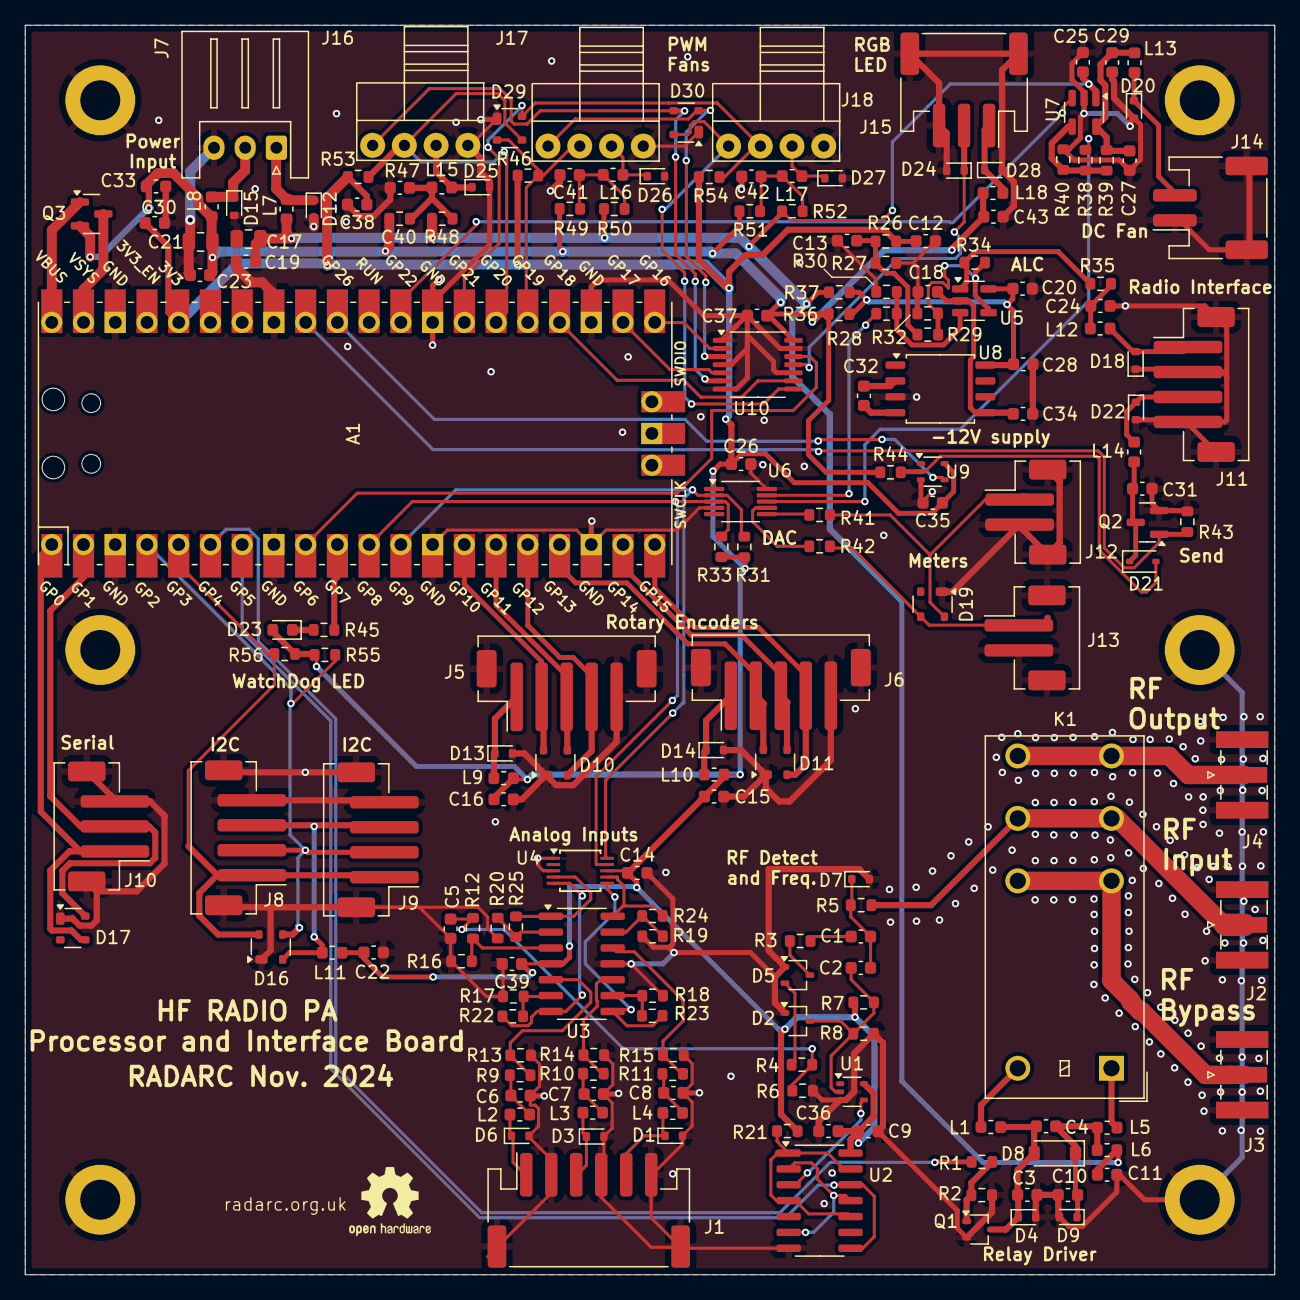
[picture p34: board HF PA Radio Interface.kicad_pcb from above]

Board: 2 copper layers, 100.0 x 100.0 mm, 187 parts (0 on the bottom side), 105 nets.

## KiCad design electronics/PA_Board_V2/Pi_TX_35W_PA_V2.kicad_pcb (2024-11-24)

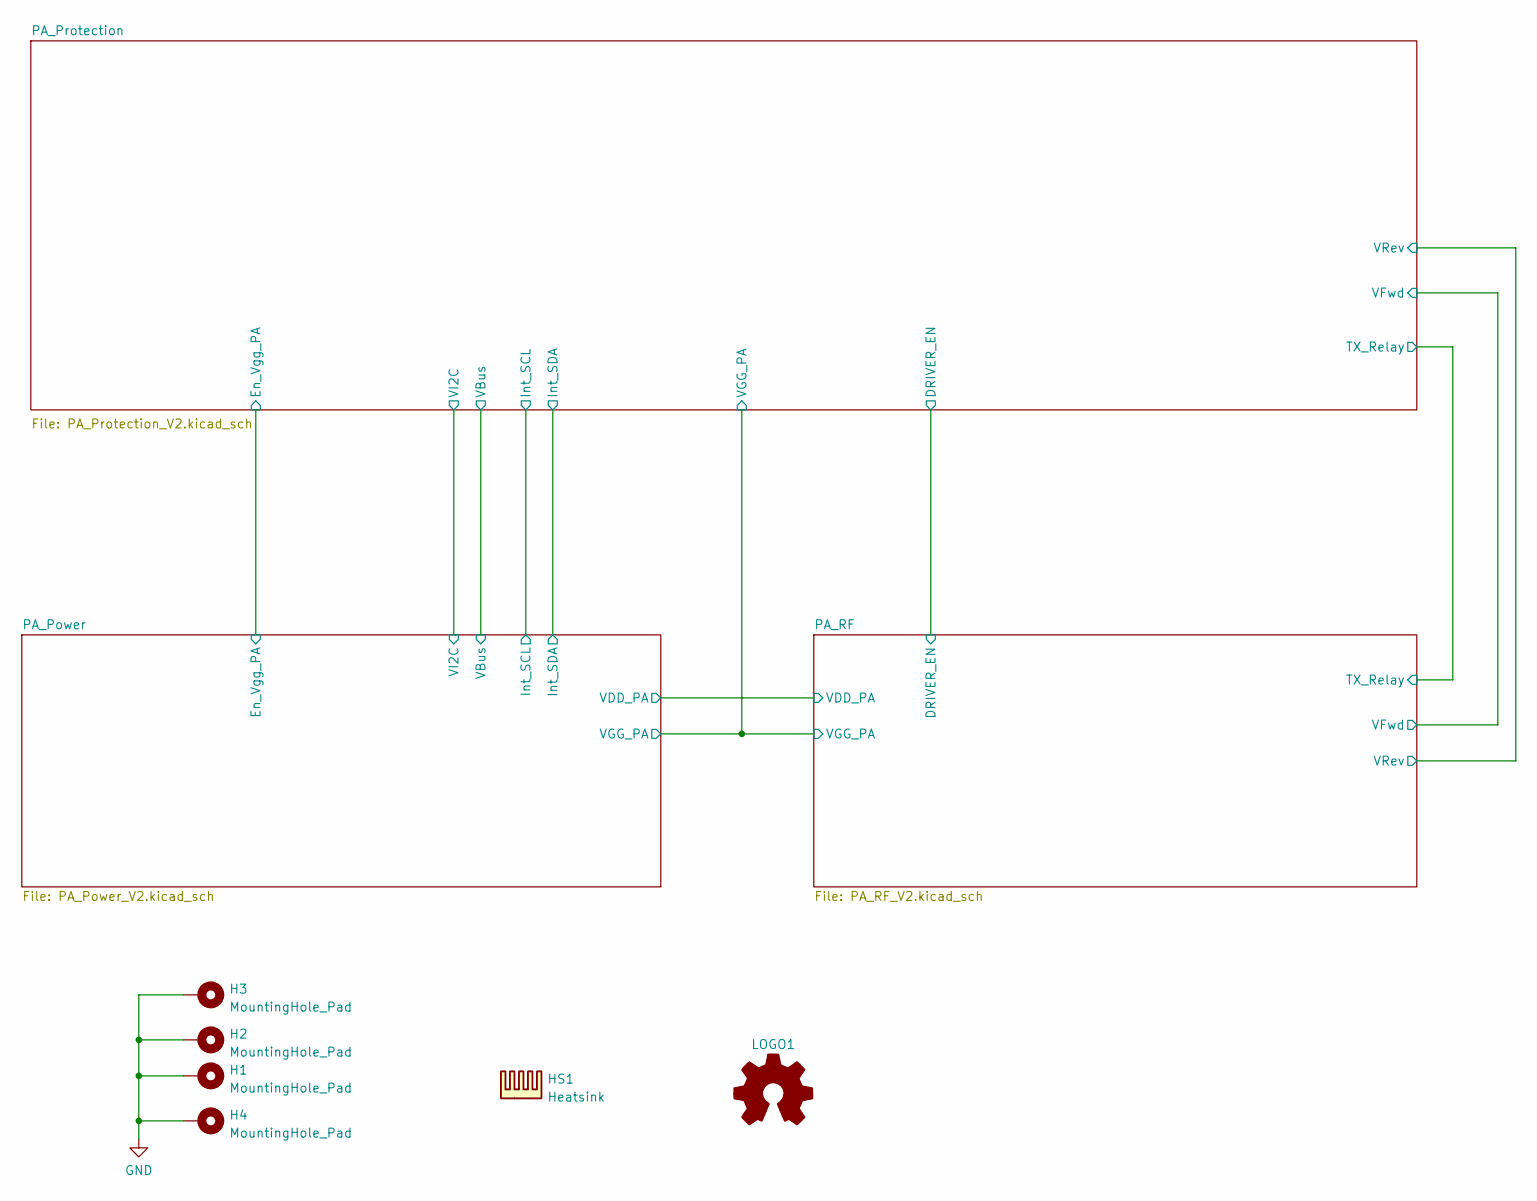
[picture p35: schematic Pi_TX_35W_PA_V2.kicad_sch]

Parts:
H1, H2, H3, H4: MountingHole_Pad; MountingHole_3.2mm_M3_DIN965_Pad
HS1: Heatsink; Copper_Pad
LOGO1: Logo_Open_Hardware_Small; OSHW-Logo2_9.8x8mm_SilkScreen

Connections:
GND: H1.1, H2.1, H3.1, H4.1; also elsewhere on the board

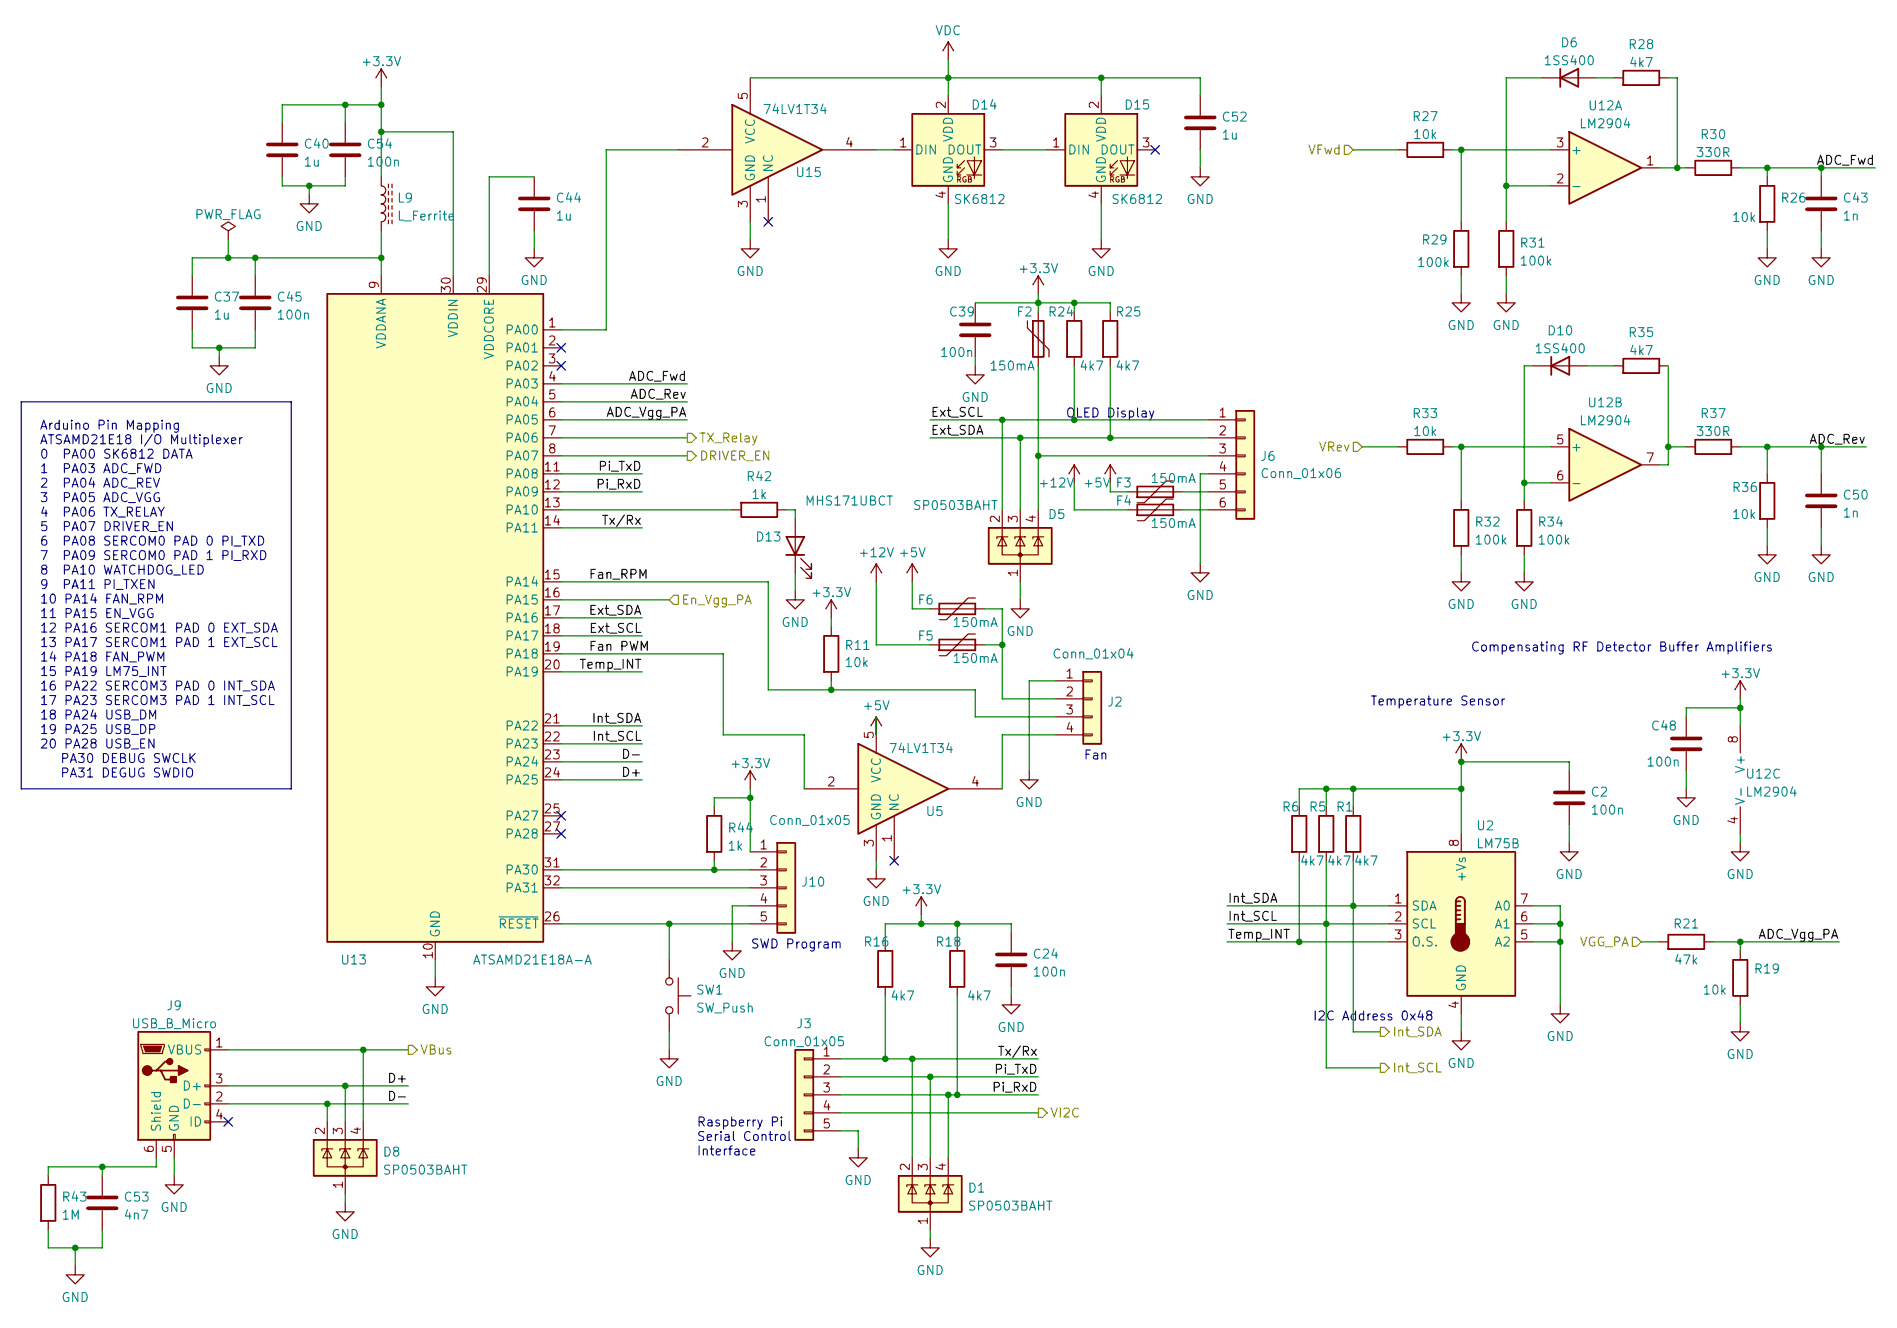
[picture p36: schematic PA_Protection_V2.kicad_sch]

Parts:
C2, C24, C39, C45, C48, C54: 100n; C_0603_1608Metric; LCSC Part C88136
C37, C40, C44, C52: 1u; C_0603_1608Metric; LCSC Part C89376
C43, C50: 1n; C_0603_1608Metric; LCSC Part C2839443
C53: 4n7; C_0603_1608Metric; LCSC Part C576815
D1, D5, D8: SP0503BAHT; SOT-143; LCSC Part C2682275
D6, D10: 1SS400; D_SOD-523; LCSC Part C68951
D13: MHS171UBCT; MHS171; LCSC Part C693906
D14, D15: SK6812; SK6812SIDE-A-RVS; LCSC Part C2890037
F2, F3, F4, F5, F6: 150mA; Fuse_0805_2012Metric; LCSC Part C2840556
J2: Conn_01x04; KF2510-4AW_3+1P
J3: Conn_01x05; JST_PH_S5B-PH-SM4-TB_1x05-1MP_P2.00mm_Horizontal; LCSC Part C7429692
J6: Conn_01x06; JST_PH_S6B-PH-SM4-TB_1x06-1MP_P2.00mm_Horizontal; LCSC Part C7429693
J9: USB_B_Micro; USB_Micro-B_Molex-105017-0001; LCSC Part C136000
J10: Conn_01x05; Debug_Clip
L9: L_Ferrite; L_0603_1608Metric; LCSC Part C98298
R1, R5, R6, R16, R18, R24, R25, R28, R35: 4k7; R_0603_1608Metric; LCSC Part C23162
R11, R19, R26, R27, R33, R36: 10k; R_0603_1608Metric; LCSC Part C25804
R21: 47k; R_0603_1608Metric; LCSC Part C25819
R29, R31, R32, R34: 100k; R_0603_1608Metric; LCSC Part C25803
R30, R37: 330R; R_0603_1608Metric; LCSC Part C23138
R42, R44: 1k; R_0603_1608Metric; LCSC Part C21190
R43: 1M; R_0603_1608Metric; LCSC Part C22935
SW1: SW_Push; Panasonic_EVQPUK_EVQPUB; LCSC Part C526225
U2: LM75B; SOIC-8_3.9x4.9mm_P1.27mm; LCSC Part C725792
U5, U15: 74LV1T34; SOT-353_SC-70-5; LCSC Part C5199768
U12: LM2904; SOIC-8_3.9x4.9mm_P1.27mm; LCSC Part C2941725
U13: ATSAMD21E18A-A; TQFP-32_7x7mm_P0.8mm; LCSC Part C618770

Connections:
+3.3V: C2.1, C24.1, C39.1, C40.1, C48.1, C54.1, F2.1, J10.1, L9.1, R1.1, R5.1, R6.1, R11.1, R16.1, R18.1, R24.1, R25.1, R44.1, U2.8 (+Vs), U12.8 (V+), U13.30 (VDDIN); also elsewhere on the board
+5V: F3.1, F6.1, U5.5 (VCC); also elsewhere on the board
+12V: F4.1, F5.1; also elsewhere on the board
/PA_Power/En_Vgg_PA: U13.16 (PA15); also elsewhere on the board
/PA_Power/Int_SCL: R5.2, U2.2 (SCL), U13.22 (PA23); also elsewhere on the board
/PA_Power/Int_SDA: R1.2, U2.1 (SDA), U13.21 (PA22); also elsewhere on the board
/PA_Power/VBus: D8.4 (K), J9.1 (VBUS); also elsewhere on the board
/PA_Power/VGG_PA: R21.2; also elsewhere on the board
/PA_Power/VI2C: J3.4; also elsewhere on the board
/PA_Protection/ADC_Fwd: C43.1, R26.1, R30.2, U13.4 (PA03)
/PA_Protection/ADC_Rev: C50.1, R36.1, R37.2, U13.5 (PA04)
/PA_Protection/ADC_Vgg_PA: R19.1, R21.1, U13.6 (PA05)
/PA_Protection/D+: D8.3 (K), J9.3 (D+), U13.24 (PA25)
/PA_Protection/D-: D8.2 (K), J9.2 (D-), U13.23 (PA24)
/PA_Protection/DRIVER_EN: U13.8 (PA07); also elsewhere on the board
/PA_Protection/Ext_SCL: D5.2 (K), J6.1, R24.2, U13.18 (PA17)
/PA_Protection/Ext_SDA: D5.3 (K), J6.2, R25.2, U13.17 (PA16)
/PA_Protection/Fan PWM: U5.2, U13.19 (PA18)
/PA_Protection/Fan_RPM: J2.3, R11.2, U13.15 (PA14)
/PA_Protection/Pi_RxD: D1.4 (K), J3.3, R18.2, U13.12 (PA09)
/PA_Protection/Pi_TxD: D1.3 (K), J3.2, U13.11 (PA08)
/PA_Protection/TX_Relay: U13.7 (PA06); also elsewhere on the board
/PA_Protection/Temp_INT: R6.2, U2.3 (O.S.), U13.20 (PA19)
/PA_Protection/Tx/Rx: D1.2 (K), J3.1, R16.2, U13.14 (PA11)
/PA_Protection/VFwd: R27.1; also elsewhere on the board
/PA_Protection/VRev: R33.1; also elsewhere on the board
GND: C2.2, C24.2, C37.2, C39.2, C40.2, C43.2, C44.2, C45.2, C48.2, C50.2, C52.2, C53.2, C54.2, D1.1 (A), D5.1 (A), D8.1 (A), D13.1 (K), D14.4 (GND), D15.4 (GND), J2.1, J3.5, J6.4, J9.5 (GND), J10.4, R19.2, R26.2, R29.2, R31.2, R32.2, R34.2, R36.2, R43.2, SW1.2, U2.4 (GND), U2.5 (A2), U2.6 (A1), U2.7 (A0), U5.3 (GND), U12.4 (V-), U13.10 (GND), U13.28 (GND), U15.3 (GND); also elsewhere on the board
unnamed: D6.2 (A), R28.2
unnamed: D6.1 (K), R31.1, U12.2 (-)
unnamed: D10.2 (A), R35.2
unnamed: D10.1 (K), R34.1, U12.6 (-)
unnamed: D13.2 (A), R42.1
unnamed: D14.1 (DIN), U15.4
unnamed: D14.3 (DOUT), D15.1 (DIN)
unnamed: F5.2, F6.2, J2.2
unnamed: J2.4, U5.4
unnamed: D5.4 (K), F2.2, J6.3
unnamed: F3.2, J6.5
unnamed: F4.2, J6.6
unnamed: C53.1, J9.6 (Shield), R43.1
unnamed: J10.2, R44.2, U13.31 (PA30)
unnamed: J10.3, U13.32 (PA31)
unnamed: J10.5, SW1.1, U13.26 (~RESET)
unnamed: R28.1, R30.1, U12.1
unnamed: R35.1, R37.1, U12.7
unnamed: R27.2, R29.1, U12.3 (+)
unnamed: R32.1, R33.2, U12.5 (+)
unnamed: U13.1 (PA00), U15.2
unnamed: R42.2, U13.13 (PA10)
unnamed: C37.1, C45.1, L9.2, U13.9 (VDDANA)
unnamed: C44.1, U13.29 (VDDCORE)
VDC: C52.1, D14.2 (VDD), D15.2 (VDD), U15.5 (VCC); also elsewhere on the board

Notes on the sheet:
OLED Display
I2C Address 0x48
Arduino Pin Mapping ATSAMD21E18 I/O Multiplexer 0 PA00 SK6812 DATA 1 PA03 ADC_FWD 2 PA04 ADC_REV 3 PA05 ADC_VGG 4 PA06 TX_RELAY 5 PA07 DRIVER_EN 6 PA08 SERCOM0 PAD 0 PI_TXD 7 PA09 SERCOM0 PAD 1 PI_RXD 8 PA10 WATCHDOG_LED 9 PA11 PI_TXEN 10 PA14 FAN_RPM 11 PA15 EN_VGG 12 PA16 SERCOM1 PAD 0 EXT_SDA 13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
Temperature Sensor
Raspberry Pi Serial Control Interface
Fan
SWD Program
Compensating RF Detector Buffer Amplifiers

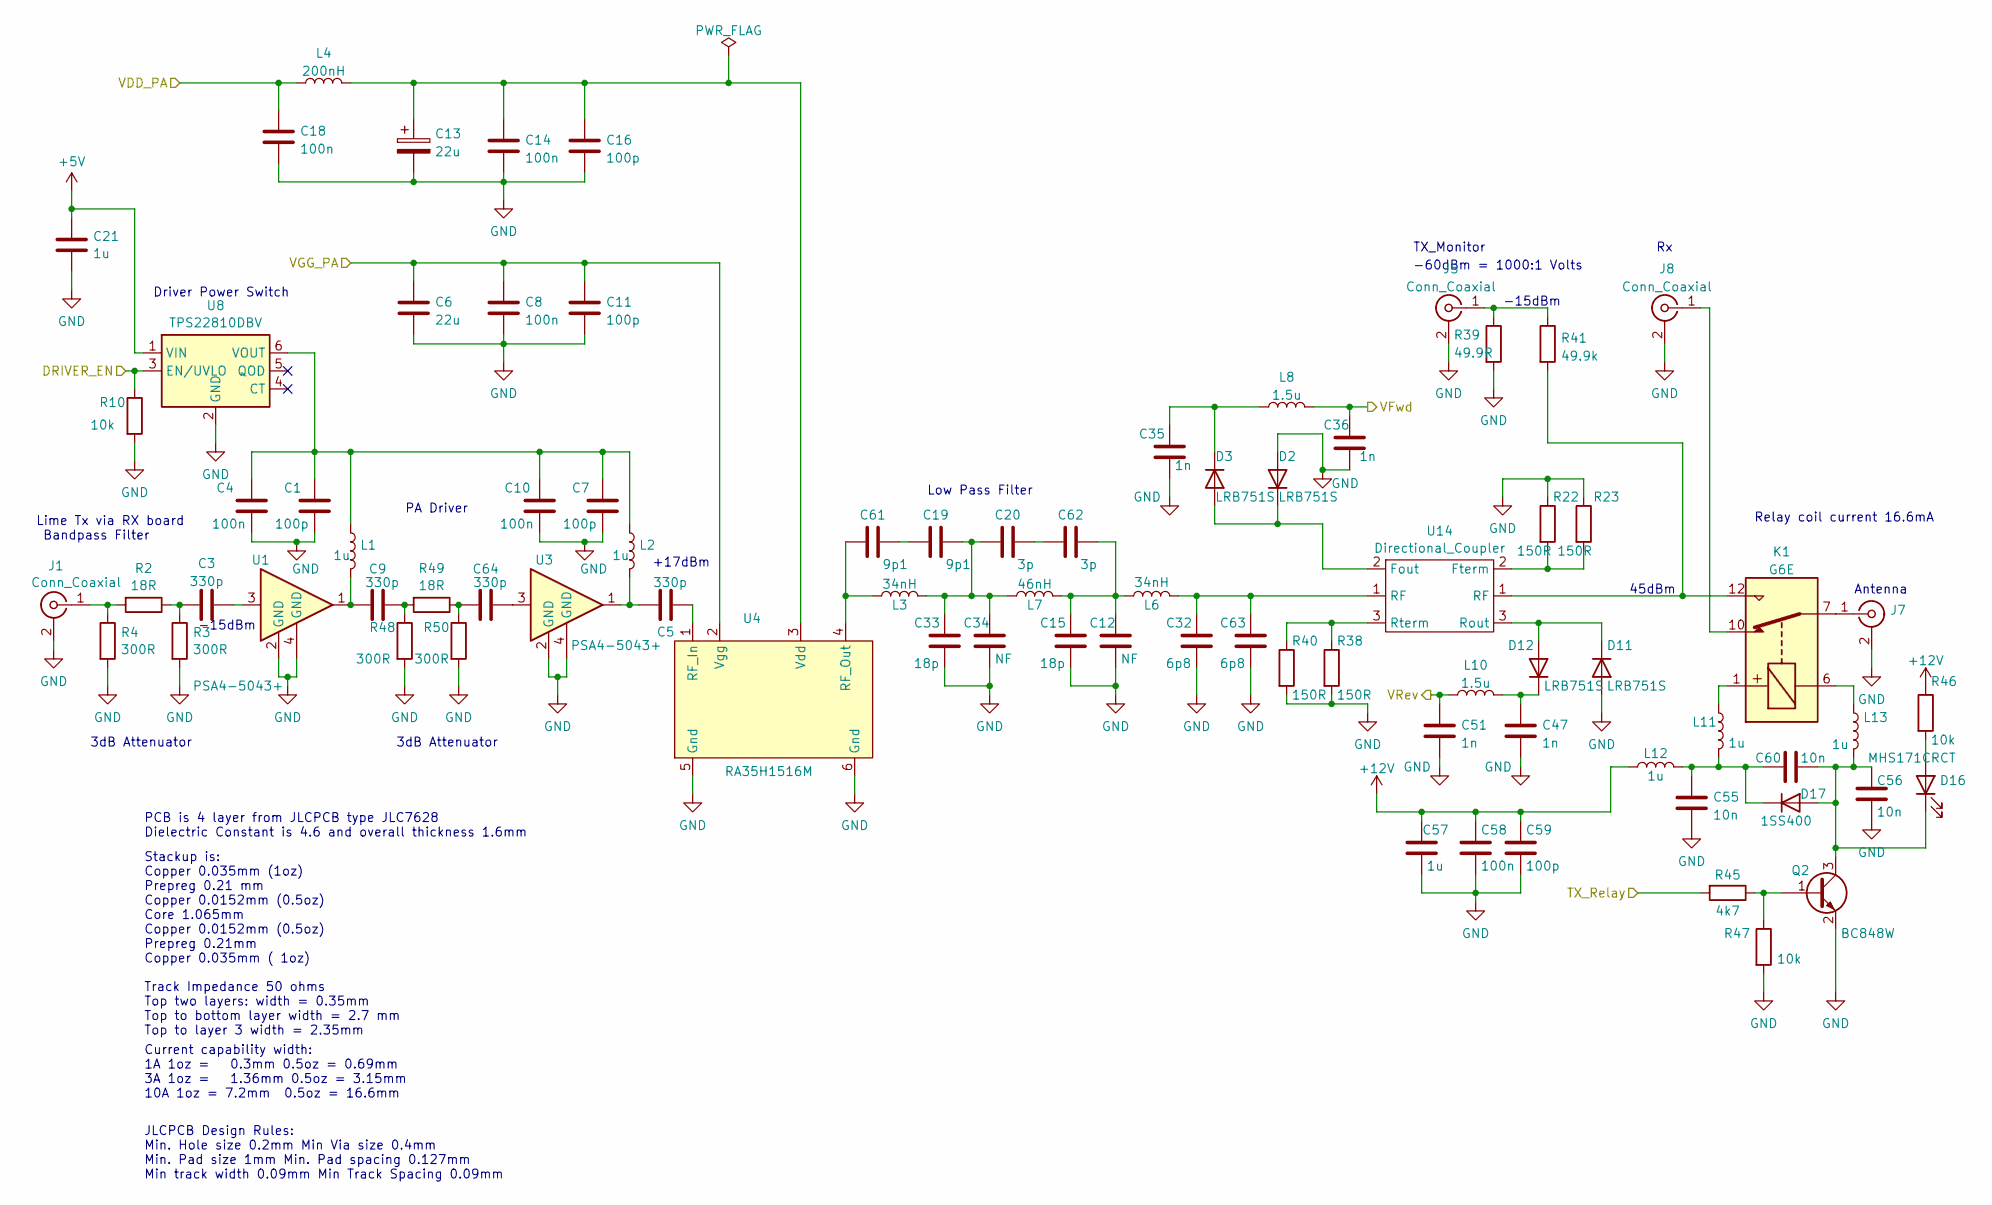
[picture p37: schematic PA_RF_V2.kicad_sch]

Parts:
C1, C7, C11, C16, C59: 100p; C_0603_1608Metric; LCSC Part C296046
C3, C5, C9, C64: 330p; C_0603_1608Metric; LCSC Part C458903
C4, C8, C10, C14, C18, C58: 100n; C_0603_1608Metric; LCSC Part C88136
C6: 22u; C_0805_2012Metric; LCSC Part C602037
C12, C34: NF; C_1206_3216Metric
C13: 22u; CP_EIA-7343-43_Kemet-X; LCSC Part C1956447
C15, C33: 18p; C_1206_3216Metric
C19, C61: 9p1; C_1206_3216Metric
C20, C62: 3p; C_1206_3216Metric
C21: 1u; C_0603_1608Metric; LCSC Part C88136
C32, C63: 6p8; C_1206_3216Metric
C35, C36, C47, C51: 1n; C_0603_1608Metric; LCSC Part C2839443
C55, C56, C60: 10n; C_0603_1608Metric; LCSC Part C2215227
C57: 1u; C_0603_1608Metric; LCSC Part C89376
D2, D3, D11, D12: LRB751S; D_SOD-523; LCSC Part C113407
D16: MHS171CRCT; MHS171; LCSC Part C693903
D17: 1SS400; D_SOD-523; LCSC Part C68951
J1, J5, J7, J8: Conn_Coaxial; SMA_Samtec_SMA-J-P-X-ST-EM1_EdgeMount; LCSC Part C496550
K1: G6E; Relay_SPDT_Omron_G6E; LCSC Part C1525391
L1, L2, L11, L12, L13: 1u; L_0805_2012Metric; LCSC Part C703134
L3, L6: 34nH; Wire_Inductor 12x8.5
L4: 200nH; L_1812_4532Metric; LCSC Part C2858475
L7: 46nH; Wire_Inductor 15.5x8.5
L8, L10: 1.5u; L_0805_2012Metric; LCSC Part C139220
Q2: BC848W; SOT-323_SC-70; LCSC Part C549496
R2, R49: 18R; R_0603_1608Metric; LCSC Part C245924
R3, R4, R48, R50: 300R; R_0603_1608Metric; LCSC Part C2930092
R10, R46, R47: 10k; R_0603_1608Metric; LCSC Part C25804
R22, R23, R38, R40: 150R; R_0603_1608Metric; LCSC Part C22808
R39: 49.9R; R_0603_1608Metric; LCSC Part C23185
R41: 49.9k; R_0603_1608Metric; LCSC Part C23184
R45: 4k7; R_0603_1608Metric; LCSC Part C23162
U1, U3: PSA4-5043+; SOT-343_SC-70-4; LCSC Part C5240848
U4: RA35H1516M; RF_PA_Module
U8: TPS22810DBV; SOT-23-6; LCSC Part C205990
U14: Directional_Coupler; Linear_Coupler

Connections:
+5V: C21.1, U8.1 (VIN); also elsewhere on the board
+12V: C57.1, C58.1, C59.1, L12.1, R46.1; also elsewhere on the board
/PA_Power/VDD_PA: C18.1, L4.1; also elsewhere on the board
/PA_Power/VGG_PA: C6.1, C8.1, C11.1, U4.2 (Vgg); also elsewhere on the board
/PA_Protection/DRIVER_EN: R10.1, U8.3 (EN/UVLO); also elsewhere on the board
/PA_Protection/TX_Relay: R45.2; also elsewhere on the board
/PA_Protection/VFwd: C36.1, L8.2; also elsewhere on the board
/PA_Protection/VRev: C51.1, L10.1; also elsewhere on the board
GND: C1.1, C4.1, C6.2, C7.1, C8.2, C10.1, C11.2, C12.2, C13.2, C14.2, C15.2, C16.2, C18.2, C21.2, C32.2, C33.2, C34.2, C35.2, C36.2, C47.2, C51.2, C55.2, C56.2, C57.2, C58.2, C59.2, C63.2, D2.2 (A), D11.2 (A), J1.2 (Ext), J5.2 (Ext), J7.2 (Ext), J8.2 (Ext), Q2.2 (E), R3.2, R4.2, R10.2, R22.1, R23.1, R38.2, R39.2, R40.2, R47.2, R48.2, R50.2, U1.2 (GND), U1.4 (GND), U3.2 (GND), U3.4 (GND), U4.5 (Gnd), U4.6 (Gnd), U8.2 (GND); also elsewhere on the board
unnamed: C3.1, U1.3
unnamed: C3.2, R2.1, R3.1
unnamed: C5.2, L2.2, U3.1
unnamed: C9.1, R48.1, R49.2
unnamed: C9.2, L1.2, U1.1
unnamed: C12.1, C15.1, C62.2, L6.1, L7.2
unnamed: C19.1, C61.2
unnamed: C19.2, C20.1, C33.1, C34.1, L3.2, L7.1
unnamed: C20.2, C62.1
unnamed: C64.1, U3.3
unnamed: C64.2, R49.1, R50.1
unnamed: C35.1, D3.1 (K), L8.1
unnamed: C47.1, D12.1 (K), L10.2
unnamed: D16.2 (A), R46.2
unnamed: C56.1, C60.1, D16.1 (K), D17.2 (A), L13.2, Q2.3 (C)
unnamed: C55.1, C60.2, D17.1 (K), L11.2, L12.2
unnamed: J1.1 (In), R2.2, R4.1
unnamed: J5.1 (In), R39.1, R41.1
unnamed: J7.1 (In), K1.7
unnamed: J8.1 (In), K1.10
unnamed: K1.1, L11.1
unnamed: K1.6, L13.1
unnamed: Q2.1 (B), R45.1, R47.1
unnamed: C5.1, U4.1 (RF_In)
unnamed: C61.1, L3.1, U4.4 (RF_Out)
unnamed: C13.1, C14.1, C16.1, L4.2, U4.3 (Vdd)
unnamed: C1.2, C4.2, C7.2, C10.2, L1.1, L2.1, U8.6 (VOUT)

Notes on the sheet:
3dB Attenuator
JLCPCB Design Rules: Min. Hole size 0.2mm Min Via size 0.4mm Min. Pad size 1mm Min. Pad spacing 0.127mm Min track width 0.09mm Min Track Spacing 0.09mm
Driver Power Switch
+17dBm
Stackup is: Copper 0.035mm (1oz) Prepreg 0.21 mm Copper 0.0152mm (0.5oz) Core 1.065mm Copper 0.0152mm (0.5oz) Prepreg 0.21mm Copper 0.035mm ( 1oz)
Current capability width: 1A 1oz = 0.3mm 0.5oz = 0.69mm 3A 1oz = 1.36mm 0.5oz = 3.15mm 10A 1oz = 7.2mm 0.5oz = 16.6mm
Antenna
TX_Monitor
45dBm
Lime Tx via RX board Bandpass Filter
-15dBm
Low Pass Filter
-60dBm = 1000:1 Volts
Track Impedance 50 ohms Top two layers: width = 0.35mm Top to bottom layer width = 2.7 mm Top to layer 3 width = 2.35mm
Relay coil current 16.6mA
PCB is 4 layer from JLCPCB type JLC7628 Dielectric Constant is 4.6 and overall thickness 1.6mm
PA Driver

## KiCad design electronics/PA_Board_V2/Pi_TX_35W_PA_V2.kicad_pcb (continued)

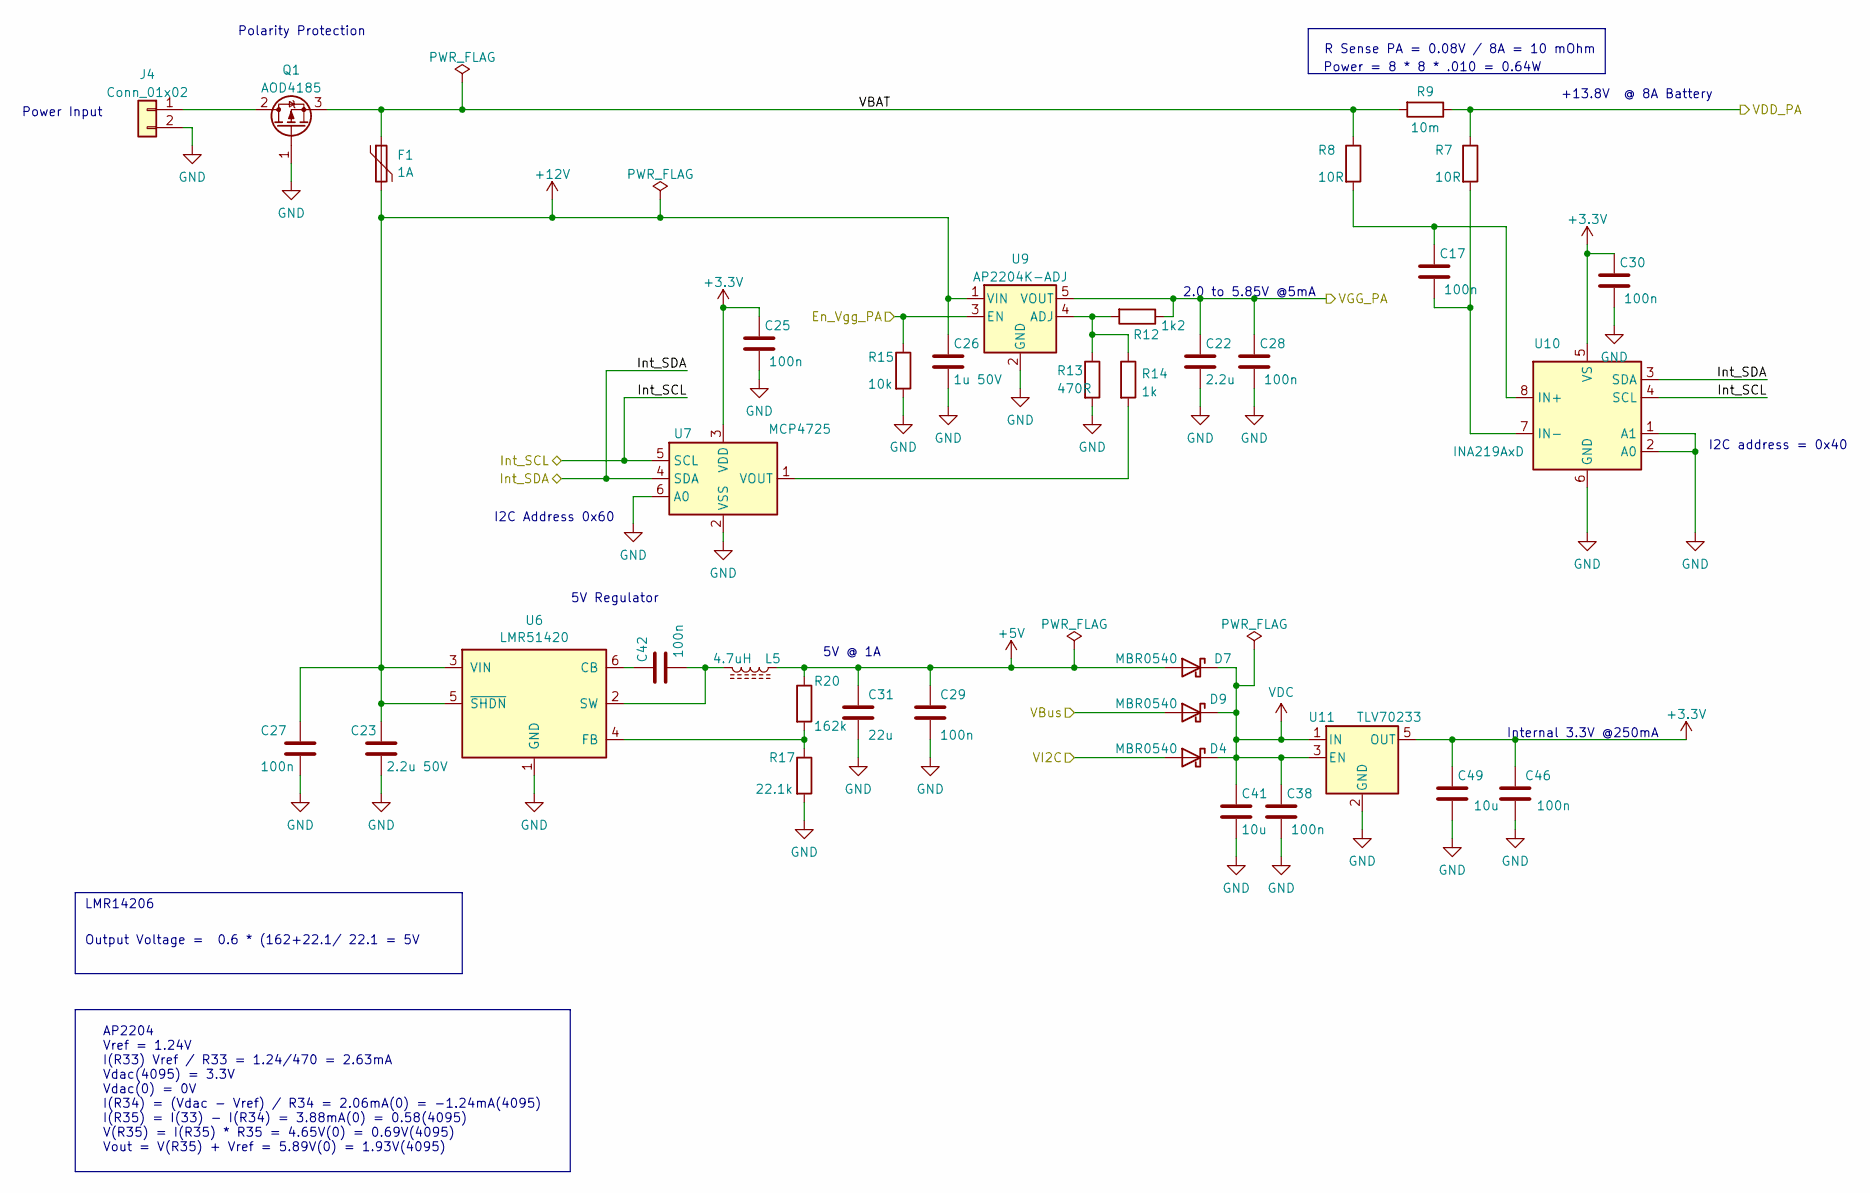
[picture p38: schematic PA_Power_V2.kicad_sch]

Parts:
C17, C25, C27, C28, C29, C30, C38, C42, C46: 100n; C_0603_1608Metric; LCSC Part C88136
C22: 2.2u; C_0603_1608Metric; LCSC Part C57895
C23: 2.2u 50V; C_0805_2012Metric; LCSC Part C377773
C26: 1u 50V; C_0603_1608Metric; LCSC Part C15849
C31: 22u; C_0805_2012Metric; LCSC Part C602037
C41, C49: 10u; C_0603_1608Metric; LCSC Part C96446
D4, D7, D9: MBR0540; D_SOD-123; LCSC Part C3018524
F1: 1A; Fuse_1206_3216Metric; LCSC Part C910830
J4: Conn_01x02; PhoenixContact_MSTBA_2,5_2-G_1x02_P5.00mm_Horizontal; LCSC Part C3697
L5: 4.7uH; L_7.3x7.3_H3.5; LCSC Part C76857
Q1: AOD4185; TO-252-2; LCSC Part C5261064
R7, R8: 10R; R_0603_1608Metric; LCSC Part C22859
R9: 10m; R_2816_7142Metric; LCSC Part C843884
R12: 1k2; R_0603_1608Metric; LCSC Part C22765
R13: 470R; R_0603_1608Metric; LCSC Part C23179
R14: 1k; R_0603_1608Metric; LCSC Part C21190
R15: 10k; R_0603_1608Metric; LCSC Part C25804
R17: 22.1k; R_0603_1608Metric; LCSC Part C25961
R20: 162k; R_0603_1608Metric; LCSC Part C3016073
U6: LMR51420; SOT-23-6; LCSC Part C5383002
U7: MCP4725; SOT-23-6; LCSC Part C144198
U9: AP2204K-ADJ; SOT-23-5; LCSC Part C264072
U10: INA219AxD; SOIC-8_3.9x4.9mm_P1.27mm; LCSC Part C138706
U11: TLV70233; SOT-23-5; LCSC Part C26833

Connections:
+3.3V: C25.1, C30.1, C46.1, C49.1, U7.3 (VDD), U10.5 (VS), U11.5 (OUT); also elsewhere on the board
+5V: C29.1, C31.1, D7.2 (A), L5.1, R20.1; also elsewhere on the board
+12V: C23.1, C26.1, C27.1, F1.2, U6.3 (VIN), U6.5 (~SHDN), U9.1 (VIN); also elsewhere on the board
/PA_Power/En_Vgg_PA: R15.1, U9.3 (EN); also elsewhere on the board
/PA_Power/Int_SCL: U7.5 (SCL), U10.4 (SCL); also elsewhere on the board
/PA_Power/Int_SDA: U7.4 (SDA), U10.3 (SDA); also elsewhere on the board
/PA_Power/VBAT: F1.1, Q1.3 (S), R8.1, R9.2
/PA_Power/VBus: D9.2 (A); also elsewhere on the board
/PA_Power/VDD_PA: R7.1, R9.1; also elsewhere on the board
/PA_Power/VGG_PA: C22.1, C28.1, R12.1, U9.5 (VOUT); also elsewhere on the board
/PA_Power/VI2C: D4.2 (A); also elsewhere on the board
GND: C22.2, C23.2, C25.2, C26.2, C27.2, C28.2, C29.2, C30.2, C31.2, C38.2, C41.2, C46.2, C49.2, J4.2, Q1.1 (G), R13.2, R15.2, R17.2, U6.1 (GND), U7.2 (VSS), U7.6 (A0), U9.2 (GND), U10.1 (A1), U10.2 (A0), U10.6 (GND), U11.2 (GND); also elsewhere on the board
unnamed: J4.1, Q1.2 (D)
unnamed: C42.1, U6.6 (CB)
unnamed: R17.1, R20.2, U6.4 (FB)
unnamed: C42.2, L5.2, U6.2 (SW)
unnamed: R14.2, U7.1 (VOUT)
unnamed: R12.2, R13.1, R14.1, U9.4 (ADJ)
unnamed: C17.1, R8.2, U10.8 (IN+)
unnamed: C17.2, R7.2, U10.7 (IN-)
VDC: C38.1, C41.1, D4.1 (K), D7.1 (K), D9.1 (K), U11.1 (IN), U11.3 (EN); also elsewhere on the board

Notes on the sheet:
5V @ 1A
Power Input
2.0 to 5.85V @5mA
I2C Address 0x60
+13.8V @ 8A Battery
I2C address = 0x40
LMR14206
Internal 3.3V @250mA
AP2204 Vref = 1.24V I(R33) Vref / R33 = 1.24/470 = 2.63mA Vdac(4095) = 3.3V Vdac(0) = 0V I(R34) = (Vdac - Vref) / R34 = 2.06mA(0) = -1.24mA(4095) I(R35) = I(33) - I(R34) = 3.88mA(0) = 0.58(4095) V(R35) = I(R35) * R35 = 4.65V(0) = 0.69V(4095) Vout = V(R35) + Vref = 5.89V(0) = 1.93V(4095)
R Sense PA = 0.08V / 8A = 10 mOhm
Polarity Protection
Power = 8 * 8 * .010 = 0.64W
Output Voltage = 0.6 * (162+22.1/ 22.1 = 5V
5V Regulator

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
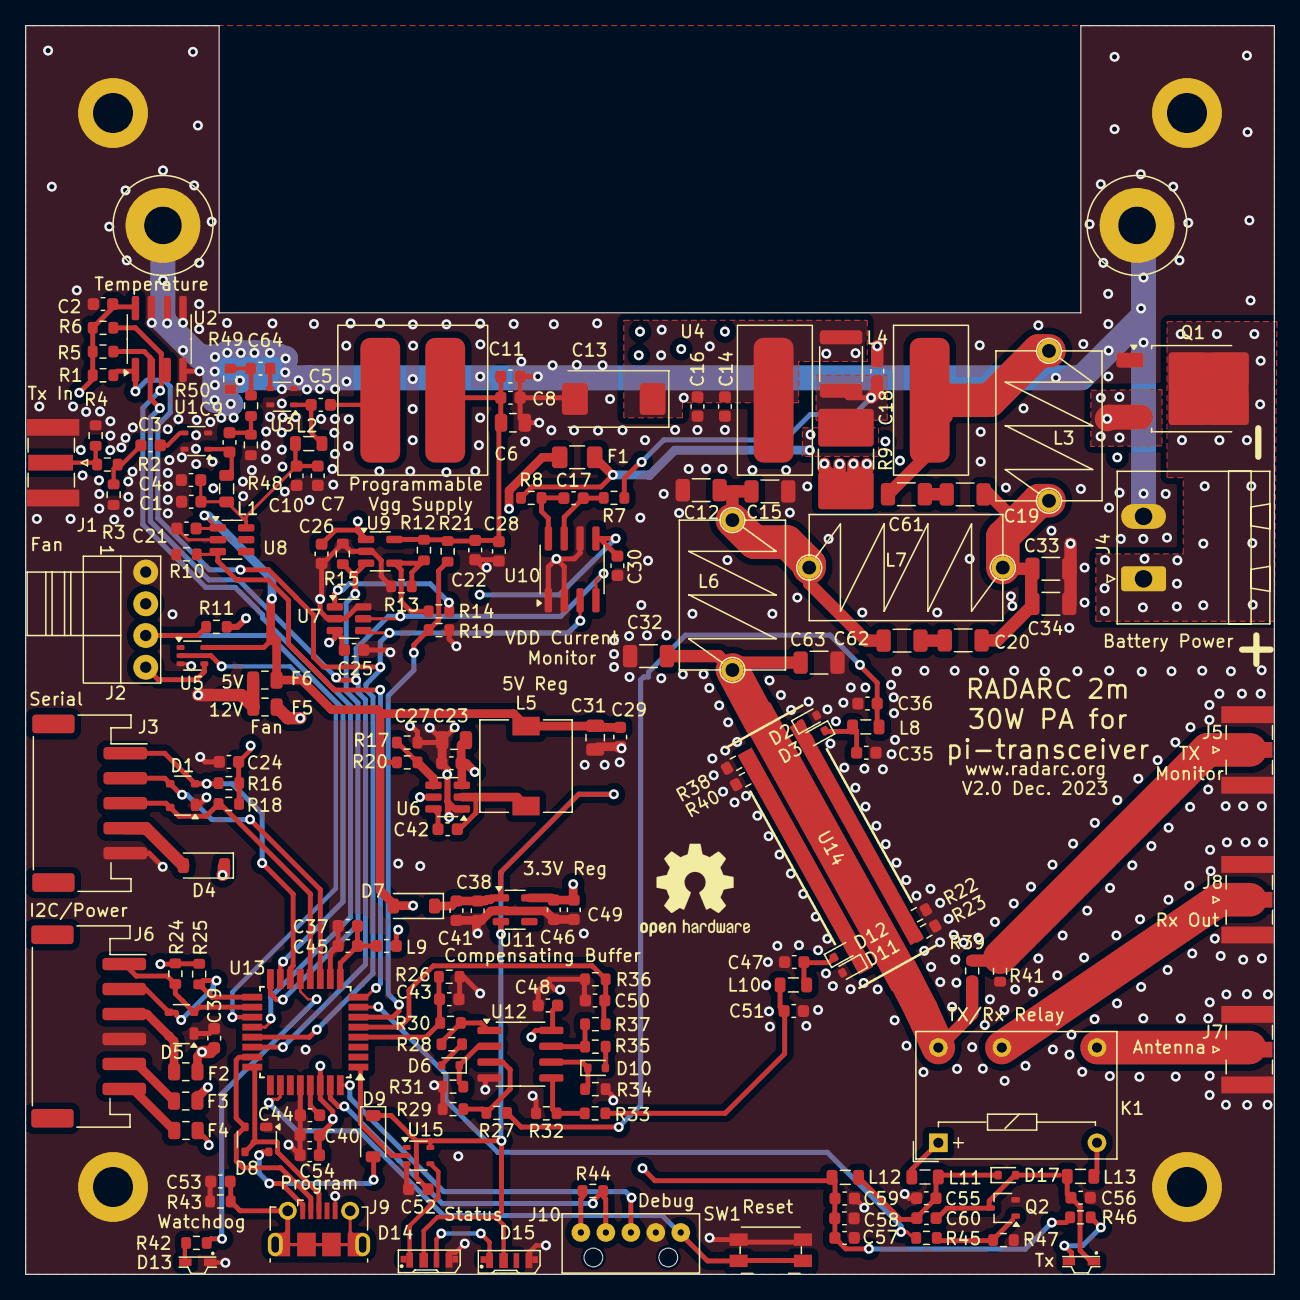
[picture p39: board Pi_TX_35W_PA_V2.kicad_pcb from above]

Board: 4 copper layers, 100.0 x 100.0 mm, 185 parts (1 on the bottom side), 95 nets.

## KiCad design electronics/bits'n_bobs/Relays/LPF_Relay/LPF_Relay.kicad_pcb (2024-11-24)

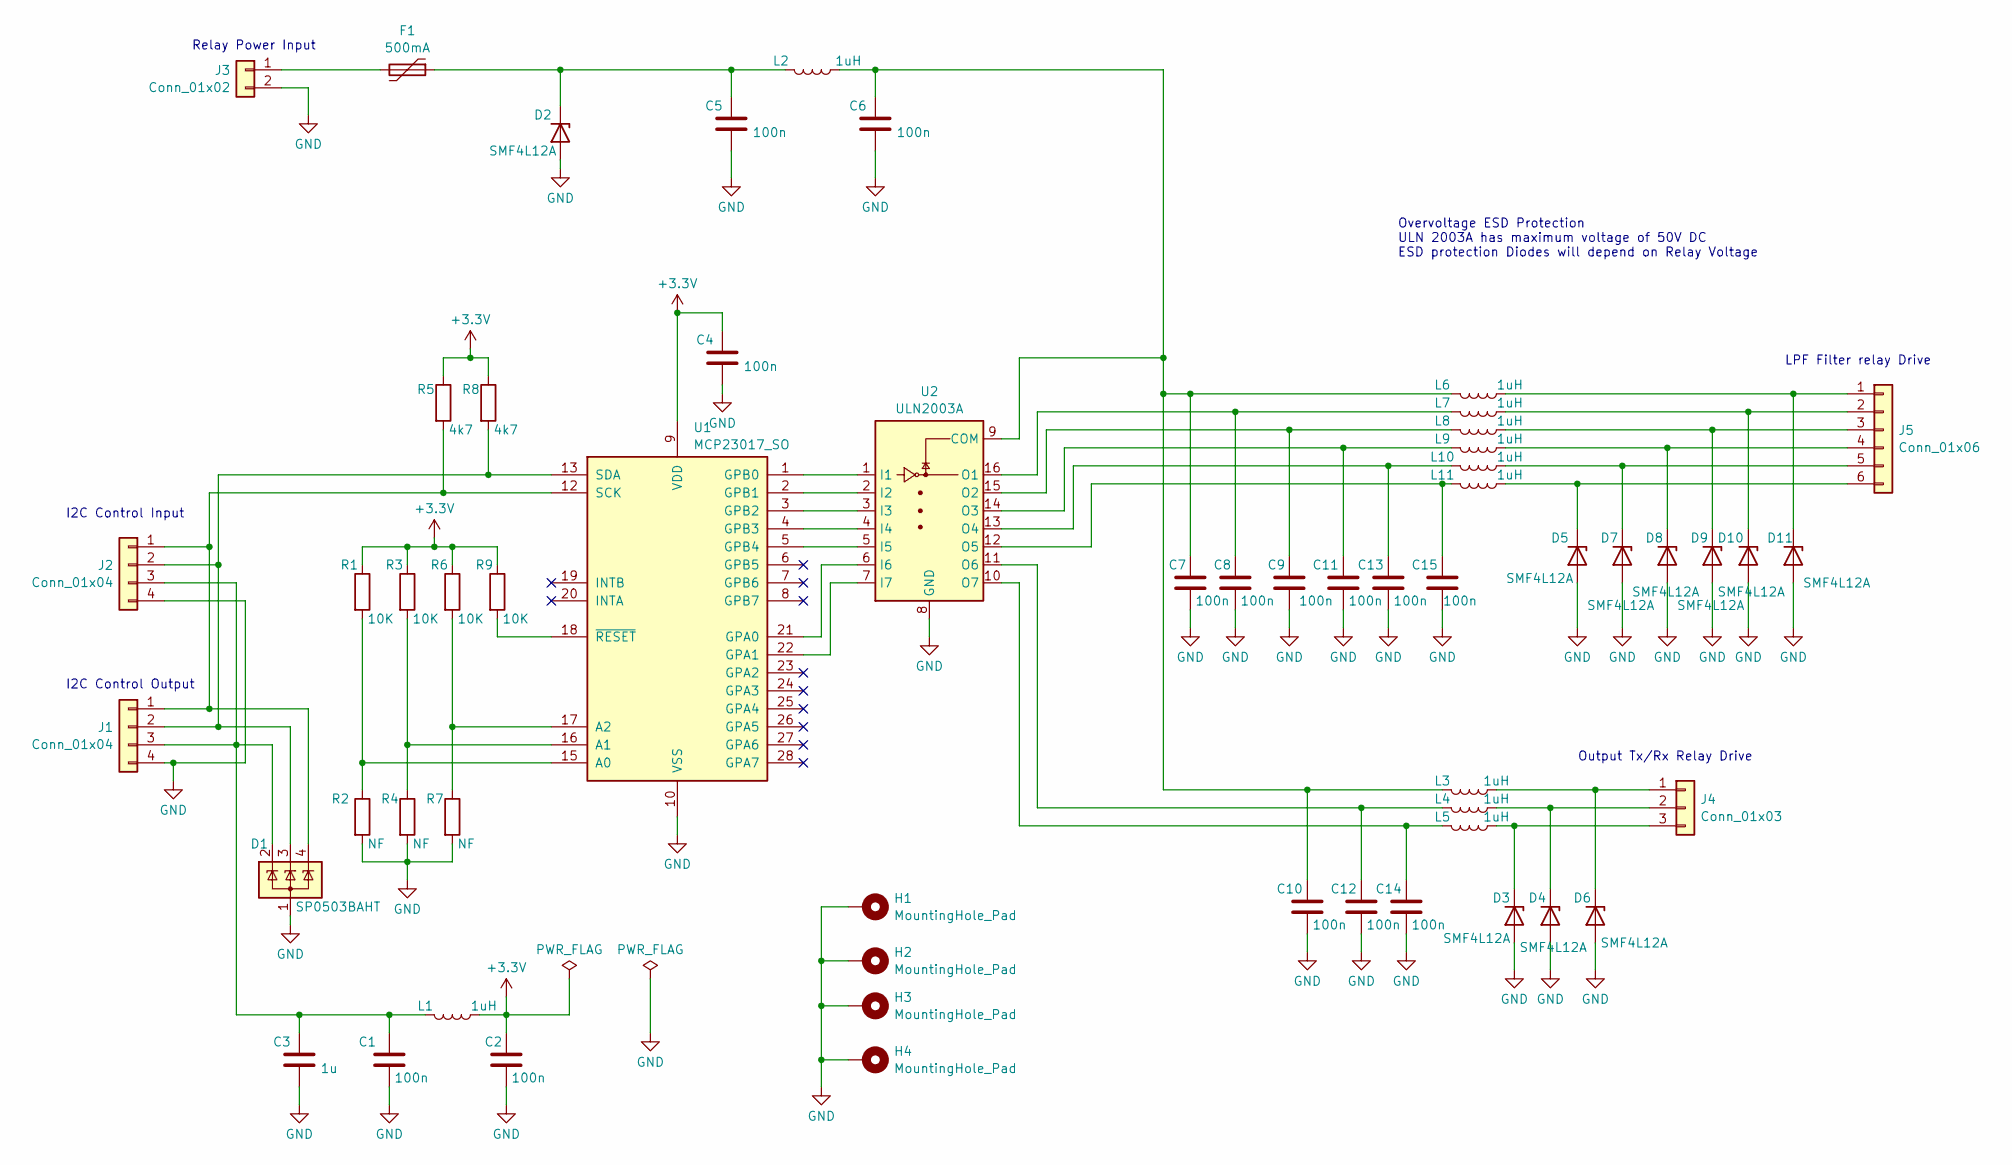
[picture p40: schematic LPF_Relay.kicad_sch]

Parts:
C1, C2, C4, C5, C6, C7, C8, C9, C10, C11, C12, C13, C14, C15: 100n; C_0603_1608Metric
C3: 1u; C_0603_1608Metric
D1: SP0503BAHT; SOT-143
D2, D3, D4, D5, D6, D7, D8, D9, D10, D11: SMF4L12A; D_SOD-123F
F1: 500mA; Fuse_Bourns_MF-SM_9.5x6.71mm
H1, H2, H3, H4: MountingHole_Pad; MountingHole_3.2mm_M3_DIN965_Pad
J1, J2: Conn_01x04; JST_PH_S4B-PH-SM4-TB_1x04-1MP_P2.00mm_Horizontal
J3: Conn_01x02; JST_XH_S2B-XH-A-1_1x02_P2.50mm_Horizontal
J4: Conn_01x03; JST_XH_S3B-XH-A-1_1x03_P2.50mm_Horizontal
J5: Conn_01x06; JST_XH_S6B-XH-A-1_1x06_P2.50mm_Horizontal
L1, L2, L3, L4, L5, L6, L7, L8, L9, L10, L11: 1uH; L_0603_1608Metric
R1, R3, R6, R9: 10K; R_0603_1608Metric
R2, R4, R7: NF; R_0603_1608Metric
R5, R8: 4k7; R_0603_1608Metric
U1: MCP23017_SO; SSOP-28_5.3x10.2mm_P0.65mm
U2: ULN2003A; SO-16_3.9x9.9mm_P1.27mm

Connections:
+3.3V: C2.1, C4.1, L1.1, R1.1, R3.1, R5.1, R6.1, R8.1, R9.1, U1.9 (VDD)
GND: C1.2, C2.2, C3.2, C4.2, C5.2, C6.2, C7.2, C8.2, C9.2, C10.2, C11.2, C12.2, C13.2, C14.2, C15.2, D1.1 (A), D2.2 (A), D3.2 (A), D4.2 (A), D5.2 (A), D6.2 (A), D7.2 (A), D8.2 (A), D9.2 (A), D10.2 (A), D11.2 (A), H1.1, H2.1, H3.1, H4.1, J1.4, J2.4, J3.2, R2.2, R4.2, R7.2, U1.10 (VSS), U2.8 (GND)
unnamed: C5.1, D2.1 (K), F1.1, L2.2
unnamed: D3.1 (K), J4.3, L5.1
unnamed: D4.1 (K), J4.2, L4.1
unnamed: D5.1 (K), J5.6, L11.1
unnamed: D6.1 (K), J4.1, L3.1
unnamed: D7.1 (K), J5.5, L10.1
unnamed: D8.1 (K), J5.4, L9.1
unnamed: D9.1 (K), J5.3, L8.1
unnamed: D10.1 (K), J5.2, L7.1
unnamed: D11.1 (K), J5.1, L6.1
unnamed: D1.4 (K), J1.1, J2.1, R5.2, U1.12 (SCK)
unnamed: D1.3 (K), J1.2, J2.2, R8.2, U1.13 (SDA)
unnamed: C1.1, C3.1, D1.2 (K), J1.3, J2.3, L1.2
unnamed: F1.2, J3.1
unnamed: R1.2, R2.1, U1.15 (A0)
unnamed: R3.2, R4.1, U1.16 (A1)
unnamed: R6.2, R7.1, U1.17 (A2)
unnamed: U1.21 (GPA0), U2.6 (I6)
unnamed: U1.22 (GPA1), U2.7 (I7)
unnamed: U1.1 (GPB0), U2.1 (I1)
unnamed: U1.2 (GPB1), U2.2 (I2)
unnamed: U1.3 (GPB2), U2.3 (I3)
unnamed: U1.4 (GPB3), U2.4 (I4)
unnamed: U1.5 (GPB4), U2.5 (I5)
unnamed: R9.2, U1.18 (~RESET)
unnamed: C6.1, C7.1, C10.1, L2.1, L3.2, L6.2, U2.9 (COM)
unnamed: C8.1, L7.2, U2.16 (O1)
unnamed: C9.1, L8.2, U2.15 (O2)
unnamed: C11.1, L9.2, U2.14 (O3)
unnamed: C13.1, L10.2, U2.13 (O4)
unnamed: C15.1, L11.2, U2.12 (O5)
unnamed: C12.1, L4.2, U2.11 (O6)
unnamed: C14.1, L5.2, U2.10 (O7)

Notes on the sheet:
I2C Control Output
LPF Filter relay Drive
Output Tx/Rx Relay Drive
I2C Control Input
Relay Power Input
Overvoltage ESD Protection ULN 2003A has maximum voltage of 50V DC ESD protection Diodes will depend on Relay Voltage

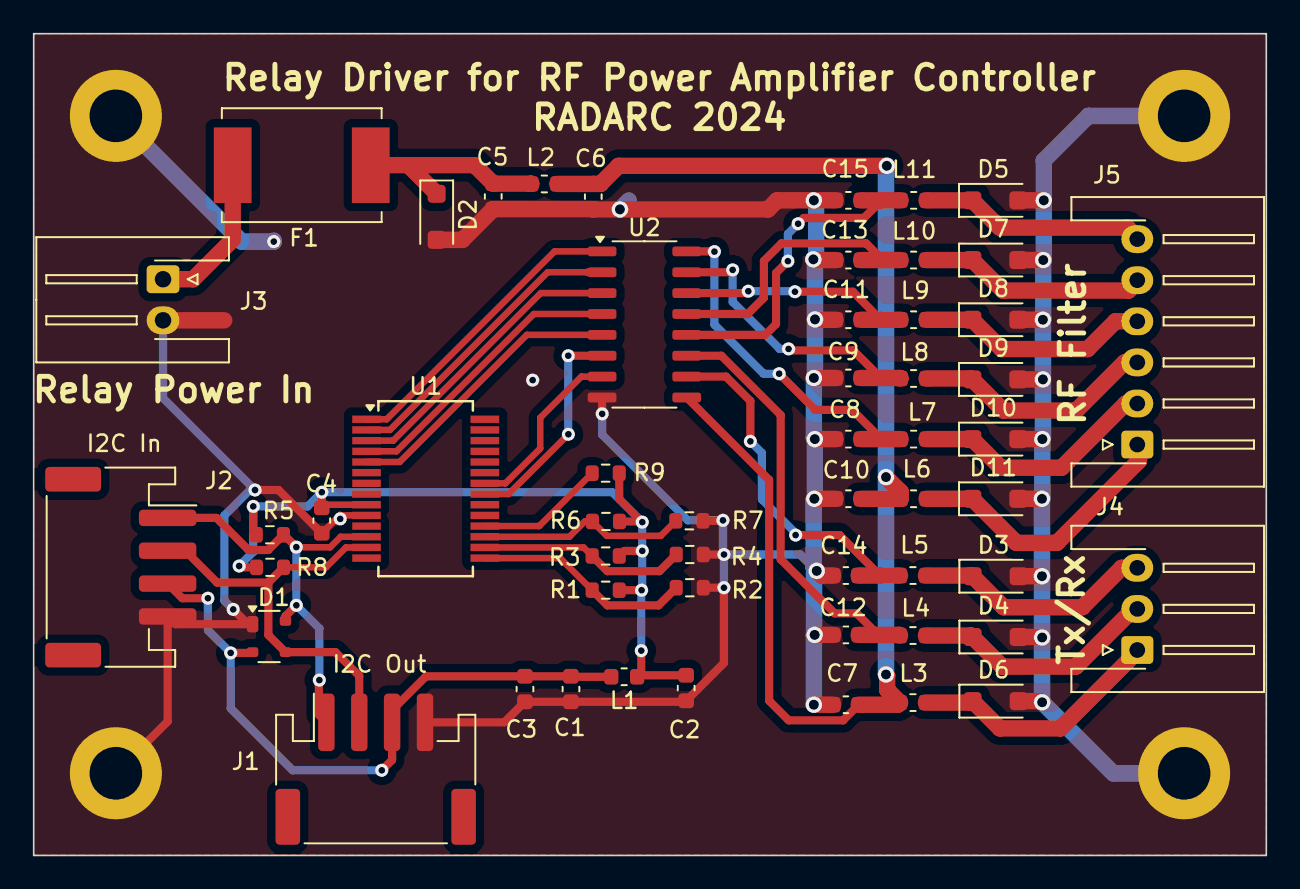
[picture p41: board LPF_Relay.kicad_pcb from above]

Board: 2 copper layers, 75.0 x 50.0 mm, 58 parts (0 on the bottom side), 35 nets.

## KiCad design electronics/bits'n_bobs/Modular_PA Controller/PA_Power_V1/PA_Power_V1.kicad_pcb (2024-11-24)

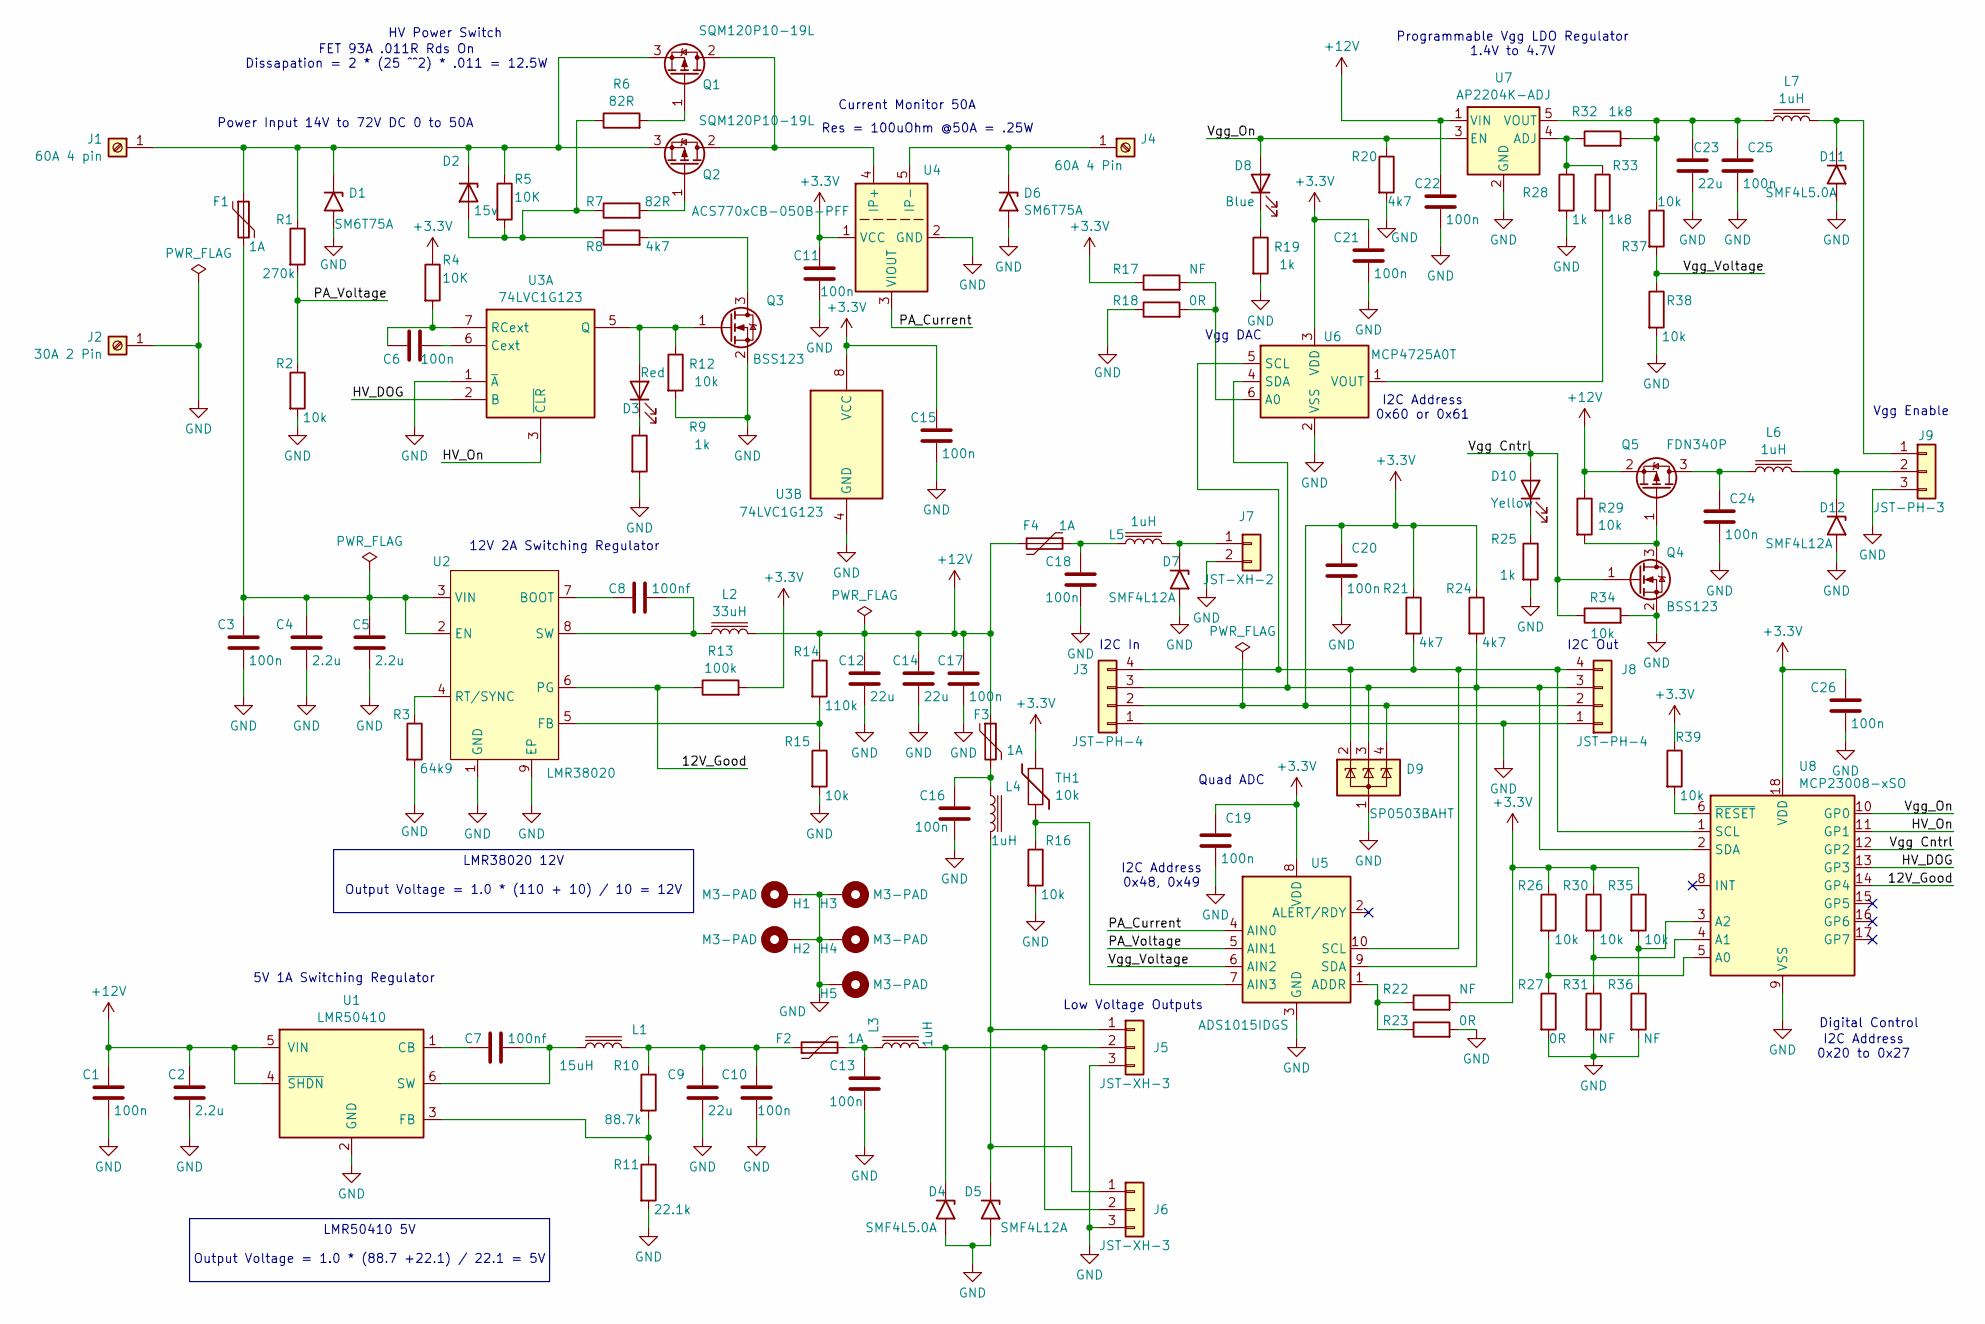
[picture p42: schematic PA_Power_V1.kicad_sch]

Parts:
C1, C10, C11, C13, C15, C16, C17, C18, C19, C20, C21, C22, C24, C25, C26: 100n; C_0603_1608Metric
C2: 2.2u; C_0603_1608Metric
C3, C6: 100n; C_0805_2012Metric
C4, C5: 2.2u; C_1210_3225Metric
C7, C8: 100nf; C_0603_1608Metric
C9, C12, C14: 22u; C_1210_3225Metric
C23: 22u; C_0805_2012Metric
D1, D6: SM6T75A; D_SMB
D2: 15v; Nexperia_CFP3_SOD-123W
D3: Red; LED_0603_1608Metric
D4, D11: SMF4L5.0A; D_SOD-123F
D5, D7, D12: SMF4L12A; D_SOD-123F
D8: Blue; LED_0603_1608Metric
D9: SP0503BAHT; SOT-143
D10: Yellow; LED_0603_1608Metric
F1: 1A; Fuse_Schurter_UMZ250
F2, F3, F4: 1A; Fuse_1812_4532Metric
H1, H2, H3, H4, H5: M3-PAD; MountingHole_3.2mm_M3_DIN965_Pad
J1: 60A 4 pin; Fat_Power 4
J2: 30A 2 Pin; Fat_Power 2
J3, J8: JST-PH-4; JST_PH_B4B-PH-SM4-TB_1x04-1MP_P2.00mm_Vertical
J4: 60A 4 Pin; Fat_Power 4
J5, J6: JST-XH-3; JST_XH_S3B-XH-A_1x03_P2.50mm_Horizontal
J7: JST-XH-2; JST_XH_S2B-XH-A_1x02_P2.50mm_Horizontal
J9: JST-PH-3; JST_PH_S3B-PH-SM4-TB_1x03-1MP_P2.00mm_Horizontal
L1: 15uH; L_Wuerth_MAPI-4030
L2: 33uH; L_Coilcraft_MSS1210-XXX
L3, L4, L5, L6, L7: 1uH; L_0805_2012Metric
Q1, Q2: SQM120P10-19L; TO263_Heatsink_301
Q3, Q4: BSS123; SOT-23
Q5: FDN340P; SOT-23
R1: 270k; R_0603_1608Metric
R2, R12, R15, R16, R26, R29, R30, R34, R35, R37, R38, R39: 10k; R_0603_1608Metric
R3: 64k9; R_0603_1608Metric
R4, R5: 10K; R_0603_1608Metric
R6, R7: 82R; R_0603_1608Metric
R8, R20, R21, R24: 4k7; R_0603_1608Metric
R9, R19, R25, R28: 1k; R_0603_1608Metric
R10: 88.7k; R_0603_1608Metric
R11: 22.1k; R_0603_1608Metric
R13: 100k; R_0603_1608Metric
R14: 110k; R_0603_1608Metric
R17, R22, R31, R36: NF; R_0603_1608Metric
R18, R23, R27: 0R; R_0603_1608Metric
R32, R33: 1k8; R_0603_1608Metric
TH1: 10k; R_0603_1608Metric
U1: LMR50410; SOT-23-6
U2: LMR38020; lmr38012
U3: 74LVC1G123; TSSOP-8_3x3mm_P0.65mm
U4: ACS770xCB-050B-PFF; Allegro_CB_PFF
U5: ADS1015IDGS; TSSOP-10_3x3mm_P0.5mm
U6: MCP4725A0T; SOT-23-6
U7: AP2204K-ADJ; SOT-23-5
U8: MCP23008-xSO; SOIC-18W_7.5x11.6mm_P1.27mm

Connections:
+3.3V: C11.1, C15.1, C19.1, C20.1, C21.1, C26.1, D9.4 (K), J3.2, J8.2, R4.1, R13.2, R17.1, R21.1, R22.2, R24.1, R26.1, R30.1, R35.1, R39.1, TH1.1, U3.8 (VCC), U4.1 (VCC), U5.8 (VDD), U6.3 (VDD), U8.18 (VDD)
+12V: C1.1, C2.1, C12.1, C14.1, C17.1, C22.1, F3.1, F4.2, L2.2, Q5.2 (S), R14.1, R29.1, U1.4 (~SHDN), U1.5 (VIN), U7.1 (VIN)
/12V_Good: R13.1, U2.6 (PG), U8.14 (GP4)
/HV_DOG: U3.2 (B), U8.13 (GP3)
/HV_On: U3.3 (~CLR), U8.11 (GP1)
/PA_Current: U4.3 (VIOUT), U5.4 (AIN0)
/PA_Voltage: R1.2, R2.1, U5.5 (AIN1)
/Vgg Cntrl: D10.2 (A), Q4.1 (G), R34.1, U8.12 (GP2)
/Vgg_On: D8.2 (A), R20.1, U7.3 (EN), U8.10 (GP0)
/Vgg_Voltage: R37.2, R38.1, U5.6 (AIN2)
GND: C1.2, C2.2, C3.2, C4.2, C5.2, C9.2, C10.2, C11.2, C12.2, C13.2, C14.2, C15.2, C16.2, C17.2, C18.2, C19.2, C20.2, C21.2, C22.2, C23.2, C24.2, C25.2, C26.2, D1.2 (A2), D4.2 (A2), D5.2 (A2), D6.2 (A2), D7.2 (A2), D9.1 (A), D11.2 (A2), D12.2 (A2), H1.1, H2.1, H3.1, H4.1, H5.1, J2.1, J3.1, J5.3, J6.3, J7.2, J8.1, J9.3, Q3.2 (S), Q4.2 (S), R2.2, R3.2, R9.2, R11.2, R12.2, R15.2, R16.2, R18.1, R19.2, R20.2, R23.2, R25.2, R27.2, R28.2, R31.2, R34.2, R36.2, R38.2, U1.2 (GND), U2.1 (GND), U2.9 (EP), U3.1 (~A), U3.4 (GND), U4.2 (GND), U5.3 (GND), U6.2 (VSS), U7.2 (GND), U8.9 (VSS)
unnamed: C9.1, C10.1, F2.1, L1.2, R10.1
unnamed: C13.1, F2.2, L3.1
unnamed: C16.1, F3.2, L4.1
unnamed: C18.1, F4.1, L5.1
unnamed: D1.1 (A1), D2.1 (K), F1.1, J1.1, Q1.3 (S), Q2.3 (S), R1.1, R5.1
unnamed: D2.2 (A), R5.2, R6.1, R7.1, R8.1
unnamed: D3.2 (A), Q3.1 (G), R12.1, U3.5 (Q)
unnamed: D3.1 (K), R9.1
unnamed: D4.1 (A1), J5.2, J6.2, L3.2
unnamed: D5.1 (A1), J5.1, J6.1, L4.2
unnamed: D6.1 (A1), J4.1, U4.5 (IP-)
unnamed: D7.1 (A1), J7.1, L5.2
unnamed: D8.1 (K), R19.1
unnamed: D10.1 (K), R25.1
unnamed: D11.1 (A1), J9.1, L7.2
unnamed: D12.1 (A1), J9.2, L6.2
unnamed: D9.3 (K), J3.3, J8.3, R24.2, U5.9 (SDA), U6.4 (SDA), U8.2 (SDA)
unnamed: D9.2 (K), J3.4, J8.4, R21.2, U5.10 (SCL), U6.5 (SCL), U8.1 (SCL)
unnamed: Q1.2 (D), Q2.2 (D), U4.4 (IP+)
unnamed: Q1.1 (G), R6.2
unnamed: Q2.1 (G), R7.2
unnamed: Q3.3 (D), R8.2
unnamed: Q4.3 (D), Q5.1 (G), R29.2
unnamed: C24.1, L6.1, Q5.3 (D)
unnamed: C7.1, U1.1 (CB)
unnamed: R10.2, R11.1, U1.3 (FB)
unnamed: C7.2, L1.1, U1.6 (SW)
unnamed: C8.1, U2.7 (BOOT)
unnamed: C3.1, C4.1, C5.1, F1.2, U2.2 (EN), U2.3 (VIN)
unnamed: R14.2, R15.1, U2.5 (FB)
unnamed: R3.1, U2.4 (RT/SYNC)
unnamed: C8.2, L2.1, U2.8 (SW)
unnamed: C6.2, U3.6 (Cext)
unnamed: C6.1, R4.2, U3.7 (RCext)
unnamed: R22.1, R23.1, U5.1 (ADDR)
unnamed: R16.1, TH1.2, U5.7 (AIN3)
unnamed: R17.2, R18.2, U6.6 (A0)
unnamed: R33.2, U6.1 (VOUT)
unnamed: R28.1, R32.1, R33.1, U7.4 (ADJ)
unnamed: C23.1, C25.1, L7.1, R32.2, R37.1, U7.5 (VOUT)
unnamed: R26.2, R27.1, U8.5 (A0)
unnamed: R30.2, R31.1, U8.4 (A1)
unnamed: R35.2, R36.1, U8.3 (A2)
unnamed: R39.2, U8.6 (~RESET)

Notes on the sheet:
5V 1A Switching Regulator
Current Monitor 50A
Quad ADC
Digital Control
I2C Out
Res = 100uOhm @50A = .25W
LMR38020 12V Output Voltage = 1.0 * (110 + 10) / 10 = 12V
Low Voltage Outputs
I2C In
HV Power Switch
LMR50410 5V Output Voltage = 1.0 * (88.7 +22.1) / 22.1 = 5V
I2C Address 0x20 to 0x27
Vgg Enable
FET 93A .011R Rds On Dissapation = 2 * (25 ^^2) * .011 = 12.5W
12V 2A Switching Regulator
Vgg DAC
I2C Address 0x60 or 0x61
Power Input 14V to 72V DC 0 to 50A
I2C Address 0x48, 0x49
Programmable Vgg LDO Regulator 1.4V to 4.7V

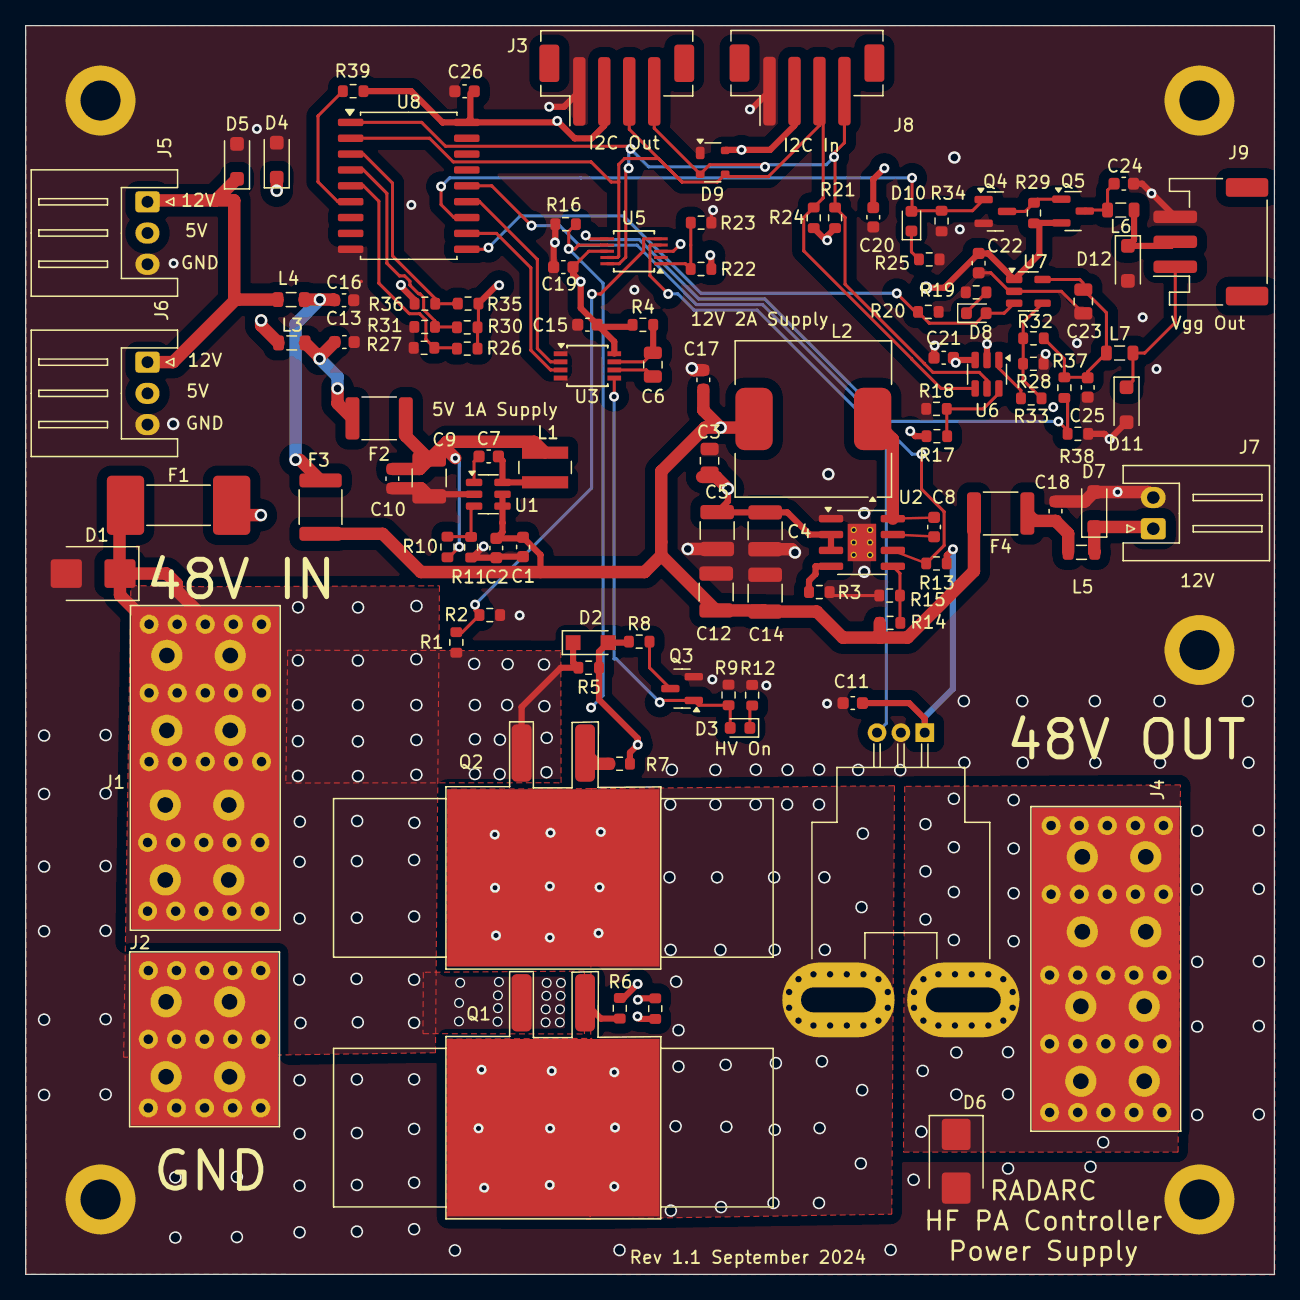
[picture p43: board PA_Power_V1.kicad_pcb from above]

Board: 4 copper layers, 100.0 x 100.0 mm, 116 parts (0 on the bottom side), 55 nets.

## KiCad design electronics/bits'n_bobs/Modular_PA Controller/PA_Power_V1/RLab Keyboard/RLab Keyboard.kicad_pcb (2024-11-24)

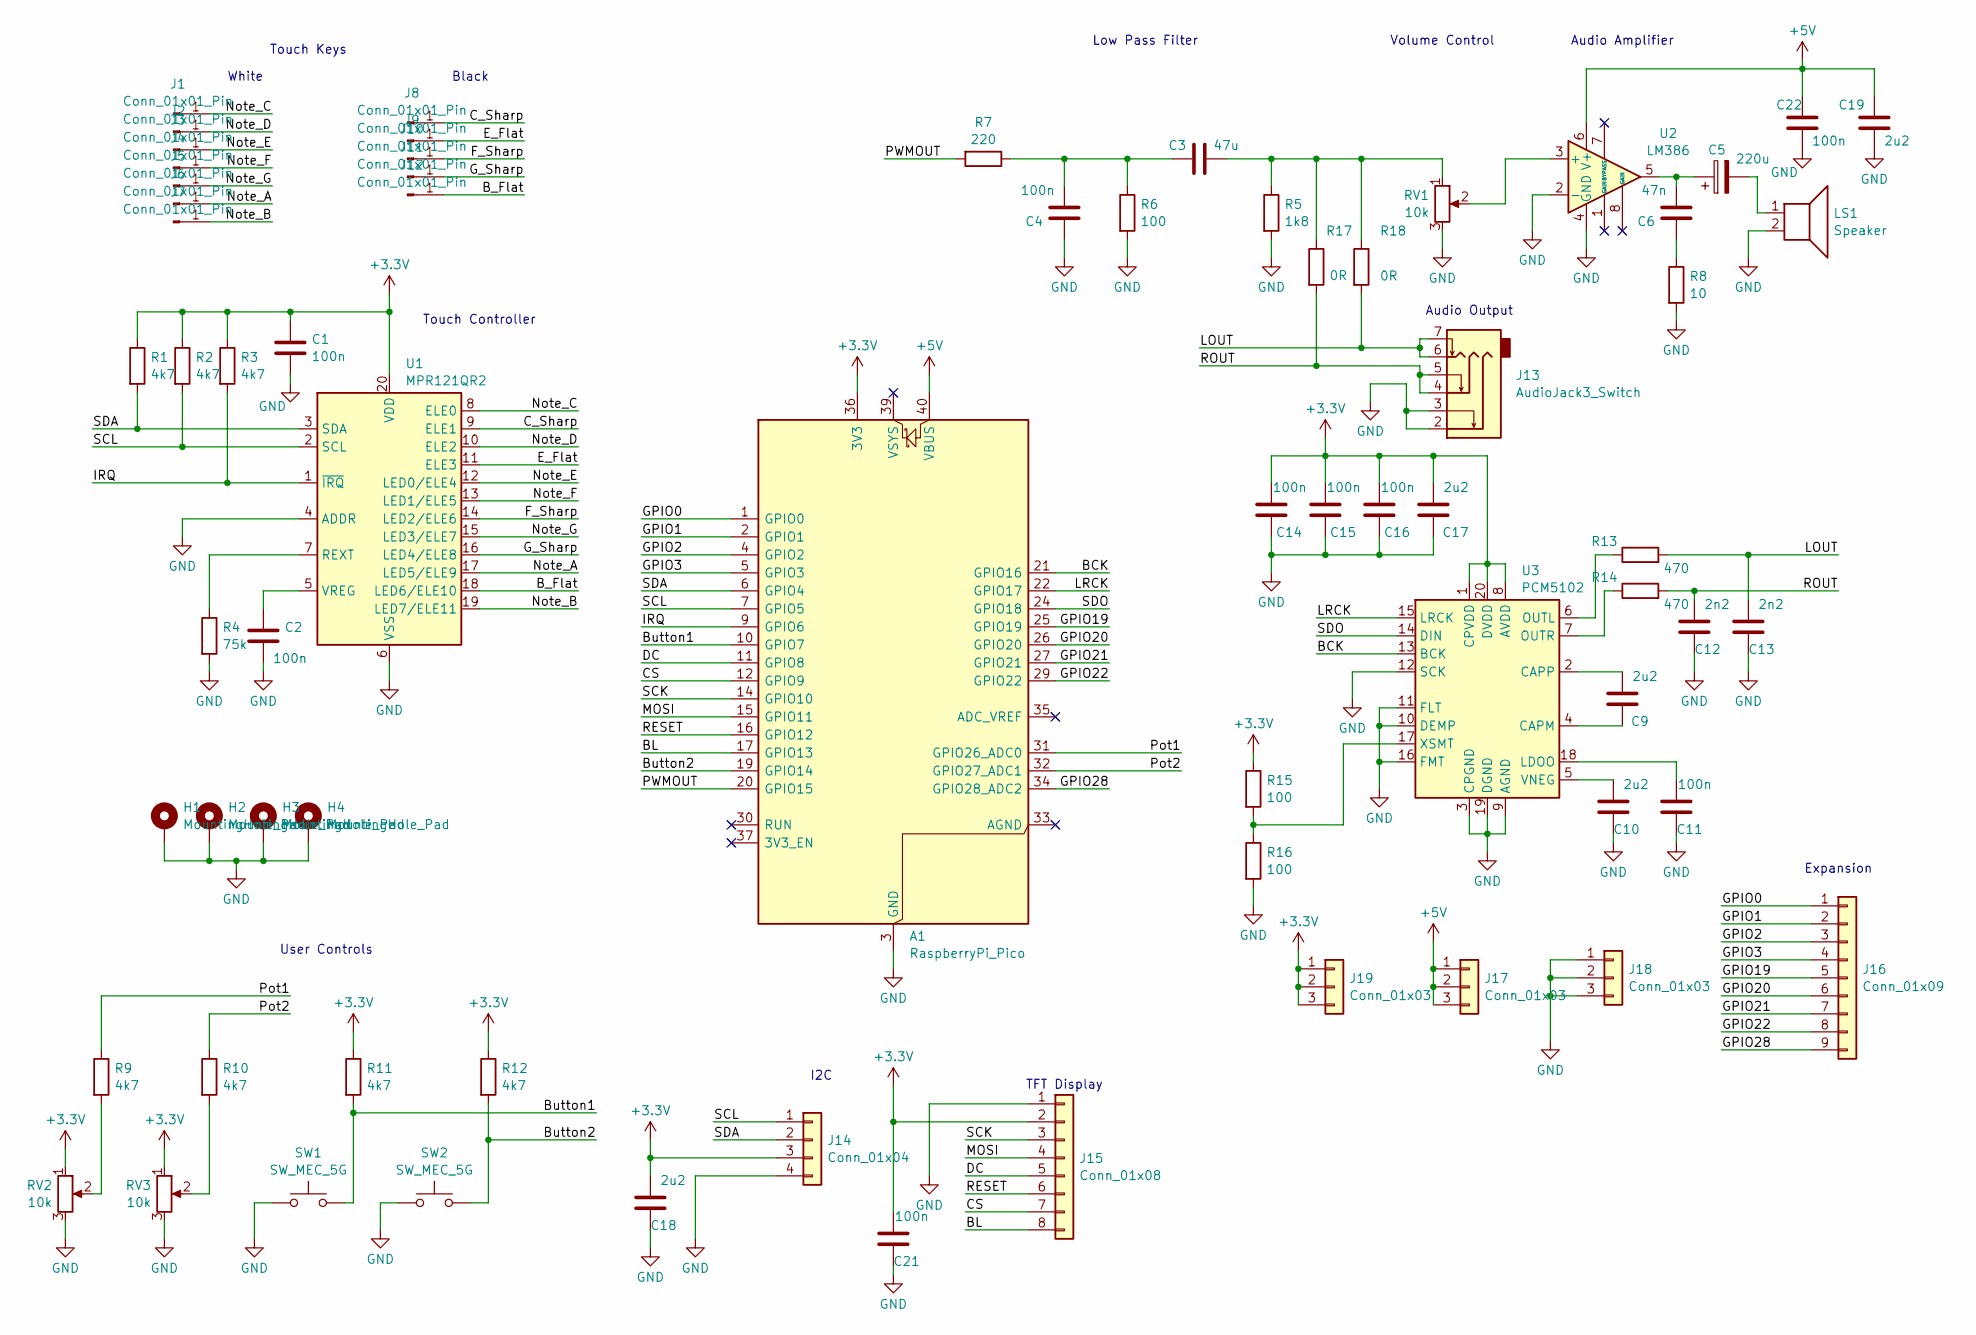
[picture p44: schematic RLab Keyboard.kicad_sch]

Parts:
A1: RaspberryPi_Pico; RPi_Pico_SMD_TH
C1, C2, C4, C11, C14, C15, C16, C21, C22: 100n; C_0603_1608Metric
C3: 47u; C_0805_2012Metric
C5: 220u; C_1206_3216Metric
C6: 47n; C_0603_1608Metric
C9, C10, C17, C18, C19: 2u2; C_0603_1608Metric
C12, C13: 2n2; C_0603_1608Metric
H1, H2, H3, H4: MountingHole_Pad; MountingHole_2.2mm_M2_DIN965_Pad
J1, J2, J3, J4, J5, J6, J7: Conn_01x01_Pin; White_Key
J8, J9, J10, J11, J12: Conn_01x01_Pin; Black_key
J13: AudioJack3_Switch; Jack_3.5mm_PJ342_Horizontal
J14: Conn_01x04; PinSocket_1x04_P2.54mm_Vertical
J15: Conn_01x08; PinSocket_1x08_P2.54mm_Vertical
J16: Conn_01x09; PinSocket_1x09_P2.54mm_Vertical
J17, J18, J19: Conn_01x03; PinSocket_1x03_P2.54mm_Vertical
LS1: Speaker; 30mm_Speaker
R1, R2, R3, R9, R10, R11, R12: 4k7; R_0603_1608Metric
R4: 75k; R_0603_1608Metric
R5: 1k8; R_0603_1608Metric
R6, R15, R16: 100; R_0603_1608Metric
R7: 220; R_0603_1608Metric
R8: 10; R_0603_1608Metric
R13, R14: 470; R_0603_1608Metric
R17, R18: 0R; R_0603_1608Metric
RV1: 10k; Potentiometer_Bourns_3214G_Horizontal
RV2, RV3: 10k; Potentiometer_Alps_RK09K_Single_Vertical
SW1, SW2: SW_MEC_5G; SW_PUSH_6mm_H5mm
U1: MPR121QR2; UQFN-20_3x3mm_P0.4mm
U2: LM386; SOIC-8_3.9x4.9mm_P1.27mm
U3: PCM5102; TSSOP-20_4.4x6.5mm_P0.65mm

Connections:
+3.3V: A1.36 (3V3), C1.1, C14.2, C15.2, C16.2, C17.2, C18.2, C21.2, J14.3, J15.2, J19.1, J19.2, J19.3, R1.1, R2.1, R3.1, R11.1, R12.1, R15.1, RV2.1, RV3.1, U1.20 (VDD), U3.1 (CPVDD), U3.8 (AVDD), U3.20 (DVDD)
+5V: A1.40 (VBUS), C19.2, C22.1, J17.1, J17.2, J17.3, U2.6 (V+)
/BCK: A1.21 (GPIO16), U3.13 (BCK)
/BL: A1.17 (GPIO13), J15.8
/B_Flat: J12.1, U1.18 (LED6/ELE10)
/Button1: A1.10 (GPIO7), R11.2, SW1.2
/Button2: A1.19 (GPIO14), R12.2, SW2.2
/CS: A1.12 (GPIO9), J15.7
/C_Sharp: J8.1, U1.9 (ELE1)
/DC: A1.11 (GPIO8), J15.5
/E_Flat: J9.1, U1.11 (ELE3)
/F_Sharp: J10.1, U1.14 (LED2/ELE6)
/GPIO0: A1.1 (GPIO0), J16.1
/GPIO1: A1.2 (GPIO1), J16.2
/GPIO2: A1.4 (GPIO2), J16.3
/GPIO3: A1.5 (GPIO3), J16.4
/GPIO19: A1.25 (GPIO19), J16.5
/GPIO20: A1.26 (GPIO20), J16.6
/GPIO21: A1.27 (GPIO21), J16.7
/GPIO22: A1.29 (GPIO22), J16.8
/GPIO28: A1.34 (GPIO28_ADC2), J16.9
/G_Sharp: J11.1, U1.16 (LED4/ELE8)
/IRQ: A1.9 (GPIO6), R3.2, U1.1 (~IRQ)
/LOUT: C13.2, J13.6, J13.7, R13.2, R18.2
/LRCK: A1.22 (GPIO17), U3.15 (LRCK)
/MOSI: A1.15 (GPIO11), J15.4
/Note_A: J6.1, U1.17 (LED5/ELE9)
/Note_B: J7.1, U1.19 (LED7/ELE11)
/Note_C: J1.1, U1.8 (ELE0)
/Note_D: J2.1, U1.10 (ELE2)
/Note_E: J3.1, U1.12 (LED0/ELE4)
/Note_F: J4.1, U1.13 (LED1/ELE5)
/Note_G: J5.1, U1.15 (LED3/ELE7)
/PWMOUT: A1.20 (GPIO15), R7.2
/Pot1: A1.31 (GPIO26_ADC0), R9.1
/Pot2: A1.32 (GPIO27_ADC1), R10.1
/RESET: A1.16 (GPIO12), J15.6
/ROUT: C12.2, J13.4, J13.5, R14.2, R17.2
/SCK: A1.14 (GPIO10), J15.3
/SCL: A1.7 (GPIO5), J14.1, R2.2, U1.2 (SCL)
/SDA: A1.6 (GPIO4), J14.2, R1.2, U1.3 (SDA)
/SDO: A1.24 (GPIO18), U3.14 (DIN)
GND: A1.3 (GND), A1.8 (GND), A1.13 (GND), A1.18 (GND), A1.23 (GND), A1.28 (GND), A1.38 (GND), C1.2, C2.2, C4.1, C10.1, C11.1, C12.1, C13.1, C14.1, C15.1, C16.1, C17.1, C18.1, C19.1, C21.1, C22.2, H1.1, H2.1, H3.1, H4.1, J13.2, J13.3, J14.4, J15.1, J18.1, J18.2, J18.3, LS1.2, R4.2, R5.2, R6.2, R8.2, R16.2, RV1.3, RV2.3, RV3.3, SW1.1, SW2.1, U1.4 (ADDR), U1.6 (VSS), U2.2 (-), U2.4 (GND), U3.3 (CPGND), U3.9 (AGND), U3.10 (DEMP), U3.11 (FLT), U3.12 (SCK), U3.16 (FMT), U3.19 (DGND)
unnamed: C3.1, R5.1, R17.1, R18.1, RV1.1
unnamed: C3.2, C4.2, R6.1, R7.1
unnamed: C5.1, C6.2, U2.5
unnamed: C5.2, LS1.1
unnamed: C6.1, R8.1
unnamed: R9.2, RV2.2
unnamed: R10.2, RV3.2
unnamed: R4.1, U1.7 (REXT)
unnamed: C2.1, U1.5 (VREG)
unnamed: RV1.2, U2.3 (+)
unnamed: C9.1, U3.4 (CAPM)
unnamed: C9.2, U3.2 (CAPP)
unnamed: C11.2, U3.18 (LDOO)
unnamed: R13.1, U3.6 (OUTL)
unnamed: R14.1, U3.7 (OUTR)
unnamed: C10.2, U3.5 (VNEG)
unnamed: R15.2, R16.1, U3.17 (XSMT)

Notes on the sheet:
Low Pass Filter
Black
Touch Keys
Audio Amplifier
Audio Output
TFT Display
Volume Control
I2C
Expansion
User Controls
Touch Controller
White


Board: 2 copper layers, 100.0 x 100.0 mm, 70 parts (0 on the bottom side), 60 nets.

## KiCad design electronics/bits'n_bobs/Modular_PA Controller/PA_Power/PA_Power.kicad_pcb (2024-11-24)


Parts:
C1, C2, C13, C14, C15, C16, C19, C20, C21, C22, C23, C24, C25, C26, C28, C29, C30: 100n; C_0603_1608Metric
C3: 100n; C_0805_2012Metric
C4, C5: 2.2u; C_0603_1608Metric
C6, C7: 2.2u; C_1210_3225Metric
C8, C9, C10: 100nf; C_0603_1608Metric
C11, C12, C17, C18: 22u; C_1210_3225Metric
C27: 22u; C_0805_2012Metric
D1, D5: SM6T75A; D_SMB
D2: 15v; Nexperia_CFP3_SOD-123W
D3: Red; LED_0603_1608Metric
D4: Green; LED_0603_1608Metric
D6, D9, D14: SMF4L12A; D_SOD-123F
D7, D8, D13: SMF4L5.0A; D_SOD-123F
D10: Blue; LED_0603_1608Metric
D11: SP0503BAHT; SOT-143
D12: Yellow; LED_0603_1608Metric
F1: 1A; Fuse_Schurter_UMZ250
F2, F3, F4, F5: 1A; Fuse_1812_4532Metric
H1, H2, H3, H4, H5: MountingHole_Pad; MountingHole_3.2mm_M3_DIN965_Pad
J1: 60A 4 pin; Fat_Power 4
J2: 30A 2 Pin; Fat_Power 2
J3, J8: JST-PH-4; JST_PH_B4B-PH-SM4-TB_1x04-1MP_P2.00mm_Vertical
J4: 60A 4 Pin; Fat_Power 4
J5, J6: JST-XH-4; JST_XH_S4B-XH-A_1x04_P2.50mm_Horizontal
J7: JST-XH-2; JST_XH_S2B-XH-A_1x02_P2.50mm_Horizontal
J9: JST-PH-3; JST_PH_S3B-PH-SM4-TB_1x03-1MP_P2.00mm_Horizontal
L1, L2: 15uH; L_Wuerth_MAPI-4030
L3: 33uH; L_Coilcraft_MSS1210-XXX
L4, L5, L6, L7, L8, L9: 1uH; L_0805_2012Metric
Q1, Q4: BSS123; SOT-23
Q2, Q3: SQM120P10-19L; TO263_Heatsink_301
Q5: FDN340P; SOT-23
R1: 270k; R_0603_1608Metric
R2, R7, R16, R18, R30, R35, R36, R37: 10k; R_0603_1608Metric
R3: 64k9; R_0603_1608Metric
R4: 10K; R_0603_1608Metric
R5, R17, R21, R28, R33: 1k; R_0603_1608Metric
R6, R22, R23, R27: 4k7; R_0603_1608Metric
R8, R9: 82R; R_0603_1608Metric
R10: 88.7k; R_0603_1608Metric
R11, R14: 22.1k; R_0603_1608Metric
R12: 51k; R_0603_1608Metric
R13: 100k; R_0603_1608Metric
R15: 110k; R_0603_1608Metric
R19, R24, R25, R31: NF; R_0603_1608Metric
R20, R26, R32: 0R; R_0603_1608Metric
R29, R34: 1k8; R_0603_1608Metric
TH1: 10k; R_0603_1608Metric
U1, U2: LMR50410; SOT-23-6
U3: LMR38020; lmr38012
U4: ACS770xCB-050B-PFF; Allegro_CB_PFF
U5: ADS1015IDGS; TSSOP-10_3x3mm_P0.5mm
U6: MCP4725A0T; SOT-23-6
U7: AP2204K-ADJ; SOT-23-5
U8: PCF8574A; SOIC-16W_7.5x10.3mm_P1.27mm

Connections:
+3.3V: C12.1, C13.1, C15.1, C23.1, C24.1, C25.1, C30.1, D4.2 (A), D11.4 (K), F3.1, J3.3, J8.3, L2.2, R12.1, R13.2, R19.1, R23.1, R25.2, R27.1, R31.1, TH1.1, U4.1 (VCC), U5.8 (VDD), U6.3 (VDD), U8.16 (VDD)
+12V: C1.1, C2.1, C4.1, C5.1, C17.1, C18.1, C20.1, C26.1, F4.1, F5.2, L3.2, Q5.2 (S), R15.1, R30.1, U1.4 (~SHDN), U1.5 (VIN), U2.4 (~SHDN), U2.5 (VIN), U7.1 (VIN)
/12V_Good: R13.1, U3.6 (PG), U8.9 (P4)
/HV_On: D3.2 (A), Q1.1 (G), R7.1, U8.5 (P1)
/PA_Current: U4.3 (VIOUT), U5.4 (AIN0)
/PA_Voltage: R1.2, R2.1, U5.5 (AIN1)
/Vgg Cntrl: D12.2 (A), Q4.1 (G), R35.1, U8.6 (P2)
/Vgg_On: D10.2 (A), R22.1, U7.3 (EN), U8.4 (P0)
/Vgg_Voltage: R36.2, R37.1, U5.6 (AIN2)
GND: C1.2, C2.2, C3.2, C4.2, C5.2, C6.2, C7.2, C11.2, C12.2, C13.2, C14.2, C15.2, C16.2, C17.2, C18.2, C19.2, C20.2, C21.2, C22.2, C23.2, C24.2, C25.2, C26.2, C27.2, C28.2, C29.2, C30.2, D1.2 (A2), D5.2 (A2), D6.2 (A2), D7.2 (A2), D8.2 (A2), D9.2 (A2), D11.1 (A), D13.2 (A2), D14.2 (A2), H1.1, H2.1, H3.1, H4.1, H5.1, J2.1, J3.4, J5.4, J6.4, J7.2, J8.4, J9.3, Q1.2 (S), Q4.2 (S), R2.2, R3.2, R5.2, R7.2, R11.2, R14.1, R16.2, R17.2, R18.2, R20.1, R21.2, R22.2, R26.2, R28.2, R29.2, R32.1, R35.2, R37.2, U1.2 (GND), U2.2 (GND), U3.1 (GND), U3.9 (EP), U4.2 (GND), U5.3 (GND), U6.2 (VSS), U7.2 (GND), U8.2 (A1), U8.3 (A2), U8.8 (VSS)
unnamed: C11.1, C14.1, F2.1, L1.2, R10.1
unnamed: C16.1, F2.2, L4.1
unnamed: C19.1, F3.2, L5.2
unnamed: C21.1, F4.2, L6.1
unnamed: C22.1, F5.1, L7.1
unnamed: D1.1 (A1), D2.1 (K), F1.1, J1.1, Q2.3 (S), Q3.3 (S), R1.1, R4.1
unnamed: D2.2 (A), R4.2, R6.1, R8.1, R9.1
unnamed: D3.1 (K), R5.1
unnamed: D4.1 (K), R17.1
unnamed: D5.1 (A1), J4.1, U4.5 (IP-)
unnamed: D6.1 (A1), J5.1, J6.1, L6.2
unnamed: D7.1 (A1), J5.2, J6.2, L4.2
unnamed: D8.1 (A1), J5.3, J6.3, L5.1
unnamed: D9.1 (A1), J7.1, L7.2
unnamed: D10.1 (K), R21.1
unnamed: D12.1 (K), R28.1
unnamed: D13.1 (A1), J9.1, L9.2
unnamed: D14.1 (A1), J9.2, L8.2
unnamed: D11.2 (K), J3.1, J8.1, R23.2, U5.10 (SCL), U6.5 (SCL), U8.14 (SCL)
unnamed: D11.3 (K), J3.2, J8.2, R24.2, R27.2, U5.9 (SDA), U6.4 (SDA), U8.15 (SDA)
unnamed: Q1.3 (D), R6.2
unnamed: Q2.2 (D), Q3.2 (D), U4.4 (IP+)
unnamed: Q2.1 (G), R8.2
unnamed: Q3.1 (G), R9.2
unnamed: Q4.3 (D), Q5.1 (G), R30.2
unnamed: C28.1, L8.1, Q5.3 (D)
unnamed: C8.1, U1.1 (CB)
unnamed: R10.2, R11.1, U1.3 (FB)
unnamed: C8.2, L1.1, U1.6 (SW)
unnamed: C9.1, U2.1 (CB)
unnamed: R12.2, R14.2, U2.3 (FB)
unnamed: C9.2, L2.1, U2.6 (SW)
unnamed: C10.1, U3.7 (BOOT)
unnamed: C3.1, C6.1, C7.1, F1.2, U3.2 (EN), U3.3 (VIN)
unnamed: R15.2, R16.1, U3.5 (FB)
unnamed: R3.1, U3.4 (RT/SYNC)
unnamed: C10.2, L3.1, U3.8 (SW)
unnamed: R24.1, R25.1, R26.1, U5.1 (ADDR)
unnamed: R18.1, TH1.2, U5.7 (AIN3)
unnamed: R19.2, R20.2, U6.6 (A0)
unnamed: R34.2, U6.1 (VOUT)
unnamed: R29.1, R33.1, R34.1, U7.4 (ADJ)
unnamed: C27.1, C29.1, L9.1, R33.2, R36.1, U7.5 (VOUT)
unnamed: R31.2, R32.2, U8.1 (A0)

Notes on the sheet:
5V 1A Switching Regulator
Current Monitor 50A
Quad ADC
Digital Control
LMR50410 3.3V Output Voltage = 1.0 * (51 +22.1) / 22.1 = 3.3V
I2C Out
Res = 100uOhm @50A = .25W
LMR38020 12V Output Voltage = 1.0 * (110 + 10) / 10 = 12V
Low Voltage Outputs
I2C In
HV Power Switch
LMR50410 5V Output Voltage = 1.0 * (88.7 +22.1) / 22.1 = 5V
I2C Address 0x70 or 0x72
Vgg Enable
FET 93A .011R Rds On Dissapation = 2 * (25 ^^2) * .011 = 12.5W
12V 2A Switching Regulator
3.3V 1A Switching Regulator
Vgg DAC
I2C Address 0x60 or 0x61
Power Input 14V to 72V DC 0 to 50A
I2C Address 0x48, 0x49, or 0x4A
Programmable Vgg LDO Regulator 1.4V to 4.7V


Board: 4 copper layers, 100.0 x 100.0 mm, 123 parts (0 on the bottom side), 54 nets.

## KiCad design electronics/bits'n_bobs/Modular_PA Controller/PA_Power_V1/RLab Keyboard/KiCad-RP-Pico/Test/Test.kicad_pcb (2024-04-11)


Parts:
J1, J2: Conn_01x20; PinSocket_1x20_P1.00mm_Vertical
J3: Conn_01x03; PinSocket_1x03_P1.00mm_Vertical
U1: Pico; RPi_Pico_SMD_TH

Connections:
GND: J1.3, J1.8, J1.13, J1.18, J2.3, J2.13, J2.18, J3.2, U1.3 (GND), U1.8 (GND), U1.13 (GND), U1.18 (GND), U1.23 (GND), U1.28 (GND), U1.38 (GND), U1.42 (GND)
unnamed: J1.1, U1.1 (GPIO0)
unnamed: J1.2, U1.2 (GPIO1)
unnamed: J1.4, U1.4 (GPIO2)
unnamed: J1.5, U1.5 (GPIO3)
unnamed: J1.6, U1.6 (GPIO4)
unnamed: J1.7, U1.7 (GPIO5)
unnamed: J1.9, U1.9 (GPIO6)
unnamed: J1.10, U1.10 (GPIO7)
unnamed: J1.11, U1.11 (GPIO8)
unnamed: J1.12, U1.12 (GPIO9)
unnamed: J1.14, U1.14 (GPIO10)
unnamed: J1.15, U1.15 (GPIO11)
unnamed: J1.16, U1.16 (GPIO12)
unnamed: J1.17, U1.17 (GPIO13)
unnamed: J1.19, U1.19 (GPIO14)
unnamed: J1.20, U1.20 (GPIO15)
unnamed: J2.1, U1.40 (VBUS)
unnamed: J2.2, U1.39 (VSYS)
unnamed: J2.4, U1.37 (3V3_EN)
unnamed: J2.5, U1.36 (3V3)
unnamed: J2.6, U1.35 (ADC_VREF)
unnamed: J2.7, U1.34 (GPIO28_ADC2)
unnamed: J2.8, U1.33 (AGND)
unnamed: J2.9, U1.32 (GPIO27_ADC1)
unnamed: J2.10, U1.31 (GPIO26_ADC0)
unnamed: J2.11, U1.30 (RUN)
unnamed: J2.12, U1.29 (GPIO22)
unnamed: J2.14, U1.27 (GPIO21)
unnamed: J2.15, U1.26 (GPIO20)
unnamed: J2.16, U1.25 (GPIO19)
unnamed: J2.17, U1.24 (GPIO18)
unnamed: J2.19, U1.22 (GPIO17)
unnamed: J2.20, U1.21 (GPIO16)
unnamed: J3.1, U1.43 (SWDIO)
unnamed: J3.3, U1.41 (SWCLK)


Board: 2 copper layers, 43.0 x 65.0 mm, 4 parts (0 on the bottom side), 36 nets.

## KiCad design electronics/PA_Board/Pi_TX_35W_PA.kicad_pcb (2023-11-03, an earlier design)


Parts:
H1, H2, H3, H4: MountingHole_Pad; MountingHole_4.3mm_M4_DIN965_Pad
HS1: Heatsink; Copper_Pad
LOGO1: Logo_Open_Hardware_Small; OSHW-Logo2_9.8x8mm_SilkScreen

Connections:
GND: H1.1, H2.1, H3.1, H4.1; also elsewhere on the board

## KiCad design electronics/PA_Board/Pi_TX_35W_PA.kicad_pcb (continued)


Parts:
C1, C4, C6: 1u; C_0603_1608Metric
C2: 4n7; C_0603_1608Metric
C3, C5, C7, C8, C9, C10: 100n; C_0603_1608Metric
C11, C12: 1n; C_0603_1608Metric
D1, D4, D5: SP0503BAHT; SOT-143
D2: APA102-2020; LED-APA102-2020
D3: LED_Orange; LED_0603_1608Metric
D6, D7: 1SS400; D_SOD-523
J1: USB_B_Micro; USB_Micro-B_Molex-105017-0001
J2: Conn_01x05; Debug_Clip
J3: Conn_01x05; JST_PH_S5B-PH-SM4-TB_1x05-1MP_P2.00mm_Horizontal
J4: Conn_01x04; JST_PH_S4B-PH-SM4-TB_1x04-1MP_P2.00mm_Horizontal
L1: L_Ferrite; L_0603_1608Metric
R1: 1M; R_0603_1608Metric
R2, R3: 1k; R_0603_1608Metric
R4, R5, R6, R7, R8, R9, R10, R11, R20, R21: 4k7; R_0603_1608Metric
R12: 47k; R_0603_1608Metric
R13, R14, R15, R24, R25: 10k; R_0603_1608Metric
R16, R17, R18, R19: 100k; R_0603_1608Metric
R22, R23: 330R; R_0603_1608Metric
SW1: SW_Push; Panasonic_EVQPUL_EVQPUC
U1: ATSAMD21E18A-A; TQFP-32_7x7mm_P0.8mm
U2: LM75B; SOIC-8_3.9x4.9mm_P1.27mm
U3: LM2904; SOIC-8_3.9x4.9mm_P1.27mm

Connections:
+3.3V: C4.1, C5.1, C7.1, C8.1, C9.1, C10.1, D2.1 (VDD), D5.4 (K), J2.1, J4.3, L1.1, R2.1, R4.1, R5.1, R6.1, R7.1, R8.1, R9.1, R10.1, R11.1, U1.30 (VDDIN), U2.8 (+Vs), U3.8 (V+); also elsewhere on the board
/PA_Power/En_Vgg_PA: U1.16 (PA15); also elsewhere on the board
/PA_Power/Int_SCL: R7.2, U1.22 (PA23), U2.2 (SCL); also elsewhere on the board
/PA_Power/Int_SDA: R9.2, U1.21 (PA22), U2.1 (SDA); also elsewhere on the board
/PA_Power/VBus: D1.4 (K), J1.1 (VBUS); also elsewhere on the board
/PA_Power/VGG_PA: R12.2; also elsewhere on the board
/PA_Power/VI2C: J3.4; also elsewhere on the board
/PA_Protection/ADC_Fwd: C11.1, R23.2, R24.1, U1.4 (PA03)
/PA_Protection/ADC_Rev: C12.1, R22.2, R25.1, U1.5 (PA04)
/PA_Protection/ADC_Vgg_PA: R12.1, R15.1, U1.6 (PA05)
/PA_Protection/D+: D1.3 (K), J1.3 (D+), U1.24 (PA25)
/PA_Protection/D-: D1.2 (K), J1.2 (D-), U1.23 (PA24)
/PA_Protection/Ext_SCL: D5.2 (K), J4.1, R10.2, U1.18 (PA17)
/PA_Protection/Ext_SDA: D5.3 (K), J4.2, R11.2, U1.17 (PA16)
/PA_Protection/Slave_INT: D4.2 (K), J3.1, R4.2, U1.14 (PA11)
/PA_Protection/Slave_SCL: D4.4 (K), J3.3, R8.2, U1.12 (PA09)
/PA_Protection/Slave_SDA: D4.3 (K), J3.2, R5.2, U1.11 (PA08)
/PA_Protection/TX_Relay: U1.7 (PA06); also elsewhere on the board
/PA_Protection/Temp_INT: R6.2, U1.20 (PA19), U2.3 (O.S.)
/PA_Protection/VFwd: R13.1; also elsewhere on the board
/PA_Protection/VRev: R14.1; also elsewhere on the board
GND: C1.2, C2.2, C3.2, C4.2, C5.2, C6.2, C7.2, C8.2, C9.2, C10.2, C11.2, C12.2, D1.1 (A), D2.6 (GND), D3.1 (K), D4.1 (A), D5.1 (A), J1.5 (GND), J2.4, J3.5, J4.4, R1.2, R15.2, R16.2, R17.2, R18.2, R19.2, R24.2, R25.2, SW1.2, U1.10 (GND), U1.28 (GND), U2.4 (GND), U2.5 (A2), U2.6 (A1), U2.7 (A0), U3.4 (V-); also elsewhere on the board
unnamed: C1.1, C3.1, L1.2, U1.9 (VDDANA)
unnamed: C2.1, J1.6 (Shield), R1.1
unnamed: C6.1, U1.29 (VDDCORE)
unnamed: D2.4 (SDI), U1.1 (PA00)
unnamed: D2.5 (CKI), U1.2 (PA01)
unnamed: D3.2 (A), R3.1
unnamed: D6.1 (K), R19.1, U3.6 (-)
unnamed: D6.2 (A), R21.2
unnamed: D7.1 (K), R18.1, U3.2 (-)
unnamed: D7.2 (A), R20.2
unnamed: J2.2, R2.2, U1.31 (PA30)
unnamed: J2.3, U1.32 (PA31)
unnamed: J2.5, SW1.1, U1.26 (~RESET)
unnamed: R3.2, U1.13 (PA10)
unnamed: R13.2, R16.1, U3.3 (+)
unnamed: R14.2, R17.1, U3.5 (+)
unnamed: R20.1, R23.1, U3.1
unnamed: R21.1, R22.1, U3.7

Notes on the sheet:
I2C Address 0x48
Arduino Pin Mapping ATSAMD21E18 I/O Multiplexer 0 PA00 DOTSTAR SDI 1 PA01 DOTSTAR CLK 2 PA03 ADC_FWD 3 PA04 ADC_REV 4 PA05 ADC_Vgg 5 PA06 TX_Relay_Out 6 PA08 SERCOM0 PAD 0 Slave_SDA 7 PA09 SERCOM0 PAD 1 Slave_SCL 8 PA10 Watchdog LED 9 PA11 SLAVE GPIO INT 10 PA15 En_Vgg_PA 11 PA16 SERCOM1 PAD 0 Ext_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
Temperature Sensor
Raspberry Pi I2C Control Interface
Compensating RF Detector Buffer Amplifiers


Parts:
C27, C28, C33, C34, C49: 100n; C_0603_1608Metric
C29, C52, C53, C54: 10n; C_0603_1608Metric
C30, C36, C37, C50: 100p; C_0603_1608Metric
C31: 22u; CP_EIA-7360-38_Kemet-E
C32: 22u; C_0805_2012Metric
C35: 330p; C_0603_1608Metric
C38: 9p1; L_1206_3216Metric
C39, C42: 18p; L_1206_3216Metric
C40, C43: NF; L_1206_3216Metric
C41: 3p; L_1206_3216Metric
C44, C47, C48, C51: 1n; C_0603_1608Metric
C45: 6p8; L_1206_3216Metric
C46: 1u; C_0603_1608Metric
D12, D13, D14, D15: LRB751S; D_SOD-523
D16: 1SS400; D_SOD-523
D17: LED_Red; LED_0603_1608Metric
J6, J7, J8, J9: Conn_Coaxial; SMA_Samtec_SMA-J-P-X-ST-EM1_EdgeMount
K1: G6E; Relay_SPDT_Omron_G6E
L3: 200nH; L_1812_4532Metric
L4: 1uH; L_0805_2012Metric
L5, L7: 34nH; Wire_Inductor 12x8.5
L6: 46nH; Wire_Inductor 15.5x8.5
L8, L9: 1.5u; L_0805_2012Metric
L10, L11, L12: 1u; L_0805_2012Metric
Q2: BC848W; SOT-23
R37, R39, R40, R41, R44, R45: 150R; R_0603_1608Metric
R38: 37.4R; R_0603_1608Metric
R42: 49.9R; R_0603_1608Metric
R43: 49.9k; R_0603_1608Metric
R46: 4k7; R_0603_1608Metric
R47, R48: 10k; R_0603_1608Metric
U9: SPF5189Z; SOT-89-3
U10: RA35H1516M; RF_PA_Module
U11: Directional_Coupler; Wiggly Coupler

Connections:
+5V: C28.2, C30.2, L4.1; also elsewhere on the board
+12V: C46.1, C49.1, C50.1, L10.1, R48.1; also elsewhere on the board
/PA_Power/VDD_PA: C27.1, L3.1; also elsewhere on the board
/PA_Power/VGG_PA: C32.1, C34.1, C37.1, U10.2 (Vgg); also elsewhere on the board
/PA_Protection/TX_Relay: R46.2; also elsewhere on the board
/PA_Protection/VFwd: C47.1, L8.2; also elsewhere on the board
/PA_Protection/VRev: C48.1, L9.1; also elsewhere on the board
GND: C27.2, C28.1, C30.1, C31.2, C32.2, C33.2, C34.2, C36.2, C37.2, C39.2, C40.2, C42.2, C43.2, C44.2, C45.2, C46.2, C47.2, C48.2, C49.2, C50.2, C51.2, C52.2, C54.2, D13.2 (A), D15.2 (A), J6.2 (Ext), J7.2 (Ext), J8.2 (Ext), J9.2 (Ext), Q2.2 (E), R37.2, R39.2, R40.2, R41.2, R42.2, R44.1, R45.1, R47.2, U9.2 (GND), U10.5 (Gnd), U10.6 (Gnd); also elsewhere on the board
unnamed: C29.1, U9.1
unnamed: C29.2, R38.1, R39.1
unnamed: C31.1, C33.1, C36.1, L3.2, U10.3 (Vdd)
unnamed: C35.1, U10.1 (RF_In)
unnamed: C35.2, L4.2, U9.3
unnamed: C38.1, L5.1, U10.4 (RF_Out)
unnamed: C38.2, C39.1, C40.1, C41.1, L5.2, L6.1
unnamed: C41.2, C42.1, C43.1, L6.2, L7.1
unnamed: C44.1, D12.1 (K), L8.1
unnamed: C45.1, K1.12, L7.2, R43.2, U11.1 (RF)
unnamed: C51.1, D14.1 (K), L9.2
unnamed: C52.1, C53.2, D16.1 (K), L10.2, L11.2
unnamed: C53.1, C54.1, D16.2 (A), D17.1 (K), L12.2, Q2.3 (C)
unnamed: D12.2 (A), D13.1 (K), R44.2, R45.2, U11.2 (Fterm)
unnamed: D14.2 (A), D15.1 (K), R40.1, R41.1, U11.3 (Rout)
unnamed: D17.2 (A), R48.2
unnamed: J6.1 (In), R37.1, R38.2
unnamed: J7.1 (In), R42.1, R43.1
unnamed: J8.1 (In), K1.10
unnamed: J9.1 (In), K1.7
unnamed: K1.1, L11.1
unnamed: K1.6, L12.1
unnamed: Q2.1 (B), R46.1, R47.1

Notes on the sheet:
6dB Attenuator
JLCPCB Design Rules: Min. Hole size 0.2mm Min Via size 0.4mm Min. Pad size 1mm Min. Pad spacing 0.127mm Min track width 0.09mm Min Track Spacing 0.09mm
+17dBm
Stackup is: Copper 0.035mm (1oz) Prepreg 0.21 mm Copper 0.0152mm (0.5oz) Core 1.065mm Copper 0.0152mm (0.5oz) Prepreg 0.21mm Copper 0.035mm ( 1oz)
Current capability width: 1A 1oz = 0.3mm 0.5oz = 0.69mm 3A 1oz = 1.36mm 0.5oz = 3.15mm 10A 1oz = 7.2mm 0.5oz = 16.6mm
Antenna
PA Gain
TX_Monitor
45dBm
Lime Tx via RX board Bandpass Filter
0dBm
Low Pass Filter
-60dBm = 1000:1 Volts
-15dBm
Track Impedance 50 ohms Top two layers: width = 0.35mm Top to bottom layer width = 2.7 mm Top to layer 3 width = 2.35mm
Relay coil current 16.6mA
PCB is 4 layer from JLCPCB type JLC7628 Dielectric Constant is 4.6 and overall thickness 1.6mm


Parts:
C13: 10u 50V; C_0805_2012Metric
C14, C16, C18, C22, C23, C25, C26: 100n; C_0603_1608Metric
C15: 150p; C_0603_1608Metric
C17: 22u; C_0805_2012Metric
C19: 1u 50V; C_0603_1608Metric
C20: 2.2u; C_0603_1608Metric
C21, C24: 10u; C_0603_1608Metric
D8: B340; D_SMA
D9, D10, D11: MBR0540; D_SOD-123
J5: Conn_01x02; PhoenixContact_MSTBA_2,5_2-G_1x02_P5.00mm_Horizontal
L2: 15uH; L_7.3x7.3_H4.5
Q1: RD3G01BAT; TO-252-2
R26, R28, R29: 100k; R_0603_1608Metric
R27: 22k; R_0603_1608Metric
R30: 210k; R_0603_1608Metric
R31: 40.2k; R_0603_1608Metric
R32: 10k; R_0603_1608Metric
R33: 470R; R_0603_1608Metric
R34: 1k; R_0603_1608Metric
R35: 1k2; R_0603_1608Metric
R36: 10m; R_0612_1632Metric
U4: MP1584; SOIC-8-1EP_3.9x4.9mm_P1.27mm_EP2.41x3.3mm
U5: MCP4725; SOT-23-6
U6: AP2204K-ADJ; SOT-23-5
U7: TLV70233; SOT-23-5
U8: INA219AxD; SOIC-8_3.9x4.9mm_P1.27mm

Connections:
+3.3V: C16.1, C24.1, C25.1, C26.1, U5.3 (VDD), U7.5 (OUT), U8.5 (VS); also elsewhere on the board
+5V: C17.1, C18.1, D9.2 (A), L2.1, R30.1; also elsewhere on the board
+12V: C13.1, C19.1, Q1.3 (S), R26.1, R36.2, U4.7 (Vin), U6.1 (VIN), U8.8 (IN+); also elsewhere on the board
/PA_Power/En_Vgg_PA: R32.1, U6.3 (EN); also elsewhere on the board
/PA_Power/Int_SCL: U5.5 (SCL), U8.4 (SCL); also elsewhere on the board
/PA_Power/Int_SDA: U5.4 (SDA), U8.3 (SDA); also elsewhere on the board
/PA_Power/VBus: D10.2 (A); also elsewhere on the board
/PA_Power/VDD_PA: R36.1, U8.7 (IN-); also elsewhere on the board
/PA_Power/VGG_PA: C20.1, C22.1, R35.1, U6.5 (VOUT); also elsewhere on the board
/PA_Power/VI2C: D11.2 (A); also elsewhere on the board
GND: C13.2, C16.2, C17.2, C18.2, C19.2, C20.2, C21.2, C22.2, C23.2, C24.2, C25.2, C26.2, D8.2 (A), J5.2, Q1.1 (G), R27.2, R28.2, R29.2, R31.2, R32.2, R33.2, U4.5 (Gnd), U4.9 (EP), U5.2 (VSS), U6.2 (GND), U7.2 (GND), U8.1 (A1), U8.2 (A0), U8.6 (GND); also elsewhere on the board
unnamed: C14.1, D8.1 (K), L2.2, U4.1 (Sw)
unnamed: C14.2, U4.8 (Bst)
unnamed: C15.1, U4.3 (Comp)
unnamed: C15.2, R29.1
unnamed: C21.1, C23.1, D9.1 (K), D10.1 (K), D11.1 (K), U7.1 (IN), U7.3 (EN)
unnamed: J5.1, Q1.2 (D)
unnamed: R26.2, R27.1, U4.2 (En)
unnamed: R28.1, U4.6 (Freq)
unnamed: R30.2, R31.1, U4.4 (Fb)
unnamed: R33.1, R34.1, R35.2, U6.4 (ADJ)
unnamed: R34.2, U5.1 (VOUT)

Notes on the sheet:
5V @ 500mA
Power Input
2.0 to 5.85V @5mA
I2C Address 0x61
+13.8V @ 8A Battery
I2C address = 0x40
MP1584
Internal 3.3V @250mA
AP2204 Vref = 1.24V I(R33) Vref / R33 = 1.24/470 = 2.63mA Vdac(4095) = 3.3V Vdac(0) = 0V I(R34) = (Vdac - Vref) / R34 = 2.06mA(0) = -1.24mA(4095) I(R35) = I(33) - I(R34) = 3.88mA(0) = 0.58(4095) V(R35) = I(R35) * R35 = 4.65V(0) = 0.69V(4095) Vout = V(R35) + Vref = 5.89V(0) = 1.93V(4095)
R Sense PA = 0.08V / 8A = 10 mOhm
Polarity Protection
Power = 8 * 8 * .010 = 0.64W
Output Voltage = 0.8 * (210+40.2)/ 40.2 = 4.98V
En Threshold = 1.5 * 122 / 22 = 8.3V


Board: 4 copper layers, 100.0 x 100.0 mm, 161 parts (1 on the bottom side), 77 nets.

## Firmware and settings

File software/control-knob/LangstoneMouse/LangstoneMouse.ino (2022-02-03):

// Rotary Encoder and Button Mouse Emulation for Langstone Transceiver. By Colin Durbridge G4EML
// for Arduino Pro Micro Board. (5V 16MHz Version) (won't work with all Arduinos. Needs the ATmega32U4 chip for USB Mouse emulation.
// Needs the Encoder Library by Paul Stoffregen. (Search for Encoder in Library Manager)
// Rotary encoder (used as tuning knob) is read and scaled to suitable output pulses per revolution then sent as mouse scroll wheel movement every 20 ms.
// 3 Buttons (used to select tuning rate and dial lock) are read and sent as mouse clicks on the left, middle and right mouse buttons.
//
// Mod by M0ZSU, if flex flag is set, do not emulate mouse, send Flex like ASCII on the serial port instead.
// TODO :Implement buttons, add compile flags so it can compile as Flex only with non ATmega32U4 boards as Flex emulation only needs serial port.

#include <Mouse.h>
#include <Encoder.h>
// #include <SoftWire.h>


#define encoderStepsPerRev 400                   //number of steps per revolution of the encoder. Change this to match your encoder.  

#define outputStepsPerRev  40                    //nuber of steps per revolution for tuning. 40 is a good number to start with. Change this if you want to adjust the tuning rate. 

#define RPHA 3                        //Rotary encoder A phase connected to Pin 2. Encoder Common connection to ground.  (do not change, needs the interrupt on this pin to work properly)
#define RPHB 2                        //Rotary encoder B phase connected to Pin 3. Swap these two pins to reverse the encoder direction.                                    
#define LEFTBUTTON 4                //Left, right and middle push buttons. Used by Langstone to select the tuning rate and dial lock. 
#define RIGHTBUTTON 5               //Connect buttons between these three pins and ground. 
#define MIDDLEBUTTON 6

#define FLEXSELECTPIN 7               //Short to ground to select FlexKnob emulation mode


#define SERIAL_BAUD     9600 // FlexKnob 9600 by default


int encoderDiv;
int leftButton;
int rightButton;
int middleButton;
int leftButtonReleased;
int rightButtonReleased;
int middleButtonReleased;
int incomingByte = 0;
int flexswitch;

Encoder Enc(RPHA, RPHB);

bool flex = false;
bool start = true;
bool mousesupport = false;


void setup()
{

#if defined(__AVR_ATmega32U4__) //Check if we have hardware for mouse emulation at compile time
  mousesupport = true;
#warning "Mouse support detected";
  //SoftWire sw(SOFTSDAPIN, SOFTSCLPIN);
#endif

  pinMode(FLEXSELECTPIN, INPUT_PULLUP); // Physical switch on pin 7 to select mouse emulation (Langstone etc.) or FlexKnob emulation.
  flexswitch = digitalRead(FLEXSELECTPIN);

  flex = ((flexswitch == LOW) or (mousesupport == false)); // If there is no mouse hardware we have to run in Flex mode.


  encoderDiv=(encoderStepsPerRev*4)/outputStepsPerRev;                     // calculate the requred encoder divisor. (Encoder library outputs 4 steps per input step)
  pinMode(LEFTBUTTON,INPUT_PULLUP);
  pinMode(RIGHTBUTTON,INPUT_PULLUP);
  pinMode(MIDDLEBUTTON,INPUT_PULLUP);
  leftButtonReleased=false;
  rightButtonReleased=false;
  middleButtonReleased=false;

  if (mousesupport == false) //if there is no mouse hardware force Flex mode
  {
  flex=true;
}

  if (flex)
  {
  Serial.begin(SERIAL_BAUD);
}
  else
  {
  Mouse.begin();
}


}

  void loop()
  {
  delay(20);     //delay to slow down the rate of USB messages. 50 per second is plenty.

  if (flex)
  {

  if (Serial.dtr() == false) // Send ID code once when port becomes active, currently this is done by checking DTR
  {
  start= true;
  while (Serial.dtr() == false)
  {
  ;
}

}

  if (start)
  {
  for (uint8_t i = 0; i < 1; i++) Serial.write("F0304;");
  start = false;
}

  //  if (Serial.available() > 0) {
  //    // read the incoming byte:
  //    incomingByte = Serial.read();
  //
  //    // say what you got:
  //    Serial.print("I received: ");
  //    Serial.println(incomingByte, DEC);
  //  }

}

  long counts = Enc.read()/encoderDiv;    //number of encoder counts since last sent to USB.

  if(counts!=0)
  {
  if (!flex)
  {
  Mouse.move(0,0,counts);
}
  else
  {
  if (counts> 0)
  {
  for (uint8_t i = 0; i < counts; i++) Serial.write("U;");
}
  else if (counts< 0)
  {
  for (long i = counts; i < 0; i++) Serial.write("D;");
}

}
  Enc.write(0);                         //reset the encoder counts
}

  leftButton=digitalRead(LEFTBUTTON);
  rightButton=digitalRead(RIGHTBUTTON);
  middleButton=digitalRead(MIDDLEBUTTON);

  if(leftButton==LOW)
  {
  if(leftButtonReleased>=3)
  {
  if (!flex)
  {
  Mouse.click(MOUSE_LEFT);
  
}
  else
  {
  Serial.write("X1;");
}
  leftButtonReleased=false;
}
}
  else
  {
  if(leftButtonReleased<3) leftButtonReleased=leftButtonReleased+1;
}


  if(rightButton==LOW)
  {
  if(rightButtonReleased>=3)
  {
  if (!flex)
  {
  Mouse.click(MOUSE_RIGHT);
}
  else
  {
  Serial.write("X3;");
}
  rightButtonReleased=false;
}
}
  else
  {
  if(rightButtonReleased<3) rightButtonReleased=rightButtonReleased+1;
}


  if(middleButton==LOW)
  {
  if(middleButtonReleased>=3)
  {
  if (!flex)
  {
  Mouse.click(MOUSE_MIDDLE);
}
  else
  {
  Serial.write("X2;");
}

  middleButtonReleased=false;
}
}
  else
  {
  if(middleButtonReleased<3) middleButtonReleased=middleButtonReleased+1;
}

}

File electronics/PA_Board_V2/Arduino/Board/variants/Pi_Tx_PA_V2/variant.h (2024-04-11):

/*
  Copyright (c) 2014-2015 Arduino LLC.  All right reserved.

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
  You should have received a copy of the GNU Lesser General Public
  License along with this library; if not, write to the Free Software
  Foundation, Inc., 51 Franklin St, Fifth Floor, Boston, MA  02110-1301  USA
*/

#ifndef _VARIANT_Pi_Tx_PA_
#define _VARIANT_Pi_Tx_PA_

// The definitions here needs a SAMD core >=1.6.10
#define ARDUINO_SAMD_VARIANT_COMPLIANCE 10610

/*----------------------------------------------------------------------------
 *        Definitions
 *----------------------------------------------------------------------------*/

/** Frequency of the board main oscillator */
#define VARIANT_MAINOSC		(32768ul)

/** Master clock frequency */
#define VARIANT_MCK	(F_CPU)

/*----------------------------------------------------------------------------
 *        Headers
 *----------------------------------------------------------------------------*/

#include "WVariant.h"
#ifdef __cplusplus
#include "SERCOM.h"
#include "Uart.h"
#endif // __cplusplus

#ifdef __cplusplus
extern "C"
{
#endif // __cplusplus

/*----------------------------------------------------------------------------
 *        Pins
 *----------------------------------------------------------------------------*/

// Number of pins defined in PinDescription array
#define PINS_COUNT           (21u)
#define NUM_DIGITAL_PINS     (15u)
#define NUM_ANALOG_INPUTS    (3u)
#define NUM_ANALOG_OUTPUTS   (0u)
#define analogInputToDigitalPin(p)  ((p < 3u) ? (p) + PIN_A0 : -1)

#define digitalPinToPort(P)        ( &(PORT->Group[g_APinDescription[P].ulPort]) )
#define digitalPinToBitMask(P)     ( 1 << g_APinDescription[P].ulPin )
#define portOutputRegister(port)   ( &(port->OUT.reg) )
#define portInputRegister(port)    ( &(port->IN.reg) )
#define portModeRegister(port)     ( &(port->DIR.reg) )
#define digitalPinHasPWM(P)        ( g_APinDescription[P].ulPWMChannel != NOT_ON_PWM || g_APinDescription[P].ulTCChannel != NOT_ON_TIMER )



// LEDs
#define PIN_LED              (8u)
#define LED_BUILTIN          PIN_LED
#define LED_WATCHDOG         PIN_LED
#define WATCHDOG_LED         PIN_LED

//  RGBW addressable LEDs
#define PIN_SK6812_DATA      (0u)
#define SK6812_NUM           (02u)

/*
 * Analog Pins
 */
#define PIN_A0               (1ul)
#define PIN_A1               (PIN_A0 + 1)
#define PIN_A2               (PIN_A0 + 2)
#define PIN_DAC0             (-1ul) // DAC not used
#define PIN_ADC_FWD          PIN_A0
#define PIN_ADC_REV          PIN_A1
#define PIN_ADC_VGG          PIN_A2

static const uint8_t A0  = PIN_A0;
static const uint8_t A1  = PIN_A1;
static const uint8_t A2  = PIN_A2;


#define ADC_RESOLUTION		12

/*
 * Digital Pins
 */
#define PIN_TX_RELAY         (4u)
#define PIN_DRIVER_EN        (5u)
#define PIN_PI_TX_EN         (9u)
#define PIN_FAN_RPM          (10u)
#define PIN_EN_VGG           (11u)
#define PIN_FAN_PWM          (14u)
#define PIN_LM75_INT         (15u)

/*
 * Serial interfaces
 */

// Serial1 (sercom 0)
#define PIN_SERIAL1_TX       (6ul) // PA08
#define PAD_SERIAL1_TX       (UART_TX_PAD_0)
#define PIN_SERIAL1_RX       (7ul) // PA09
#define PAD_SERIAL1_RX       (SERCOM_RX_PAD_1)

/*
 * SPI Interfaces
 */
#define SPI_INTERFACES_COUNT 1 // We don't use an SPI interface, but some libraries Adafruit OLED appear to need one defined

#define PIN_SPI_MISO         (-1)  // setup with dummy pins
#define PIN_SPI_MOSI         (-1)
#define PIN_SPI_SCK          (-1)
#define PERIPH_SPI           sercom0
#define PAD_SPI_TX           SPI_PAD_2_SCK_3
#define PAD_SPI_RX           SERCOM_RX_PAD_1


/*
 * Wire Interfaces
 */
#define WIRE_INTERFACES_COUNT 2

/*
 * The internal I2C Bus
 */
#define PIN_WIRE_SDA         (16u)
#define PIN_WIRE_SCL         (17u)
#define PERIPH_WIRE          sercom3
#define WIRE_IT_HANDLER      SERCOM3_Handler
static const uint8_t SDA = PIN_WIRE_SDA;
static const uint8_t SCL = PIN_WIRE_SCL;


/*
 * The external I2C Bus
 */
#define PIN_WIRE1_SDA         (12u)
#define PIN_WIRE1_SCL         (13u)
#define PERIPH_WIRE1          sercom1
#define WIRE1_IT_HANDLER      SERCOM1_Handler
static const uint8_t SDA1 = PIN_WIRE1_SDA;
static const uint8_t SCL1 = PIN_WIRE1_SCL;

/*
 * USB
 */
#define PIN_USB_HOST_ENABLE (33ul)
#define PIN_USB_DM          (34ul)
#define PIN_USB_DP          (35ul)

#ifdef __cplusplus
}
#endif

/*----------------------------------------------------------------------------
 *        Arduino objects - C++ only
 *----------------------------------------------------------------------------*/

#ifdef __cplusplus

/*	=========================
 *	===== SERCOM DEFINITION
 *	=========================
 * The ATSAMD21E18 only has four SERCOM Ports and we ony use 3 due to Pin limitations
 * SERCOM0 is Serial
 * SERCOM1 is Wire
 * SERCOM3 is Wire1
 * 
*/

extern SERCOM sercom0;
extern SERCOM sercom1;
extern SERCOM sercom3;

extern Uart Serial1;


#endif


//
// SERIAL_PORT_USBVIRTUAL     Port which is USB virtual serial
//

#define SERIAL_PORT_USBVIRTUAL      Serial
#define SERIAL_PORT_MONITOR         Serial

// Serial has no physical pins broken out, so it's not listed as HARDWARE port
#define SERIAL_PORT_HARDWARE        Serial1
#define SERIAL_PORT_HARDWARE_OPEN   Serial1

#endif /* _VARIANT_Pi_Tx_PA_ */

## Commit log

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2022-01-03 Add a log, fix the buttons, get an initial update at the right time
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2022-01-04 Revert "Hack in mouse X axis tuning"
    This reverts commit 200ec5ba17e3022493f23212675e0e129de4f12e.
2022-01-04 Add DC block and LPF to flow graph, make it runnable from the command line
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2022-01-10 Invert relays since we're normally in RX
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2022-01-14 M0zsu encoder (#27)
    Switched on DTR for compatibility with FlexKnob emulation on Arduino Pro Micro
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2022-01-18 Imported bob powerpole and upgraded to kicad 6. Also added shutdown interface and latching input mosfet
    [pi-tranceiver-psu.kicad_pcb, pi-tranceiver-psu.kicad_sch]
2022-01-21 Re-upload conflicting files
    [WEBENCH LM2679 BOM.csv, pi-tranceiver-psu.kicad_sch]
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2022-02-03 G4CDF branch (#41)
    * 144 MHz BPF design
    Excel spreadsheet to design 4 pole bandpass filter. 1dB bandwidth form 144 to 147 MHz.
    * Dummy upload
    [Filters.xlsx]
2022-02-03 All of the changes on Gareth's branch vs current main (#44)
    [Filters.xlsx, pi-tranceiver-psu.csv, pi-tranceiver-psu.kicad_sch]
2022-02-03 M0ZSU encoder (#45)
    * Update README.md
    * Update FlexKnob.cs
    * Create LangstoneMouse.ino
    Added initial work in progress code
    * Create LangstoneMouse.ino
    Testing mouse detection
    * Update LangstoneMouse.ino
    * Update LangstoneMouse.ino
    Improvements, implements buttons. Note link pin 7 to ground for Flex emulation
    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
    [LangstoneMouse.ino]
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2022-02-10 Don't flip relay any more
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2022-02-14 Bug fix on I2C enabled check
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2022-02-28 Added pi_transceiver_hat KiCad project
    [pi_transceiver_hat.kicad_pcb, pi_transceiver_hat.kicad_sch]
2022-03-02 Added fan sockets
    [pi_transceiver_hat.kicad_sch]
2022-03-07 More PCB hat design
    [pi_transceiver_hat.kicad_pcb, pi_transceiver_hat.kicad_sch]
2022-03-11 More PCB updates
    [pi_transceiver_hat.kicad_pcb]
2022-03-14 More hat board design.
    [pi_transceiver_hat.kicad_pcb, pi_transceiver_hat.kicad_sch]
2022-03-15 PCB updates for hat.
    [pi_transceiver_hat.kicad_pcb, pi_transceiver_hat.kicad_sch]
2022-03-16 Hat PCB alpha design
    [pi_transceiver_hat.kicad_pcb, pi_transceiver_hat.kicad_sch]
2022-03-16 Initial commit of "bits'n_bobs" in electronics
    Added the kicad file and short README for test modules and breakouts
    [Broadcast_Filter-B_Cu.gbr, Broadcast_Filter-B_Mask.gbr, Broadcast_Filter-B_Paste.gbr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]
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2022-03-16 Gerber generation for hat.
    [pi_transceiver_hat-B_Cu.gbl, pi_transceiver_hat-B_Mask.gbs, pi_transceiver_hat-B_Paste.gbp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]
2022-03-23 update pi_transceiver_hat Kicad
    Change to "all copper layers" for some connector holes
    [pi_transceiver_hat-B_Cu.gbl, pi_transceiver_hat-B_Mask.gbs, pi_transceiver_hat-B_Paste.gbp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]
2022-03-23 Update pi_transceiver_Hat Kicad to all copper layers
    Changed to all copper layers on vias
    [pi_transceiver_hat-B_Cu.gbl, pi_transceiver_hat-B_Mask.gbs, pi_transceiver_hat-B_Paste.gbp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]
2022-10-04 Added BOM to hat
    [pi_transceiver_hat.csv]
2022-10-31 Added PA board Kicad files
    [1050170001.stp, BM02B-SRSS-TB.STEP, BM03B-SRSS-TB.STEP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]
2022-11-09 PCB updates and gerbers
    [PA_Power.kicad_sch, PA_Protection.kicad_sch, PA_RF.kicad_sch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]
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2023-01-02 Update Kicad Schematic and PCB
    Fixed: D8 was reversed, Q2 wrong footprint.
    Some component values added or changed
    Documentation added
    [PA_Power.kicad_sch, PA_Protection.kicad_sch, PA_RF.kicad_sch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]
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2023-01-02 Add boards files to Add Pi_Tx_PA
    Add Arduino boards file and variant for Pi_Tx_PA processor
    [itsybitsy_m0.cfg]
2023-01-06 Add PA Board tests
    Add PA Board Arduino Tests
    [PA_Power.kicad_sch, PA_Protection.kicad_sch, PA_RF.kicad_sch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]
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2023-10-30 Add fikter design files
    [145MHz BPF DesignV3.xlsx]
2023-10-30 Filter
    Filter values entered
    [BPF.kicad_sch, RXLNA.kicad_sch]
2023-10-30 Add values
    [LNA.kicad_sch, PIN_SW.kicad_sch, RXLNA.kicad_sch]
2023-11-03 Merge branch 'main' of https://github.com/M0LTE/pi-transceiver
    Addition of PA Board version 2 Kicad files
    [1050170001.stp, BM02B-SRSS-TB.STEP, BM03B-SRSS-TB.STEP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]
2023-11-08 Revert "Update RXLNA.kicad_prl"
    This reverts commit 634b977b9084e2730dbfc21feeff49dd8c106538.
2023-11-08 Change L construction
    [145MHz BPF DesignV3.xlsx]
2023-11-09 Capacitor updates
    Updated series capacitor preferred values
    [145MHz BPF DesignV3.xlsx]
2023-11-09 Update preferred capacitors
    [145MHz BPF DesignV3.xlsx]
2023-11-10 Sorted filter cap calculation algorithm
    [145MHz BPF DesignV3.xlsx]
2023-11-11 Update 145MHz BPF DesignV3.xlsx
    [145MHz BPF DesignV3.xlsx]
2023-11-11 Add old version
    Debug simulation
    [145MHz BPF DesignV3 - Copy.xlsx]
2023-11-11 Differences for sim
    [.sch, 145MHz BPF DesignV3.sch]
2023-11-11 Debug sim
    [145MHz BPF DesignV3 - Copy.sch]
2023-11-11 Create 145MHz BPF DesignV3Test1.sch
    [145MHz BPF DesignV3Test1.sch]
2023-11-11 Create Filter PI.sch
    [Filter PI.sch]
2023-11-11 Revert "Create Filter PI.sch"
    This reverts commit 1df28eb7800bb939fc74a075d446743f0429498f.
    [Filter PI.sch]
2023-11-11 Tidy up simulation files
    [145MHz BPF DesignV3 - Copy.xlsx, 145MHz BPF DesignV3.sch, 145MHz BPF DesignV3Test1.sch]
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2023-11-13 Update values
    [BPF.kicad_sch, LNA.kicad_sch, PIN_SW.kicad_sch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]
2023-11-13 Update
    Schematic values
    Add some Data sheets
    [LNA.kicad_sch, RXLNA.kicad_sch]
2023-11-15 Control definition
    Various updates and new Software interface description
    [PIN_SW.kicad_sch, RXLNA.kicad_sch]
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2023-12-09 Various changes to Filter Design
    [145MHz BPF DesignV3.xlsx, 145MHz BPF DesignV4.sch, 145MHz BPF DesignV5.sch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]
2023-12-09 Updated simulation
    [LNA_match.sch]
2024-01-07 Add Arduino code for V2 PA Board
    New boards.txt and variants folder
    New test code for fan and new features
    [itsybitsy_m0.cfg]
2024-01-07 Update PA board V2 Kicad files
    New schematic, PCB, and footprints
    [BOM-Pi_TX_35W_PA_V2.csv, PA_Power_V2.kicad_sch, PA_Protection_V2.kicad_sch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]
2024-01-07 Save unlocked Kicad files for PA Board V2
    [PA_RF_V2.kicad_sch, Pi_TX_35W_PA_V2.kicad_pcb]
2024-03-22 Repair
    Fix Github commit problem
    [BPF.kicad_sch, LNA.kicad_sch, PIN_SW.kicad_sch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]
2024-04-11 Update Kicad files
    [BOM-LPF_Relay.csv, DRV8860.kicad_pcb, DRV8860.kicad_sch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]
2024-04-12 Update Arduino documentation and change to Kicad V8
    [PA_Power_V2.kicad_sch, PA_Protection_V2.kicad_sch, PA_RF_V2.kicad_sch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]
2024-11-24 Updates in electronics bits and bobs
    [1.3 TFT IPS.stp, 3214G.stp, 3314G1.stp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]
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
